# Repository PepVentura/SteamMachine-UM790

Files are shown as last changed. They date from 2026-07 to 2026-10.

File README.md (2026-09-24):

# SteamMachine-UM790
Proyecto de Steam Machine casera funcional
Diseño de carcasa 3D personalizada para convertir un mini PC **Minisforum UM790** en una Steam Machine compacta orientada a gaming, emulación y uso multimedia.

Proyecto desarrollado en **OpenSCAD**, con piezas preparadas para impresión 3D. Incluye también el firmware del ESP32 y el software que corre en el mini PC.

> 👉 **¿Quieres montarlo tú mismo?** Empieza por [`GUIA_INICIO.md`](GUIA_INICIO.md) — guía completa paso a paso, sin conocimientos previos necesarios.

---

## 📷 Galería

Renders reales generados directamente desde el diseño paramétrico
actual del proyecto (OpenSCAD), no maquetas ni imágenes genéricas —
se regeneran cada vez que cambia el CAD, así que siempre reflejan el
estado real de las piezas.

### Carcasa montada, con distintos anagramas de panel NFC

| Steam | RetroBat | En blanco |
|---|---|---|
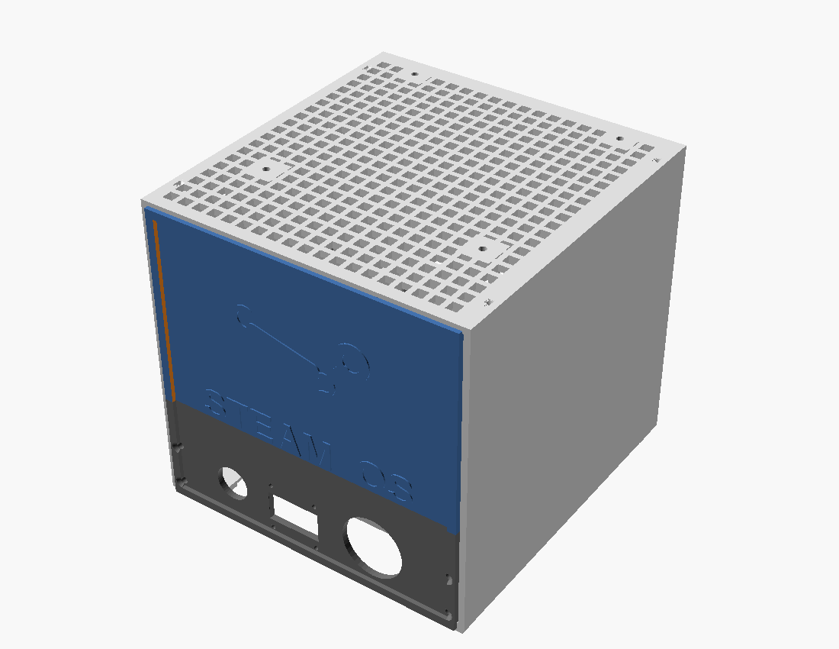
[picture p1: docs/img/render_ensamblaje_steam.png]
Ensamblaje con panel Steam
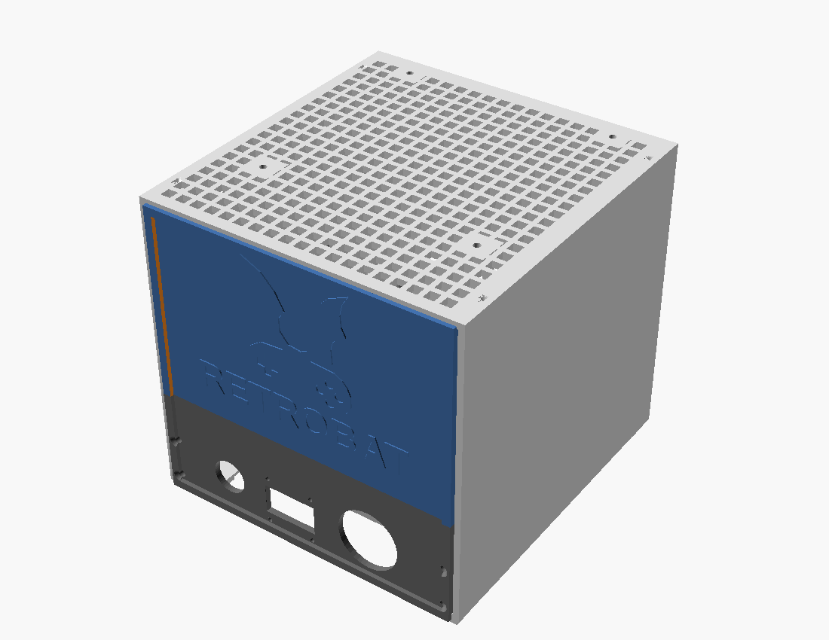
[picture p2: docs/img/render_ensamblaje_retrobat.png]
Ensamblaje con panel RetroBat
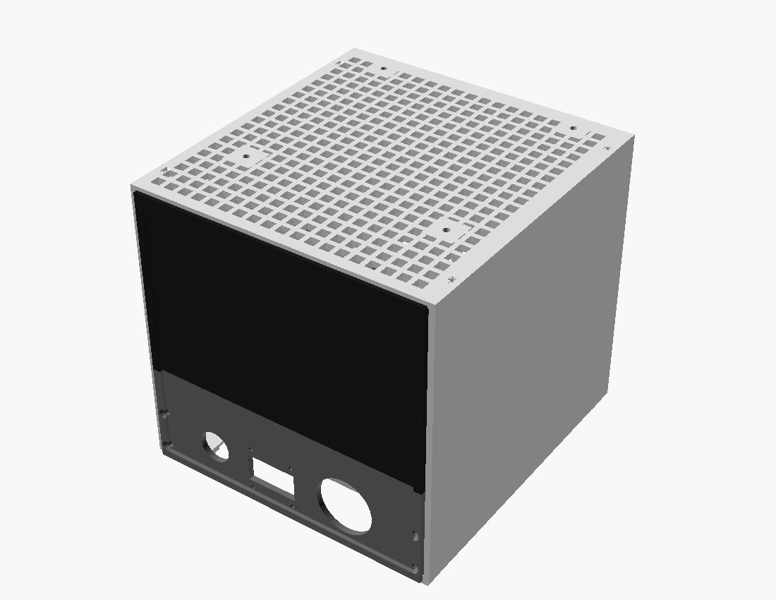
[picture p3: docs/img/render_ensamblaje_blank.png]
Ensamblaje con panel en blanco
|  |  |  |

El panel NFC frontal es intercambiable — el ensamblaje es siempre el
mismo, solo cambia la pieza pequeña con el anagrama (ver `openscad/parts/03_panels/nfc_panel_*.scad`
y el sistema de impresión en dos piezas de `STL/Anagramas/`). El
anagrama del panel Zombies (`STL/Anagramas/Gung.stl`) todavía no tiene
un `.scad` paramétrico propio como los de arriba —está modelado
directamente como STL suelto—, así que de momento no aparece en este
render conjunto.

### Piezas por separado

| Chasis | Panel superior (rejilla) |
|---|---|
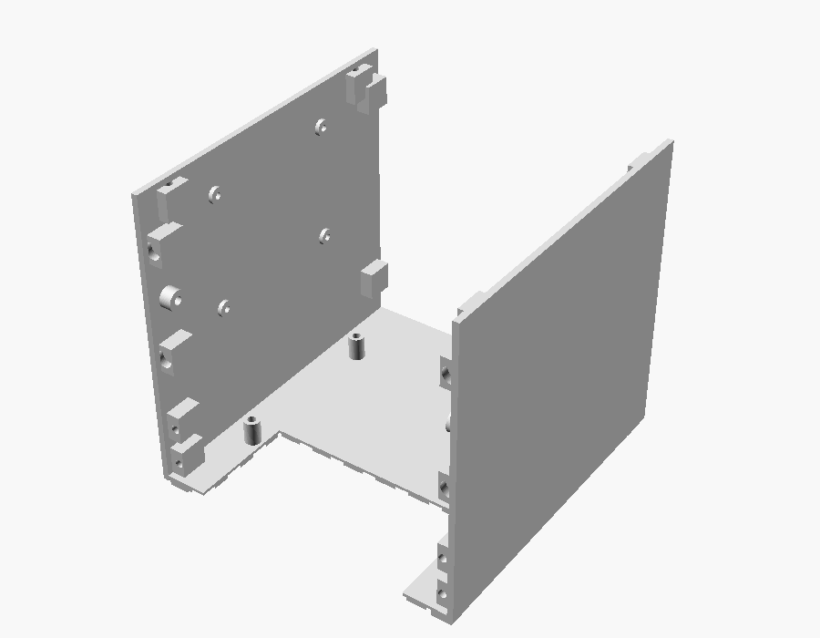
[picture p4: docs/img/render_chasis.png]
Chasis
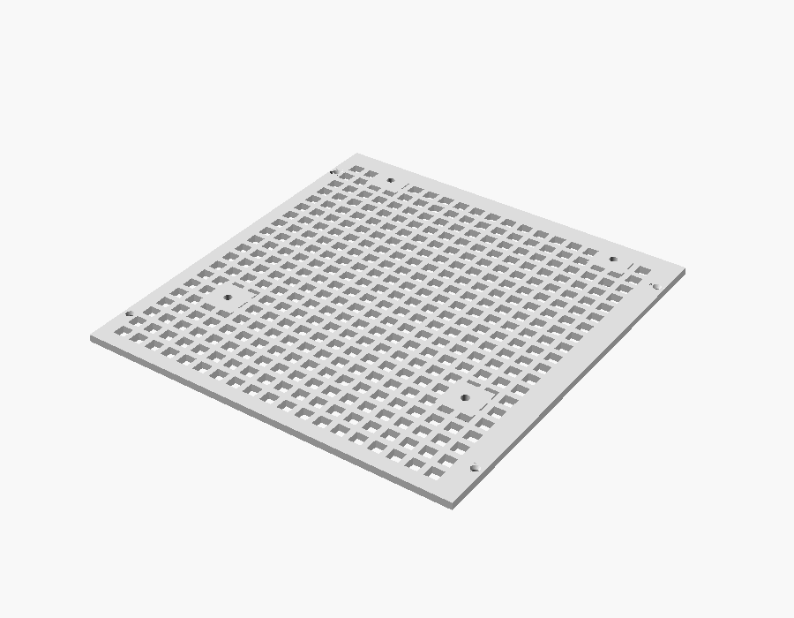
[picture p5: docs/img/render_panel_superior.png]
Panel superior
|  |  |

| Panel inferior (frontal, con OLED/botón/USB) | Panel trasero |
|---|---|
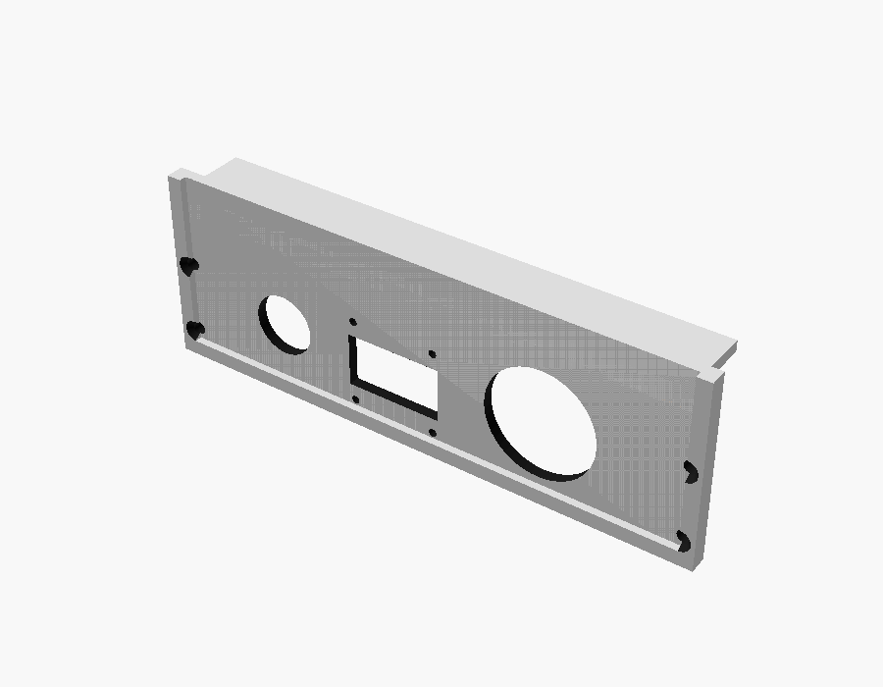
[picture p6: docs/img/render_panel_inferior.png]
Panel inferior
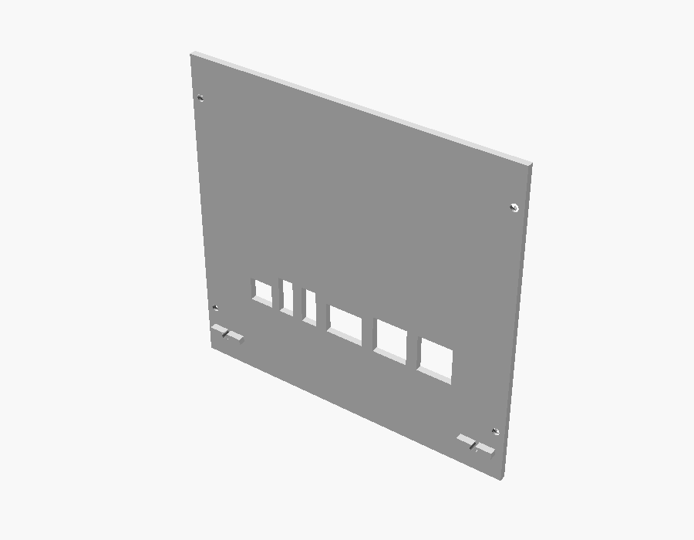
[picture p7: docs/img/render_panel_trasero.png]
Panel trasero
|  |  |

| Bandeja interior |
|---|
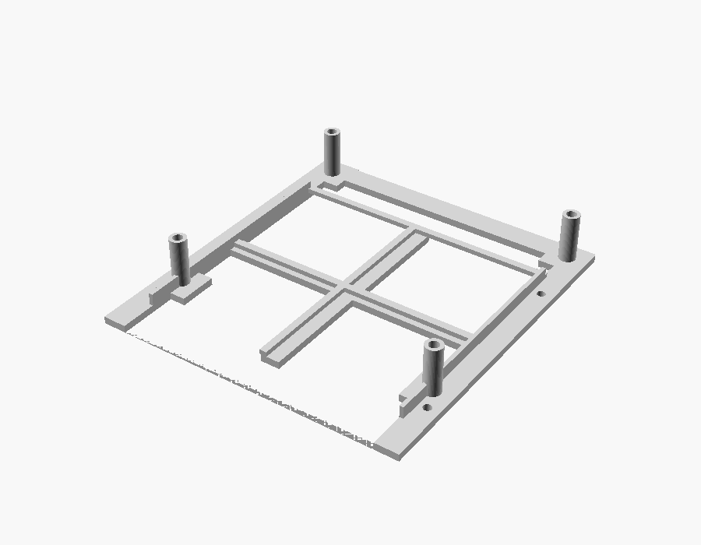
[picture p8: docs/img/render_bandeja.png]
Bandeja
|  |

---

## 📌 Características

- Carcasa modular diseñada específicamente para UM790.
- Diseño paramétrico en OpenSCAD.
- Piezas separadas para facilitar la impresión.
- Optimizada para impresoras FDM.
- Preparada para montaje con tornillería estándar.
- Ventilación integrada para mantener temperaturas adecuadas.
- Diseño orientado a estética tipo consola Steam Machine.
- Sistema de paneles frontales intercambiables.
- Identificación NFC para cambio de modo.
- Panel NFC **Apagar**: apagado ordenado del equipo (evita cortar la corriente de golpe).
- Caja con tapa para guardar los paneles NFC cuando no están puestos.
- Diseño preparado para expansión con nuevos paneles.

## 🎮 Sistema de paneles frontales NFC

Uno de los elementos principales del diseño es el sistema de paneles frontales intercambiables mediante identificación NFC.

La carcasa permite utilizar diferentes paneles frontales personalizados, cada uno asociado a una función, sistema o configuración concreta mediante etiquetas NFC integradas.

### Funcionamiento

Cada panel frontal incorpora:

- Un diseño físico específico según la temática.
- Una etiqueta NFC integrada en el propio panel.
- Identificación automática al acercar el dispositivo lector NFC.
- Posibilidad de lanzar diferentes configuraciones o aplicaciones según el panel utilizado.

Ejemplos de uso:

- 🎮 Panel Steam Machine → inicia Steam Big Picture.
- 🕹️ Panel Arcade → inicia RetroDECK / RetroArch.
- 🧟 Panel Zombies → THE HOUSE OF THE DEAD: Remake / THE HOUSE OF THE
  DEAD 2: Remake (nativos de Steam vía Proton — pensado para jugarse
  con Wiimote como pistola, integración pendiente).
- ⚙️ Panel Configuración → acceso a herramientas del sistema.
- 🎵 Panel Multimedia → reproducción multimedia.
- ⏻ Panel Apagar → apaga el equipo de forma ordenada (ver más abajo).

---

## 🔌 Integración NFC

El sistema está pensado para trabajar con un lector NFC conectado al equipo.

Flujo de funcionamiento:

Las etiquetas NFC pueden programarse para ejecutar diferentes acciones:

- Abrir aplicaciones.
- Ejecutar scripts.
- Cambiar perfiles.
- Lanzar emuladores.
- Seleccionar diferentes modos de uso.

---

## ⏻ Apagado ordenado con el panel Apagar

Cortar la corriente de golpe puede dejar Bazzite sin arrancar (por
ejemplo, en el prompt `grub>`; ver [`GUIA_INICIO.md`](GUIA_INICIO.md),
solución de problemas). Para evitarlo hay un panel **Apagar**: se coloca como
cualquier otro y, al pulsar el botón, el equipo se apaga con
`systemctl poweroff` (systemd cierra servicios y desmonta discos antes
de cortar).

1. Coloca el panel Apagar → la OLED muestra `APAGAR EQUIPO` y los LEDs
   se ponen rojos. **Todavía no se ha apagado nada.**
2. Pulsa el botón → la OLED pasa a `Apagando...`, los LEDs se
   funden a negro y el equipo se apaga en unos segundos.

Son dos gestos a propósito: un roce del tag no apaga la máquina. Si el
sistema rechaza el apagado (p. ej. una actualización en curso), la OLED
muestra `Error al apagar` y el equipo sigue encendido. Detalles en
[`docs/12_Profile_System.md`](docs/12_Profile_System.md).

---

## 🧩 Diseño modular

Los paneles frontales están diseñados para poder sustituirse fácilmente:

- Sistema de fijación común.
- Compatibilidad con futuros diseños.
- Personalización mediante impresión 3D.
- Posibilidad de crear paneles temáticos.

El objetivo es que la SteamMachine pueda cambiar de función simplemente sustituyendo el panel frontal.

---

## 🖨️ Impresión 3D

### Impresora recomendada

Compatible con:

- Anycubic Kobra X
- Impresoras FDM con volumen similar

### Material: PETG

**Todas las piezas se imprimen en PETG.** El PLA (incluido el PLA+) se
deforma con la temperatura: la carcasa envuelve un mini PC que expulsa
aire caliente y el PLA se ablanda alrededor de los 55-60 °C, mientras
que el PETG aguanta hasta unos 70-80 °C (valores orientativos; varían
según la marca de filamento). Con PLA se ha comprobado que las piezas
se deforman en uso real.

- **PETG**: todas las piezas de la carcasa, los paneles frontales y los
  soportes. La caja de paneles NFC (`docs/14_Caja_Paneles_NFC.md`) no
  recibe calor de la máquina, así que PLA sería válido para ella, pero
  se recomienda PETG por coherencia.
- **PLA / PLA+**: solo para pruebas rápidas de encaje. No dejes una
  pieza de PLA montada dentro del equipo.
- **ABS/ASA**: opcional, si quieres más margen térmico todavía (más
  difícil de imprimir: cerramiento y ventilación).
- **Piezas a dos filamentos** (panel inferior, difusor LED translúcido):
  los dos filamentos deben ser PETG. Mezclar PLA y PETG en la misma
  pieza da una unión mala entre capas.
- **Anagramas pegados con Loctite**: el cianoacrilato agarra algo peor
  sobre PETG que sobre PLA. Lija ligeramente las dos caras, desengrasa
  con alcohol isopropílico y pega; si aun así se despega, usa epoxi
  de 5 minutos.
- Las holguras y encajes del diseño se ajustaron con PLA+. Con PETG
  revisa los encajes antes de montar (ver `docs/14_Caja_Paneles_NFC.md`
  para la caja y la tapa).

### Parámetros orientativos

- Altura de capa: 0,20 mm
- Paredes: 3-4 perímetros
- Relleno: 15-30 %
- Soportes: según pieza
- Temperaturas típicas de PETG: boquilla 230-250 °C, cama 70-85 °C,
  ventilador de capa bajo (30-50 %). Parte del perfil PETG de tu
  marca de filamento y ajusta; los puentes salen algo peor que en PLA.

---

## 📂 Estructura del proyecto

```
SteamMachine-UM790/
│
├── GUIA_INICIO.md          Guía paso a paso para montarlo todo, de cero
├── CHANGELOG.md            Historial completo de decisiones de diseño
│
├── openscad/               Diseño 3D paramétrico
│   ├── parts/               Piezas por imprimir (chasis, paneles...)
│   └── reference/            Componentes y posiciones del ensamblaje
├── STL/                    STL listos para imprimir
│   ├── caja_nfc_panel_*.stl  Caja + tapa para guardar los paneles NFC
│   └── Anagramas/            Panel NFC en blanco + anagramas sueltos,
│                              para imprimir por separado y pegar con
│                              Loctite (reduce el tiempo de impresión
│                              de ~6h a ~1h frente a la pieza única)
│
├── firmware/                Firmware del ESP32 (C++, PlatformIO)
├── software/                 Core en Python — corre en el mini PC
│
├── Hardware/                 Conexiones eléctricas y cableado
└── docs/                     Documentación técnica detallada (01 a 14)
```

---

## 🛠️ Software utilizado

- OpenSCAD  
  https://openscad.org/

- Cura / OrcaSlicer / PrusaSlicer para laminado.
- PlatformIO (VS Code) para el firmware del ESP32.
- Python 3 para el Core que corre en el mini PC.

---

## ⚙️ Personalización

El diseño utiliza parámetros editables para modificar:

- Dimensiones generales.
- Posición del equipo.
- Grosor de paredes.
- Ventilación.
- Anclajes.
- Compatibilidad con diferentes accesorios.

Archivo principal: `openscad/00_parametros.scad`

---

## 🚀 Estado del proyecto

🟢 Hardware montado y en pruebas

### Completado

- [x] Diseño mecánico completo (carcasa, paneles, canal LED, fijación OLED).
- [x] Hardware montado (ESP32, RC522, OLED, barra LED, HUB USB).
- [x] Firmware del ESP32 escrito, compilado y flasheado en hardware real.
- [x] Software Core (Python) escrito, con tests unitarios.
- [x] Probado en hardware real: lectura NFC, barra LED, pulsador frontal, pantalla OLED, recuperación tras reinicio del ESP32.
- [x] Core (Python) probado de extremo a extremo contra el ESP32 real: detecta panel, reacciona OLED/LEDs y responde al botón lanzando la plataforma correspondiente.
- [x] Guía de inicio completa para montarlo desde cero (`GUIA_INICIO.md`).
- [x] Panel NFC **Apagar** (apagado ordenado, `docs/12_Profile_System.md`): implementado en el Core con tests; anagrama `STL/Anagramas/Apagar.stl`.
- [x] Caja con tapa para guardar hasta 6 paneles NFC (`docs/14_Caja_Paneles_NFC.md`).
- [x] Publicación de STL definitivos actualizados (incluye `STL/Anagramas/` — panel en blanco + anagramas sueltos para pegar con Loctite).

### Pendiente

- [ ] Panel Apagar: escribir el tag NFC, poner su UID real en `software/config/panel_database.json` (ahora `UID_APAGAR_PENDIENTE`) y probar el apagado en el hardware real (`docs/10_Test_Plan.md`, T065).
- [ ] Reimprimir en PETG las piezas que estén en PLA y validar la temperatura tras 24 h (`docs/10_Test_Plan.md`, T022).
- [ ] Wiimote como pistola para el panel Zombies (Bluetooth + barra de sensor IR).
- [ ] UID de tag NFC real para el panel Zombies - HOTD 2 Remake.

Ver `docs/10_Test_Plan.md` para el detalle de cada prueba realizada, y
`docs/06_Development_Roadmap.md` para el estado por fases.

---

## 🤝 Contribuciones

Las mejoras, modificaciones y sugerencias son bienvenidas.

Si realizas una modificación o adaptación, puedes abrir un Pull Request.

---

## Autor

Pep Ventura

Proyecto creado para uso personal y compartido con la comunidad maker.

## Licencia

Este proyecto está bajo la **Licencia MIT**. Esto significa que puedes usar, modificar y distribuir el código libremente, incluso para fines comerciales. 

Para más detalles, consulta el archivo [LICENSE](LICENSE) incluido en este repositorio.

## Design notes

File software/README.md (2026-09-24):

# SteamMachine Software Core v0.2

Aplicacion Python que corre en el mini PC (Bazzite) y coordina el ESP32
(paneles NFC + boton + OLED + LEDs) con el lanzador de plataformas
(Steam, RetroDECK, RetroArch, y el panel de zombies/disparos con THE
HOUSE OF THE DEAD: Remake y THE HOUSE OF THE DEAD 2: Remake, ambos
nativos de Steam via Proton) y, con el panel Apagar, apaga el equipo de
forma ordenada. Arquitectura y protocolo: ver `docs/03`,
`docs/04`, `docs/05`, `docs/08` en la raiz del repo.

## Instalar

```bash
cd software
python3 -m venv .venv
source .venv/bin/activate
pip install -r requirements.txt
```

## Ejecutar con el ESP32 real (hardware ya montado)

`config/config.json` tiene `"serial.simulate": false` por defecto: al
arrancar busca el ESP32 automaticamente por VID:PID (`"port": "auto"`).

```bash
python main.py
```

Si no lo encuentra, localiza el puerto a mano en Bazzite:

```bash
ls /dev/serial/by-id/     # busca algo como usb-1a86_USB_Serial-if00-port0
```

y ponlo explicitamente en `config/config.json`:

```json
"serial": { "port": "/dev/ttyUSB0", "simulate": false }
```

Antes de dar por buena una sesion con hardware real, sigue el checklist
de `firmware/README.md` ("Prueba de integracion") para confirmar que el
propio firmware responde bien por su cuenta.

Con `"simulate": false` el Core espera al ESP32 real: si no esta
conectado o no responde con `boot`, veras avisos de reconexion en el
log (`logs/steammachine.log`) cada `serial.reconnect_interval_seconds`.

## Ejecutar en modo simulado (sin ESP32, para desarrollo)

Util para tocar la logica del Core sin depender del hardware. Pon
`"serial.simulate": true` en `config/config.json` y ejecuta `python
main.py`: se abre una consola interactiva.

```
sim> 04A1C8B2      # simula "colocar panel Steam"
sim> b             # simula pulsar el boton -> lanza Steam
sim> r             # simula "retirar panel"
sim> q             # salir
```

Los UID de ejemplo (Steam / RetroDECK / Zombies-HOTD Remake /
Zombies-HOTD 2 Remake) estan en `config/panel_database.json` — si tus
tags reales tienen otros UID, actualiza ese fichero con los que
reporte el firmware al leerlos (ver el checklist de
`firmware/README.md`). El UID del panel de HOTD 2 Remake
(`0AAABBCC`) es un placeholder: sustituyelo por el UID real en cuanto
tengas un segundo tag/panel fisico asignado a ese juego; hasta
entonces, el panel de zombies (`04C3EAD4`) lanza HOTD Remake.

## Panel Apagar (apagado ordenado)

El perfil `APAGAR` (`config/profiles/apagar.json`, `"action": "poweroff"`)
apaga el mini PC con `systemctl poweroff` al pulsar el boton con el panel
puesto (`core/power_manager.py`). El comando se puede cambiar en
`config/config.json`:

```json
"power": { "poweroff_command": ["systemctl", "poweroff"] }
```

- **Sin sudo**: en la sesion grafica local activa (la del servicio de
  usuario `steammachine.service`) polkit permite apagar sin contrasena.
  Compruebalo una vez a mano con `systemctl poweroff`.
- Si el sistema rechaza el apagado (p. ej. bloqueo por una actualizacion
  de Bazzite; `systemd-inhibit --list` muestra quien bloquea), la OLED
  muestra `Error al apagar` y el motivo queda en el log.
- **Modo simulado (`serial.simulate: true`)**: el apagado NUNCA se
  ejecuta, solo se registra (`SIMULACION: apagado solicitado pero NO
  ejecutado`). Asi teclear el UID del panel Apagar en la consola de
  simulacion no apaga tu maquina de desarrollo.
- La entrada del panel en `panel_database.json` se llama
  `UID_APAGAR_PENDIENTE`: sustituyela por el UID real del tag. Debe
  conservar `"profile": "APAGAR"`; sin el perfil el boton no hace nada.
- Mientras dura el apagado el Core ignora paneles, boton y AUTO, para que
  retirar el panel no deshaga el aviso `Apagando...`.

## Arranque automático (systemd)

Para que el Core arranque solo con la sesión gráfica de Bazzite, sin
tener que abrir una terminal cada vez (pensado para el uso "aparato",
incluida la segunda residencia):

```bash
mkdir -p ~/.config/systemd/user
cp steammachine.service ~/.config/systemd/user/
systemctl --user daemon-reload
systemctl --user enable --now steammachine.service
```

Comprobar estado y logs:

```bash
systemctl --user status steammachine.service
journalctl --user -u steammachine.service -f
```

`steammachine.service` reinicia el Core solo si se cae (`Restart=on-failure`)
y espera a que el escritorio gráfico esté listo antes de arrancar. Editar
`ExecStart`/`WorkingDirectory` si tu ruta de instalación no es `~/SteamMachine-UM790/software`.

## Tests

```bash
pip install -r requirements-dev.txt
pytest
```

Cubren `LEDManager` y `OLEDManager` (comandos directos, `flash`/`fade` y su
cancelacion mutua, y la aproximacion de `sleep`/`wake`), `Application`
(logica de los eventos del protocolo — tag, tag_removed, button — con
`OLEDManager`/`LEDManager`/`Launcher`/`PanelDatabase` sustituidos por
dobles), `PanelDatabase` (carga/guardado, JSON malformado, mayus/minus
en el UID) `PowerManager` (apagado ordenado: exito, rechazo del sistema, comando
inexistente, timeout, `dry_run` — con procesos `python -c` en vez de
`systemctl poweroff`, que apagaria la maquina de los tests), el flujo
APAGAR de `Application` y `Launcher`/`BasePlugin` (lanzar, parar y consultar estado
de procesos reales de corta duracion — se usa `python -c "..."` en vez
de steam/flatpak/lutris, que no estan instalados en este entorno).

Todo con dobles (`tests/fakes.py`) o ficheros temporales — no hace falta
hardware, ESP32 ni las plataformas reales para correrlos.

## Estructura

```
core/        Application, ConfigurationManager, EventManager, logger,
             ProfileManager (config/profiles/*.json), ProcessWatcher
             (detección de perfil AUTO por proceso en ejecución),
             PowerManager (apagado ordenado, panel APAGAR)
devices/     SerialManager (real) / SimulatedSerialManager, ESP32Controller
database/    PanelDatabase (config/panel_database.json)
launcher/    BasePlugin + SteamPlugin, RetroDeckPlugin, RetroArchPlugin,
             HotdRemakePlugin, Hotd2RemakePlugin
status/      StatusManager (registro), BaseStatusProvider, SystemStatsProvider
             (CPU/RAM vía psutil — usado por el perfil MAINTENANCE)
config/      config.json, panel_database.json, profiles/*.json
```

## Pendiente

- Validar con hardware real (ver checklist en `firmware/README.md`,
  "Prueba de integración") — todo lo de arriba está probado con el
  ESP32 simulado, no con el físico.
- Panel Apagar: poner el UID real de su tag (ahora `UID_APAGAR_PENDIENTE`)
  y probar el apagado en el hardware real — solo esta probado con el
  ESP32 simulado y con tests, no con `systemctl poweroff` real.
- Actualizar `config/panel_database.json` con los UID reales de tus
  tags NFC en cuanto los leas del firmware (ahora mismo tiene UID de
  ejemplo).
- Persistir `_pending_panel` no es necesario (se resetea con cada tag),
  pero si se añade reconexion en caliente conviene revisar ese estado.
- Zumbador y actualizaciones OTA: sin implementar todavía (ver roadmap,
  Fase 10).
- Wiimote como lightgun (Bluetooth + barra de sensor IR) para el panel
  de zombies: pospuesto, sin implementar todavía. Los juegos (HOTD
  Remake / HOTD 2 Remake) ya funcionan con raton normal mientras tanto.

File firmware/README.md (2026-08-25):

# SteamMachine UM790 - Firmware ESP32

Firmware para el ESP32-WROOM-32D DevKit (HW-394) que controla el RC522,
la OLED, la barra LED y el pulsador, y habla el protocolo JSON de
`docs/04_Communication_Protocol.md` con el Core (`software/`).
Arquitectura: `docs/05_Firmware_Architecture.md`.

> **Validado en hardware real**: compila (con `fastled/FastLED` fijado
> a `3.7.8` en `platformio.ini` — versiones más recientes tienen un
> fallo de compilación conocido, ver "Solución de problemas" en
> `GUIA_INICIO.md`), flashea y arranca correctamente en un
> ESP32-WROOM-32D DevKit real; el evento `boot` se confirmó por
> monitor serie. Pendiente de validar el RC522, la OLED, la barra LED
> y el pulsador con el cableado completo (ver checklist más abajo).

## Compilar y flashear

Requiere [PlatformIO](https://platformio.org/) (extension de VSCode o CLI):

```bash
cd firmware
pio run                # compila
pio run --target upload -e esp32doit-devkit-v1   # flashea (con el ESP32 en modo bootloader si hace falta)
pio device monitor -b 115200                       # monitor Serial (protocolo JSON; ver nota abajo)
```

> Ojo: `pio device monitor` te va a mostrar el trafico JSON crudo del
> protocolo, no logs de depuracion (esos van por Serial2, ver mas abajo).

## Depuracion

`Serial` (USB) esta reservado en exclusiva para el protocolo con el PC.
Los logs de depuracion van por `Serial2` (pines 16/17 por defecto,
`config.h`), y solo se compilan si activas el flag:

```ini
build_flags = -DDEBUG_SERIAL2=1
```

en `platformio.ini`. Con un adaptador USB-serie en los pines 16/17
puedes ver los logs sin tocar el canal del protocolo.

## Pinout (fijado por el diseño electrónico)

`docs/07_Hardware_Specification.md` no fijaba GPIOs, así que la
asignación real vive en `src/config.h`. El resto de GPIO del
ESP32-WROOM-32D DevKit quedan reservados sin usar todavía.

| Función | Pin(es) |
|---|---|
| RC522 SDA/SS | GPIO5 |
| RC522 SCK | GPIO18 |
| RC522 MISO | GPIO19 |
| RC522 MOSI | GPIO23 |
| RC522 RST | GPIO27 |
| OLED SDA | GPIO21 |
| OLED SCL | GPIO22 |
| Barra LED (WS2812B, directa sin nivelador) | GPIO25 (`LED_COUNT` a ajustar) |
| Pulsador | GPIO13 (confirmado en hardware real, 2026-08-25) |
| Zumbador (futuro) | GPIO26 (provisional — no fijado en el diseño electrónico) |
| Debug Serial2 | RX 16, TX 17 (provisional) |

**Alimentación:**

| Riel | Alimenta |
|---|---|
| 3V3 | RC522 + OLED |
| VIN (~4.68V)  | WS2812B |
| GND | masa común |

El dato de la barra LED sale del ESP32 en 3.3V (GPIO25) y va **directo**
a la WS2812B, sin nivelador — el diseño original preveía un 74AHCT125
(3.3V→5V) de por medio, pero se retiró (2026-08-25) tras comprobar en
un tramo real de 8 LEDs que la tira funciona bien sin él: con el chip
en el circuito no encendía nada (causa más probable: el pin /1OE
flotante), y conectado directo sí. Ver
`Hardware/Hardware_Connections.md` para el historial completo de este
diagnóstico.

Los únicos pines que aún no vienen confirmados en hardware real son el
zumbador y el UART de depuración; están marcados como "provisional" en
`config.h` — confírmalos o cámbialos cuando lo tengas claro.

**Cable y código de colores** (ver `docs/07_Hardware_Specification.md`,
sección "Cableado"): 22 AWG / 0,32 mm², cobre estañado, aislamiento de
silicona. Rojo = +5V, Negro = GND, Amarillo = datos/señales, Azul =
SPI (RC522), Verde = I²C (OLED).

## Estructura

Sigue exactamente `docs/05_Firmware_Architecture.md`:

```
src/
  main.cpp
  config.h
  core/            Application (orquesta todo), EventQueue
  hardware/        rc522, oled, leds, button (un modulo = una responsabilidad)
  communication/    serial_protocol (transporte), json_parser (parseo de comandos)
  services/        animations (motor no bloqueante), diagnostics, watchdog
  utils/           logger (Serial2), timers (Every, basado en millis())
```

## Animaciones

`services/animations.h` implementa los 7 nombres de `docs/04`
(idle, loading, launch, rainbow, error, success, shutdown) como
funciones de un frame cada una, llamadas sin bloquear desde el loop
principal. Un comando `led` (color sólido) o `brightness` cancela
cualquier animación en curso, igual que en el Core (`LEDManager.set_color`
en `software/devices/led_manager.py`).

## Pendiente / no cubierto todavía

- Zumbador (`cmd: beep`): el comando se parsea y no da error, pero no
  hace nada hasta que exista el hardware.
- Sin tests automáticos (el firmware depende de librerías de hardware
  reales — RC522, OLED, FastLED — difíciles de mockear sin más
  infraestructura; se podría plantear un entorno `pio test` nativo con
  dobles de esas librerías si interesa más adelante).
- Compilación, flasheo y arranque ya validados en hardware real
  (ver aviso arriba); pendiente de validar RC522, OLED, LEDs y pulsador
  con el cableado completo.

## Prueba de integración (primera vez con hardware real)

Con el cableado ya montado, antes de dar por buena la Fase 9 del roadmap:

1. `pio run` — compila. ✔ Validado en un ESP32-WROOM-32D DevKit real.
2. `pio run --target upload -e esp32doit-devkit-v1` — flashea el ESP32. ✔ Validado.
3. `pio device monitor -b 115200` — tras el ruido propio del arranque
   del ESP32 (líneas tipo `ets Jul 29 2019...`), deberías ver
   `{"event":"boot","firmware":"1.0.0"}`. ✔ Validado. Si además ves
   `{"event":"error","code":1}`, el RC522 todavía no responde — normal
   si no está cableado aún, revisar pinout si ya lo está.
4. Acerca un tag NFC al RC522 → debería aparecer `{"event":"tag","uid":"..."}`
   con un UID de 8 caracteres hex. Retíralo → `{"event":"tag_removed"}`. ✔ Validado.
5. Pulsa el botón → `{"event":"button"}`. ✔ Validado (GPIO13).
6. Desde el mismo monitor, escribe a mano una línea y pulsa Enter para
   probar los comandos PC→ESP32, por ejemplo:
   `{"cmd":"oled","text":"Hola"}` (debe aparecer en la pantalla) ✔ Validado,
   `{"cmd":"led","color":"#00FF00"}` (la barra debe ponerse verde) ✔ Validado (8 LEDs, directo sin nivelador),
   `{"cmd":"animation","name":"rainbow"}`.
7. Solo cuando 3-6 funcionen, pasa a probar con el Core real: en
   `software/config/config.json` pon `"simulate": false` y sigue las
   instrucciones de `software/README.md` para localizar el puerto serie.

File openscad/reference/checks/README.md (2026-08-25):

# Verificación de colisiones — Ensamblaje virtual v1

Comprueba automáticamente, componente contra componente, si los
volúmenes mecánicos del ensamblaje virtual (`virtual_assembly_v1.scad`)
colisionan entre sí.

## Cómo funciona

Para cada par de componentes se calcula `intersection(A, B)` en
OpenSCAD y se exporta el resultado a STL:

- Si el STL resultante está **vacío** → los volúmenes no se tocan →
  **sin colisión**.
- Si el STL contiene triángulos → los volúmenes se solapan
  físicamente → **colisión real**.

Se comprueban dos niveles:

1. **Cuerpos mecánicos rígidos** (`*InstanceBody`): cualquier
   intersección aquí es un fallo bloqueante — dos piezas físicas no
   pueden ocupar el mismo espacio.
2. **Volúmenes de seguridad / cableado** (`*InstanceKeepout`) contra
   cuerpos de *otros* componentes: es un aviso informativo, no un
   fallo. Indica que conviene revisar cómo se enruta el cableado en
   ese punto, no que dos piezas sólidas choquen.

Ambas comprobaciones usan las mismas posiciones que el ensamblaje
visual (`openscad/reference/components/assembly_positions.scad` y
`assembly_instances.scad`), así que el resultado del render y el de
la comprobación son siempre coherentes entre sí.

## Uso

```bash
cd openscad/reference/checks
python3 run_collision_checks.py
```

Requiere el binario `openscad` en el `PATH`. Los archivos `.scad` y
`.stl` intermedios se generan en `_generated/` (no se versionan, ver
`.gitignore`).

## Último resultado conocido

Ver `docs/Virtual_Assembly_Report.md` para el resultado de la
última ejecución y su interpretación.

## Añadir un componente nuevo

1. Crear su módulo en `openscad/reference/components/`.
2. Añadir su posición a `assembly_positions.scad`.
3. Añadir su `*InstanceBody()` (y `*InstanceKeepout()` si aplica) a
   `assembly_instances.scad`.
4. Añadirlo a la lista `COMPONENTS` (y `KEEPOUTS` si aplica) en
   `run_collision_checks.py`.

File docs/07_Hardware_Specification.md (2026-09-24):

\# SteamMachine UM790

\# 07 - Hardware Specification

Version: 1.0

Status: Active

\---

\# Objetivo

Este documento recoge las especificaciones técnicas completas del hardware utilizado en el proyecto SteamMachine UM790.

Su finalidad es servir como referencia única durante el diseño mecánico, el desarrollo del firmware y el montaje final.

\---

\# 1. Equipo principal

\## Mini PC

Modelo

Minisforum UM790 Pro

Función

Equipo principal de ejecución.

\### Dimensiones mecánicas

PCB

122.0 × 119.5 mm

Altura aproximada

38 mm

Separación recomendada respecto a la base

12 mm

Sistema de fijación

4 soportes M3

\---

\# 2. Ventilación

\## Ventilador principal

Modelo

Noctua NF-A12x15 PWM chromax.black.swap

Características

120 × 120 × 15 mm

PWM 4 pines

Muy bajo nivel sonoro

Posición

Parte superior del equipo

Centrado respecto al disipador del UM790

Flujo

Entrada por la base

Salida por la tapa

\---

\# 3. Controlador

\## ESP32 Terminal Adapter

Dimensiones

78 × 63 mm

Taladros

73 × 58 mm

Tornillería

M3

Función

Control completo del frontal

\- RC522

\- OLED

\- LEDs

\- Pulsador

\- Comunicación USB Serie

\---

\# 4. Lector NFC

Modelo

MFRC522

Interfaz

SPI

Función

Lectura de paneles NFC intercambiables

Posición

Centrado horizontalmente

A media altura del panel frontal superior

El soporte pertenece al chasis, no al panel intercambiable.

\---

\# 5. Pantalla

Modelo

OLED I²C

Zona visible

27 × 27 mm

Función

Estado del sistema

Plataforma seleccionada

Mensajes

Animaciones

\---

\# 6. Pulsador

Tipo

Metálico antivandálico

Rosca

16 mm

Longitud roscada

55 mm

Montaje

Panel frontal

\---

\# 7. USB frontales

Tipo

Prolongadores USB empotrables

Diámetro del orificio

29 mm

Cantidad

2

Conexión

USB HUB interno

\---

\# 8. HUB USB

Modelo

USB 3.x de 4 puertos

Posición

Lateral interior

Conexión

UM790

↓

HUB

↓

USB frontales

\---

\# 9. Barra LED

Tipo

RGB direccionable

Control

ESP32

Funciones

Color por plataforma

Animaciones

Estado

Errores

\---

\# 10. Paneles intercambiables

Material

PETG (el PLA se deforma con la temperatura del equipo)

Sistema de fijación

Imanes de neodimio

Alojamiento NFC

Empotrado

Contenido

Logotipo en relieve

Tag NFC

\---

\# 11. Imanes

Disponibles

3 × 2 mm

6 × 2 mm

Aplicación

Panel frontal

Paneles intercambiables

\---

\# 12. Insertos roscados

Disponibles

M2

M2.5

M3

M4

M5

M6

M8

Aplicaciones

Panel trasero

Bastidor

Soportes

\---

\# 13. Tornillería prevista

M2

Electrónica

M3

ESP32

UM790

Ventilador

Bastidor

M4

Panel trasero (si fuese necesario)

\---

\# 14. Fuente de alimentación

Tipo

Externa

Ventajas

Menor temperatura interior

Más espacio disponible

Mayor facilidad de mantenimiento

\---

\# 15. Carcasa

Dimensiones exteriores

Anchura

156 mm

Profundidad

162.4 mm

Altura

148 mm

Altura total con patas

152 mm

\---

\# 16. Refrigeración

Entrada

Base

Salida

Parte superior

Ventilador

Noctua NF-A12x15

Objetivo

Mantener una circulación vertical continua.

\---

\# 17. Materiales de impresión

Material obligatorio (todas las piezas)

PETG

PLA / PLA+

Solo pruebas de encaje. No montar dentro del equipo: se ablanda a ~55-60 °C y se deforma en uso real.

ABS / ASA (opcional)

Más margen térmico, más difícil de imprimir.

Piezas a dos filamentos

Ambos filamentos en PETG.

Pegado de anagramas

El cianoacrilato agarra peor en PETG: lijar, desengrasar; epoxi si se despega.

Altura de capa

0.20 mm

Boquilla

0.4 mm

\---

\# 18. Impresora

Modelo

Anycubic Kobra X

Área útil

Suficiente para imprimir todas las piezas sin dividirlas.

\---

\# 19. Objetivos mecánicos

\- Fácil mantenimiento.

\- Cableado ordenado.

\- Buena ventilación.

\- Acceso directo al panel trasero.

\- Paneles NFC intercambiables.

\- Bastidor rígido.

\- Sin interferencias entre componentes.

\---

\# 20. Cableado

Cable 22 AWG / 0,32 mm², cobre estañado, aislamiento de silicona.

Código de colores (5 colores, para mantener el cableado organizado en
todo el montaje — especialmente entre RC522, OLED, WS2812B y ESP32):

| Color | Se reserva para |
|---|---|
| Rojo | +5V |
| Negro | GND |
| Amarillo | Datos / señales |
| Azul | SPI |
| Verde | I²C |

\---

\# 21. Estado

Especificaciones mecánicas prácticamente completas.

Este documento deberá actualizarse únicamente cuando se incorporen nuevos componentes físicos.

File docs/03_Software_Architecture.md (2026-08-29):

\# SteamMachine UM790

\# 03 - Software Architecture

Version: 1.0

Status: Draft

\---

\# 1. Objetivo

El software de SteamMachine UM790 tiene como objetivo convertir un MiniPC convencional en un sistema modular de entretenimiento controlado mediante paneles NFC intercambiables.

El usuario únicamente debe:

\- colocar un panel frontal

\- pulsar el botón

Todo el resto será completamente automático.

\---

\# 2. Arquitectura General

```

&#x20;                   +-----------------------+

&#x20;                   |     NFC PANEL         |

&#x20;                   +-----------+-----------+

&#x20;                               |

&#x20;                               |

&#x20;                         RC522 Reader

&#x20;                               |

&#x20;                               |

&#x20;                       ESP32 Controller

&#x20;                               |

&#x20;                     USB Serial Communication

&#x20;                               |

&#x20;                               |

&#x20;                SteamMachine Core Application

&#x20;                               |

&#x20;        +----------+-----------+-----------+

&#x20;        |          |           |           |

&#x20;    OLED      LED Controller   Launcher   Logger

&#x20;                               |

&#x20;               +---------------+---------------+

&#x20;               |               |               |

&#x20;            Steam         RetroDECK       Zombies (HOTD)

```

\---

\# 3. Componentes

\## ESP32

Responsabilidades

\- Leer el RC522

\- Leer el pulsador

\- Controlar OLED

\- Controlar LEDs

\- Enviar eventos al PC

\- Recibir órdenes del PC

El ESP32 nunca decide qué aplicación ejecutar.

Toda la lógica reside en el PC.

\---

\## SteamMachine Core

Es el proceso principal.

Responsabilidades

\- Inicialización

\- Configuración

\- Gestión de eventos

\- Comunicación con ESP32

\- Carga de perfiles

\- Lanzamiento de aplicaciones

\---

\## Launcher

Responsable de iniciar programas.

Ejemplos

\- Steam

\- RetroDECK

\- Zombies (HOTD Remake, via Steam)

Cada plataforma tendrá su propio módulo.

\---

\## OLED Manager

Muestra

\- Plataforma seleccionada

\- Estado

\- Errores

\- Animaciones

\- Información de carga

\---

\## LED Manager

Controla

\- Color

\- Intensidad

\- Animaciones

\- Efectos

Ejemplos

Steam → Azul

RetroDECK → Morado

Zombies (HOTD Remake) → Rojo

Bazzite (reposo) → Azul

\---

\## NFC Database

Relaciona UID con plataforma.

Ejemplo

UID

↓

Steam

↓

Icono

↓

Color LED

↓

Aplicación

\---

\# 4. Flujo de funcionamiento

```

Insertar panel NFC

↓

RC522 detecta UID

↓

ESP32 envía UID

↓

Core recibe UID

↓

Busca perfil

↓

Actualiza OLED

↓

Actualiza LEDs

↓

Espera pulsador

↓

Lanza aplicación

```

\---

\# 5. Comunicación ESP32 ↔ PC

Comunicación

USB Serial

115200 bps

Formato

JSON

Ejemplos

ESP32 → PC

```json

{

&#x20;   "event":"tag",

&#x20;   "uid":"04A1C8B2"

}

```

```json

{

&#x20;   "event":"button"

}

```

PC → ESP32

```json

{

&#x20;   "oled":"Steam"

}

```

```json

{

&#x20;   "led":"#0055FF"

}

```

```json

{

&#x20;   "animation":"launch"

}

```

\---

\# 6. Base de datos de paneles

Formato

panel\_database.json

Ejemplo

```json

{

&#x20;   "04A1C8B2":

&#x20;   {

&#x20;       "name":"Steam",

&#x20;       "launcher":"steam.py",

&#x20;       "led":"#0055FF",

&#x20;       "icon":"steam.png"

&#x20;   }

}

```

\---

\# 7. Organización del software

```

software/

core/

&#x20;   app.py

&#x20;   config.py

&#x20;   events.py

&#x20;   logger.py

launcher/

&#x20;   launcher.py

&#x20;   steam.py

&#x20;   retrobat.py

&#x20;   teknoparrot.py

&#x20;   rpcs3.py

esp32/

&#x20;   serial\_manager.py

&#x20;   oled.py

&#x20;   leds.py

&#x20;   nfc.py

&#x20;   button.py

database/

&#x20;   panel\_database.json

resources/

&#x20;   icons/

&#x20;   fonts/

&#x20;   sounds/

```

\---

\# 8. Filosofía del proyecto

El ESP32 es únicamente un periférico inteligente.

Toda la lógica reside en el PC.

Esto permite:

\- actualizar el software sin modificar el firmware

\- añadir plataformas sin reprogramar el ESP32

\- mantener el firmware extremadamente simple

\---

\# 9. Objetivos futuros

\- Actualizaciones OTA del ESP32

\- Plugins para nuevos emuladores

\- Gestión automática de perfiles

\- Integración con Home Assistant

\- API REST

\- Aplicación móvil

\- Sincronización con GitHub

\---

\# Estado

Documento en desarrollo.

Será actualizado conforme avance el proyecto.

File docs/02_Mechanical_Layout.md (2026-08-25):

# SteamMachine UM790
## Mechanical Layout
Version: 1.0
Status: Approved
Date: 2026-08-02

> **Adenda (2026-08-03)**: la separación de separadores del UM790
> (sección 3, "UM790 Pro") se ha actualizado de 8 mm a 20 mm tras la
> verificación con el ensamblaje virtual v1, que encontró una
> colisión real entre el pulsador/USB frontal y la PCB con el valor
> original. Resto del documento sin cambios. Ver
> `docs/Virtual_Assembly_Report.md` para el detalle completo y el
> resultado de la checklist de la sección 8.

SteamMachine UM790 – Documento de Implantación Mecánica (DIM v1.0)
1. Objetivos

La implantación debe garantizar:

Cero interferencias entre componentes.
Flujo de aire vertical eficiente.
Acceso sencillo para mantenimiento.
Modularidad del frontal.
Respeto de las dimensiones originales de la Steam Machine.
2. Dimensiones exteriores (congeladas)
Parámetro	Valor
Anchura	156 mm
Profundidad	162,4 mm
Altura del cuerpo	148 mm
Altura total con patas	152 mm

Estas dimensiones no se modificarán.

3. Componentes principales
UM790 Pro

Elemento principal.

Se colocará centrado respecto al chasis.

Orientación:

Conectores originales hacia el panel trasero.

Separación respecto a la base:

20 mm mediante separadores (actualizado 2026-08-03 — ver
docs/Virtual_Assembly_Report.md; el valor original de 8 mm no
dejaba hueco suficiente detrás del panel frontal para el pulsador
(M16×55) ni el USB empotrable sin chocar con la PCB o sus postes de
anclaje).

Ventilador

Noctua NF-A12x15

120×120×15 mm

Se situará exactamente encima del UM790.

No desplazado.

La tapa superior tendrá una gran rejilla centrada.

RC522

Posición:

Detrás del panel NFC superior.

No irá fijado al panel.

Quedará suspendido mediante dos soportes laterales integrados en el bastidor.

Separación al panel:

3 mm.

Panel NFC

Ocupará prácticamente todo el ancho frontal.

Llevará:

logotipo en relieve.
alojamiento posterior para el tag NFC.

Será completamente intercambiable.

Panel inferior

Una sola pieza.

Contendrá:

pulsador.
OLED.
USB.
barra LED.

No soportará electrónica.

Toda la electrónica irá en el bastidor.

ESP32

Situado en el lateral izquierdo.

Motivos:

cerca del RC522.
cerca del OLED.
cerca del LED.

Montaje:

4 separadores M3.

Insertos térmicos.

HUB USB

Situado en el lateral derecho.

No alineado con el frontal.

Los USB frontales serán los empotrables de Ø29 mm.

USB empotrable

Montaje:

Frontal.

Taladro Ø29 mm.

Conectado mediante cables USB al HUB.

Pulsador

Situado a la izquierda.

Rosca:

M16.

Longitud:

55 mm.

Quedará totalmente libre por detrás.

OLED

Situado aproximadamente centrado.

Ventana:

27×27 mm.

Montaje sobre soporte independiente.

4. Cableado

Quedará dividido en dos zonas.

Lado izquierdo
ESP32
RC522
OLED
LED
Lado derecho
HUB
USB
alimentación interna

No habrá cruces sobre el UM790.

5. Flujo de aire

Entrada:

Base.

Paso:

UM790.

Salida:

Ventilador Noctua.

Tapa superior.

No habrá rejillas laterales.

6. Paneles
Superior

Atornillado.

Rejilla ventilación.

Trasero

Atornillado.

Insertos M3.

Panel NFC

Imanes.

Panel inferior

No imanes.

Se fijará mediante tornillos M2 sobre insertos térmicos.

7. Insertos térmicos

M2

panel inferior.

M3

panel trasero.
panel superior.
soportes electrónicos.
front frame.
8. Verificación de colisiones (lista de comprobación)

Antes de modelar el bastidor se verificará:

☐ Pulsador ↔ UM790.
☐ OLED ↔ UM790.
☐ USB frontal ↔ HUB.
☐ RC522 ↔ Ventilador.
☐ RC522 ↔ Panel NFC.
☐ ESP32 ↔ HUB.
☐ Cables USB ↔ Ventilador.
☐ Cables OLED ↔ Ventilador.
☐ Cables RC522 ↔ UM790.
☐ Conector de alimentación UM790 ↔ Panel trasero.
☐ Tornillos ↔ componentes.
☐ Insertos ↔ nervios del bastidor.

> **Adenda (2026-08-03)**: los 10 primeros puntos de esta checklist
> están verificados — sin colisión, incluyendo "RC522 ↔ Panel NFC"
> (con los 3 mm de separación especificados en la sección 3) y
> "Cables USB ↔ Ventilador". Detalle completo, con las cifras exactas
> de cada comprobación, en `docs/Virtual_Assembly_Report.md`. Los
> dos últimos puntos ("Tornillos ↔ componentes", "Insertos ↔ nervios
> del bastidor") siguen pendientes: no hay tornillos ni nervios
> modelados todavía en el bastidor.

9. Orden de desarrollo

Una vez aprobado este documento:

Modelo de implantación 3D (componentes simplificados a escala, sin detalles estéticos).
Verificación de colisiones.
Diseño del bastidor (chassis.scad).
front_frame.scad.
Panel inferior.
Panel NFC.
Panel trasero.
Panel superior.

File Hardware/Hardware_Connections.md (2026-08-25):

# SteamMachine UM790 — Conexiones de hardware

> **Estado:** Referencia definitiva de conexiones de hardware  
> **Proyecto:** SteamMachine-UM790  
> **Controlador:** ESP32

Este documento es la referencia actual para el cableado de los componentes ESP32, RC522, OLED y WS2812B.

> **2026-08-25**: eliminado el 74AHCT125 del diseño. Se probó con 8
> LEDs conectados directamente al GPIO25 (sin nivelador) y funcionó
> correctamente — la propia tira WS2812B admite el nivel lógico de
> 3.3V del ESP32 sin problema en un tramo corto. El nivelador se
> añadió originalmente por precaución, pero resultó ser el origen de
> un fallo real (con toda probabilidad, el pin /1OE del chip quedó
> flotante — ver el punto correspondiente que ya estaba en la lista de
> verificación de este mismo documento antes de este cambio).

## 1. Asignación de pines del ESP32

| ESP32 | Función |
|---:|---|
| GPIO5 | RC522 SDA/SS |
| GPIO18 | RC522 SCK |
| GPIO19 | RC522 MISO |
| GPIO23 | RC522 MOSI |
| GPIO27 | RC522 RST |
| GPIO21 | OLED SDA |
| GPIO22 | OLED SCL |
| GPIO25 | Fuente de datos WS2812B (directo, sin nivelador) |
| 3V3 | Alimentación RC522 + OLED |
| VIN (~4.68 V medidos) | Alimentación WS2812B |
| GND | Tierra común |

## 2. Cable y código de colores

Cable 22 AWG / 0,32 mm², cobre estañado, aislamiento de silicona.

Código de colores (5 colores, para mantener el cableado organizado en todo el montaje — especialmente entre RC522, OLED, WS2812B y ESP32):

| Color | Se reserva para |
|---|---|
| 🔴 Rojo | +5V |
| ⚫ Negro | GND |
| 🟡 Amarillo | Datos / señales |
| 🔵 Azul | SPI |
| 🟢 Verde | I²C |

Misma especificación que `docs/07_Hardware_Specification.md`, sección
"Cableado" — si se cambia el esquema de colores, actualizar ambos
documentos.

## 3. ESP32 → RC522

| RC522 | ESP32 |
|---|---|
| 3.3V | 3V3 |
| GND | GND |
| SDA / SS | GPIO5 |
| SCK | GPIO18 |
| MOSI | GPIO23 |
| MISO | GPIO19 |
| RST | GPIO27 |

**No conectes el RC522 a 5 V.**

RC522

## 4. ESP32 → OLED

| OLED | ESP32 |
|---|---|
| VCC | 3V3 |
| GND | GND |
| SDA | GPIO21 |
| SCL | GPIO22 |

OLED

## 5. ESP32 → WS2812B (directo, sin nivelador)

Ruta de datos:

`GPIO25 → 330 Ω → WS2812B DIN`

El resistor en serie sigue recomendándose como buena práctica general
(protege el primer LED de picos y mejora la integridad de la señal),
aunque ya no hay nivelador de por medio.

## 6. WS2812B

El proyecto utiliza **8 LEDs** (dato real confirmado, 2026-08-25 — antes se estimaba ~15cm/~9 LEDs).

Se ha verificado el cableado actual de la tira y **el cable verde es DIN/datos**.

| WS2812B | Conexión |
|---|---|
| +5V | ESP32 VIN (~4.68 V medidos) |
| DIN | 330 Ω desde GPIO25 |
| GND | GND común |

Sigue la flecha impresa en la tira y conéctalo en su **lado de entrada/DIN**.

WS2812B

## 7. Condensador de desacoplamiento para WS2812B

Colocar un **condensador electrolítico de 470–1000 µF, de ≥10 V**, cerca del inicio de la tira sigue siendo recomendable — es independiente del nivelador que se ha retirado.

- Condensador `+` → WS2812B +5V
- Condensador `−` → WS2812B GND

Condensador de desacoplamiento

## 8. Cableado completo

> ⚠️ El diagrama de abajo (`complete_hardware_wiring.svg`) todavía
> muestra el 74AHCT125 — quedó desactualizado con este cambio y no se
> ha podido regenerar aquí. Usa la ruta de datos de la sección 5 como
> referencia real hasta que se actualice la imagen.

Cableado completo

### Tierra común

Toda la electrónica controlada por el ESP32 comparte la misma línea GND:

- RC522 GND
- OLED GND
- WS2812B GND

## 9. Interfaz del botón de encendido del UM790

El ESP32 **no alimenta al UM790**.

El botón del proyecto se conecta directamente con los **contactos del botón de encendido original del UM790**. No conectes las líneas VIN o 3V3 del ESP32 a la circuitería de alimentación del botón del UM790.

## 10. Componentes

| Cant. | Componente | Propósito |
|---:|---|---|
| 1 | Resistencia de 330 Ω | Resistencia en serie para WS2812B DIN |
| 1 | Condensador electrolítico de 470–1000 µF ≥10 V | Estabilización de alimentación para WS2812B |
| 8 LEDs | Tira WS2812B | Iluminación frontal |

## 11. Lista de verificación

- [ ] RC522 a 3.3 V.
- [ ] OLED a 3.3 V.
- [ ] VIN medido en aproximadamente 4.68 V.
- [ ] GPIO25 → 330 Ω → WS2812B DIN.
- [ ] Cable verde del WS2812B confirmado como DIN.
- [ ] Polaridad del WS2812B verificada.
- [ ] Polaridad del condensador de 470–1000 µF verificada.
- [ ] GND común verificado.

## 12. Referencia de pines en el firmware

```python
RC522_SS   = 5
RC522_SCK  = 18
RC522_MOSI = 23
RC522_MISO = 19
RC522_RST  = 27

OLED_SDA = 21
OLED_SCL = 22

WS2812B_DATA = 25
```

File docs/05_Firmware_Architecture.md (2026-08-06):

\# SteamMachine UM790

\# 05 - Firmware Architecture

Version: 1.0

Status: Draft

\---

\# Objetivo

Este documento define la arquitectura del firmware del controlador ESP32 utilizado en SteamMachine UM790.

El firmware debe ser:

\- modular

\- estable

\- fácilmente ampliable

\- independiente del software del PC

El ESP32 actúa únicamente como controlador hardware.

Toda la lógica del sistema reside en el PC.

\---

\# Responsabilidades del ESP32

El firmware será responsable únicamente de:

\- Inicializar el hardware

\- Leer el RC522

\- Leer el pulsador

\- Controlar la pantalla OLED

\- Controlar la barra LED

\- Comunicarse con el PC

\- Informar del estado del hardware

No ejecutará ninguna lógica relacionada con plataformas o emuladores.

\---

\# Arquitectura

```

&#x20;                MAIN LOOP

&#x20;                     │

&#x20;    ┌────────────────┼────────────────┐

&#x20;    │                │                │

&#x20;Hardware        Communication      Services

```

\---

\# Organización del código

```

firmware/

src/

&#x20;   main.cpp

&#x20;   config.h

&#x20;   core/

&#x20;       application.cpp

&#x20;       application.h

&#x20;       event\_queue.cpp

&#x20;       event\_queue.h

&#x20;       scheduler.cpp

&#x20;       scheduler.h

&#x20;   hardware/

&#x20;       rc522.cpp

&#x20;       rc522.h

&#x20;       oled.cpp

&#x20;       oled.h

&#x20;       leds.cpp

&#x20;       leds.h

&#x20;       button.cpp

&#x20;       button.h

&#x20;   communication/

&#x20;       serial\_protocol.cpp

&#x20;       serial\_protocol.h

&#x20;       json\_parser.cpp

&#x20;       json\_parser.h

&#x20;   services/

&#x20;       animations.cpp

&#x20;       animations.h

&#x20;       diagnostics.cpp

&#x20;       diagnostics.h

&#x20;       watchdog.cpp

&#x20;       watchdog.h

&#x20;   utils/

&#x20;       logger.cpp

&#x20;       logger.h

&#x20;       timers.cpp

&#x20;       timers.h

```

\---

\# Flujo de arranque

```

Power On

↓

Inicializar GPIO

↓

Inicializar OLED

↓

Inicializar LEDs

↓

Inicializar RC522

↓

Inicializar Puerto Serie

↓

Enviar evento BOOT

↓

Esperar comandos del PC

```

\---

\# Estados del firmware

```

BOOT

↓

IDLE

↓

TAG DETECTED

↓

WAIT BUTTON

↓

RUNNING

↓

IDLE

```

\---

\# Módulos Hardware

\## RC522

Responsabilidades

\- Inicializar SPI

\- Detectar tarjeta

\- Leer UID

\- Detectar retirada

Eventos generados

tag

tag\_removed

\---

\## OLED

Responsabilidades

\- Inicialización

\- Mostrar texto

\- Mostrar iconos

\- Mostrar estado

No almacena información.

Siempre representa el estado enviado por el PC.

\---

\## LED Manager

Responsabilidades

\- Color fijo

\- Intensidad

\- Animaciones

\- Efectos

Animaciones disponibles

\- idle

\- loading

\- launch

\- success

\- error

\- shutdown

\---

\## Button

Responsabilidades

\- Detectar pulsación

\- Antirrebote

Eventos

button

\---

\# Comunicación Serie

Todos los mensajes utilizan JSON.

El firmware nunca interpreta el contenido funcional.

Simplemente recibe comandos y responde.

\---

\# Event Queue

Toda la comunicación entre módulos se realiza mediante una cola de eventos.

Ejemplo

```

RC522

↓

Event Queue

↓

Serial Manager

```

Esto evita dependencias entre módulos.

\---

\# Watchdog

El firmware incorporará un Watchdog.

Si alguna tarea deja de responder:

\- registrar error

\- reiniciar controlador

\---

\# Diagnóstico

El firmware podrá responder:

Versión

Estado

Temperatura

Memoria libre

Tiempo desde arranque

Ejemplo

```json

{

&#x20;   "event":"status",

&#x20;   "uptime":1254,

&#x20;   "heap":201344

}

```

\---

\# Configuración

Toda la configuración estará centralizada en

config.h

Ejemplos

Velocidad Serie

Brillo LED

Tiempo antirrebote

Timeout RC522

Pin OLED

Pin LEDs

Pin Pulsador

\---

\# Librerías previstas

Arduino Framework

ESP32 Arduino Core

ArduinoJson

MFRC522

Adafruit SSD1306

Adafruit GFX

FastLED

SPI

Wire

\---

\# Principios de diseño

Cada módulo tendrá una única responsabilidad.

No existirán variables globales innecesarias.

Toda la comunicación utilizará eventos.

No se utilizarán retardos bloqueantes (`delay()`).

Se priorizará el uso de temporizadores basados en `millis()`.

\---

\# Futuras ampliaciones

El diseño permite añadir sin modificar la arquitectura:

\- Control PWM del ventilador

\- Sensor de temperatura

\- Sensor de humedad

\- Wi-Fi

\- OTA

\- MQTT

\- Bluetooth

\- Home Assistant

\- Pantalla a color

\- Segundo lector NFC

\---

\# Estado

Versión 1.0

Documento preparado para comenzar el desarrollo del firmware ESP32.

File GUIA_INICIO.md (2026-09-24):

# Guía completa: monta y pon en marcha tu SteamMachine UM790

Esta guía te lleva de cero a tener el proyecto funcionando, aunque no
hayas tocado nunca una impresora 3D, un ESP32 o una terminal. No hace
falta ningún conocimiento previo — cada paso explica qué estás haciendo
y por qué. Si en algún momento algo no funciona, ve directo a la
sección [10. Solución de problemas](#10-solución-de-problemas).

Los documentos técnicos detallados (`docs/01` a `docs/14`) siguen ahí
para quien quiera profundizar; esta guía es el camino corto para llegar
a tenerlo funcionando.

## Índice

1. [Qué vas a construir](#1-qué-vas-a-construir)
2. [Antes de empezar: lista de materiales](#2-antes-de-empezar-lista-de-materiales)
3. [Paso 1 — Imprimir y montar la carcasa](#3-paso-1--imprimir-y-montar-la-carcasa)
4. [Paso 2 — Cablear la electrónica](#4-paso-2--cablear-la-electrónica)
5. [Paso 3 — Preparar el mini PC (Bazzite)](#5-paso-3--preparar-el-mini-pc-bazzite)
6. [Paso 4 — Programar el ESP32 (firmware)](#6-paso-4--programar-el-esp32-firmware)
7. [Paso 5 — Instalar el software del PC (el "Core")](#7-paso-5--instalar-el-software-del-pc-el-core)
8. [Paso 6 — Primera prueba completa](#8-paso-6--primera-prueba-completa)
9. [Paso 7 — Que arranque solo](#9-paso-7--que-arranque-solo)
10. [Solución de problemas](#10-solución-de-problemas)
11. [Mapa del repositorio](#11-mapa-del-repositorio)

---

## 1. Qué vas a construir

Un mini PC (Minisforum UM790 Pro) metido dentro de una carcasa impresa
en 3D con forma de consola. Tiene paneles frontales intercambiables:
cada panel lleva una etiqueta NFC escondida, y al acercarlo a un lector
y pulsar un botón, el PC lanza automáticamente Steam, tu colección
retro (RetroDECK / RetroArch) o el panel de disparos/zombies (THE
HOUSE OF THE DEAD: Remake y THE HOUSE OF THE DEAD 2: Remake, ambos
nativos de Steam vía Proton). Hay también un panel **Apagar** que
apaga el equipo de forma ordenada. Una pantalla OLED y una barra de
LEDs te muestran qué panel has puesto.

Tres piezas hacen que esto funcione:

- **La carcasa** (impresión 3D, diseño en OpenSCAD).
- **El firmware** (`firmware/`): un programa en C++ que vive dentro de
  un ESP32 — una placa pequeña y barata que lee el NFC, controla la
  pantalla y los LEDs, y detecta el botón.
- **El Core** (`software/`): un programa en Python que corre en el
  propio mini PC, habla con el ESP32 por USB, y decide qué aplicación
  lanzar según el panel que hayas puesto.

No hace falta que hagas los tres pasos en orden estricto, pero esta
guía sí lo hace, porque cada uno se apoya en el anterior para poder
probarse.

---

## 2. Antes de empezar: lista de materiales

### Hardware

| Componente | Notas |
|---|---|
| Mini PC Minisforum UM790 Pro | El "cerebro" del sistema |
| Ventilador Noctua NF-A12x15 PWM (120×120×15mm) | Refrigeración |
| Placa ESP32-WROOM-32D DevKit (modelo HW-394) | El "controlador" del frontal |
| Lector NFC MFRC522 | Lee los paneles |
| Pantalla OLED I²C 0.96" (128×64) | Muestra el estado |
| Barra LED WS2812B (RGB direccionable) | Feedback visual — se conecta directa al ESP32, sin nivelador |
| Pulsador metálico antivandálico Ø16mm, iluminado | Confirma el lanzamiento |
| HUB USB CJMCU-204 (4 puertos) | Reparte el USB del mini PC entre frontal y ESP32 |
| Fuente de alimentación externa | Menos calor y más espacio dentro de la carcasa |
| Tags NFC (uno por panel) | Los que vayas a esconder en cada panel intercambiable |
| Tornillería M2, M2.5, M3, M4, M5, M6, M8 e insertos roscados | Según pieza — ver `docs/07_Hardware_Specification.md` |
| Imanes de neodimio 3×2mm y 6×2mm | Fijan los paneles intercambiables |
| Filamento **PETG** (todas las piezas; el PLA se deforma con el calor del equipo) | Impresión 3D. PLA solo para pruebas de encaje, nunca montado |
| Loctite (cianoacrilato tipo 401/454) | Pegar los anagramas sueltos de `STL/Anagramas/` sobre el panel NFC en blanco |

### Herramientas

- Impresora 3D FDM (el proyecto se ha probado con una Anycubic Kobra X).
- Destornilladores pequeños (Phillips/Allen, tornillería M2-M4).
- Un cable USB para flashear el ESP32.
- Un ordenador (puede ser el mismo mini PC, o cualquier otro) para
  compilar el firmware y descargar el proyecto.
- Un pendrive (para instalar el sistema operativo del mini PC).

### Conocimientos previos

Ninguno es obligatorio. Si nunca has abierto una terminal, cada comando
de esta guía está pensado para copiar y pegar tal cual. Lo único que
ayuda (pero no es necesario) es haber usado antes un ordenador con
Linux.

---

## 3. Paso 1 — Imprimir y montar la carcasa

1. Descarga el repositorio completo (botón **Code → Download ZIP** en
   GitHub, o `git clone` si ya sabes usarlo).
2. Los ficheros listos para imprimir están en `STL/`. Si tu impresora
   los admite directamente, no necesitas tocar nada más.

   Para los **paneles NFC con anagrama** (Steam, RetroBat, etc.),
   `STL/Anagramas/` trae el panel en blanco (`nfc_panel_blank.stl`) y
   cada anagrama por separado (`Steam.stl`, `Retrobat.stl`,
   `Parrot.stl`, `engranaje.stl`, `Gung.stl` — este último es el
   anagrama del panel Zombies —, y `Apagar.stl`, el del panel Apagar)
   para imprimirlos como piezas independientes en vez de la pieza única con el emblema
   integrado. Imprime el panel en blanco y el anagrama que quieras por
   separado, y pégalos con **Loctite** (un cianoacrilato tipo Loctite
   401/454). Sobre PETG el cianoacrilato agarra algo peor que sobre PLA:
   lija ligeramente las dos caras y desengrasa con alcohol isopropílico
   antes de pegar; si se despega, usa epoxi de 5 minutos. Este método baja el tiempo de
   impresión de ~6 horas (pieza única con el emblema en relieve) a
   ~1 hora, porque el anagrama es una pieza pequeña y plana que no
   necesita soportes ni tantas capas del panel completo debajo.
   Los STL de un único bloque (con el emblema ya integrado, sin pegar)
   siguen disponibles directamente en `STL/` y en
   `openscad/parts/03_panels/` si prefieres esa vía.
   **Caja para guardar los paneles**: `STL/caja_nfc_panel_caja.stl` y
   `STL/caja_nfc_panel_tapa.stl` (o `caja_nfc_panel_caja_y_tapa.stl`,
   las dos piezas en una sola placa). Guarda hasta 6 paneles de canto;
   ver `docs/14_Caja_Paneles_NFC.md`.
3. Si quieres ajustar medidas (por ejemplo, si tu mini PC no es
   exactamente un UM790 Pro), el diseño paramétrico está en
   `openscad/` y `00_parametros.scad`, hecho con
   [OpenSCAD](https://openscad.org/) (gratuito).
4. **Material: PETG para todas las piezas.** El PLA (y el PLA+) se
   deforma con la temperatura del mini PC, así que no lo dejes montado
   dentro del equipo; úsalo solo para probar encajes. Si una pieza lleva
   dos filamentos (el panel inferior, con el difusor LED translúcido),
   los dos deben ser PETG. Parámetros orientativos: altura de capa
   0.20mm, 3-4 perímetros, relleno 15-30%; PETG con boquilla a
   230-250 °C, cama a 70-85 °C y ventilador de capa bajo (30-50%) —
   parte del perfil PETG de tu marca de filamento. Más detalle en el
   [README](README.md#material-petg).
   Las holguras del diseño se ajustaron con PLA+: con PETG revisa los
   encajes antes de montar.
5. El montaje mecánico paso a paso (con checklist) está en
   `docs/11_Assembly_Manual.md`. Termina el montaje físico completo
   (carcasa, mini PC, ventilador, soportes) antes de pasar al cableado.

---

## 4. Paso 2 — Cablear la electrónica

Con la carcasa montada, toca conectar el ESP32 a sus periféricos.
**Antes de dar corriente a nada, revisa dos veces que cada cable va al
pin correcto** — un fallo aquí es la causa más común de que algo "no
funcione" más adelante.

### Pinout

| Función | Pin del ESP32 |
|---|---|
| RC522 SDA/SS | GPIO5 |
| RC522 SCK | GPIO18 |
| RC522 MISO | GPIO19 |
| RC522 MOSI | GPIO23 |
| RC522 RST | GPIO27 |
| OLED SDA | GPIO21 |
| OLED SCL | GPIO22 |
| Barra LED WS2812B (directa, sin nivelador) | GPIO25 |
| Pulsador | GPIO13 |

### Alimentación

| Riel | Alimenta |
|---|---|
| 3V3 (del ESP32) | RC522 + OLED |
| VIN, ~4.68V | WS2812B |
| GND | Masa común a todo |

El dato de la barra LED sale del ESP32 a 3.3V por el GPIO25 y va
**directo** a la tira, sin ningún chip intermedio. El diseño original
llevaba un nivelador lógico (74AHCT125) para elevar la señal a los
~5V que en teoría espera la WS2812B, pero se retiró: probado con 8
LEDs, funciona bien recibiendo la señal directamente a 3.3V, y con el
nivelador en el circuito no encendía nada — lo más probable es que
tuviera un pin de habilitación (/OE) sin conectar a GND, un fallo muy
típico con ese chip. Si en el futuro con la tira completa (más larga)
notas parpadeos o colores erráticos, puede ser señal de que sí hace
falta un nivelador bien cableado — pero de entrada, directo funciona.

### Cable y colores

Cable 22 AWG / 0,32 mm², cobre estañado, aislamiento de silicona. Usa
siempre el mismo color para lo mismo en todo el montaje — te ahorra
sustos al revisar el cableado más adelante:

| Color | Para |
|---|---|
| 🔴 Rojo | +5V |
| ⚫ Negro | GND |
| 🟡 Amarillo | Datos / señales |
| 🔵 Azul | SPI (RC522) |
| 🟢 Verde | I²C (OLED) |

No conectes todavía el ESP32 al mini PC por USB — eso lo harás en el
[Paso 4](#6-paso-4--programar-el-esp32-firmware), después de
flashearlo.

---

## 5. Paso 3 — Preparar el mini PC (Bazzite)

1. Descarga [Bazzite](https://bazzite.gg/) (el sistema operativo, un
   Linux orientado a gaming) y grábalo en un pendrive con una
   herramienta como [Balena Etcher](https://etcher.balena.io/) o
   [Rufus](https://rufus.ie/).
2. Arranca el mini PC desde el pendrive e instala Bazzite siguiendo el
   asistente (formatea el disco del UM790, así que asegúrate de que no
   tiene nada que quieras conservar).
3. Una vez dentro del escritorio, instala RetroDECK (pack todo-en-uno
   de emulación retro) desde la Discover Store o con:
   ```bash
   flatpak install flathub net.retrodeck.retrodeck
   ```
4. Instala también **RetroArch** (Flatpak, directo, sin pasar por
   RetroDECK — útil para paneles dedicados a un sistema/core concreto):
   ```bash
   flatpak install flathub org.libretro.RetroArch
   ```
   Ábrelo una vez para que genere su configuración en
   `~/.var/app/org.libretro.RetroArch/config/retroarch/`. Luego, desde
   dentro de RetroArch: **Menú principal → Actualizador en línea →
   Actualizar información de núcleos** (imprescindible, o el
   Descargador de núcleos mostrará "No hay elementos disponibles") y a
   continuación **Descargador de núcleos**, donde instalas los que
   necesites — por ejemplo:
   - **Flycast** (Dreamcast/Naomi)
   - **Beetle Saturn** / Mednafen Saturn
   - **PCSX-ReARMed** (PS1)
   - **MAME2003-Plus** (arcade)

   Los BIOS (obligatorios para PS1 y Saturn; recomendables para
   Dreamcast) van en
   `~/.var/app/org.libretro.RetroArch/config/retroarch/system/` —
   tienes que dumpearlos tú mismo de hardware que poseas, RetroArch no
   los distribuye. Las ROMs las importas luego desde **Importar
   contenido → Escanear directorio**.
5. Comprueba que Steam ya está instalado (Bazzite lo trae de fábrica).
   Para el panel de zombies, instala desde Steam **THE HOUSE OF THE
   DEAD: Remake** (AppID `1694600`) y **THE HOUSE OF THE DEAD 2:
   Remake** (AppID `3376690`) — son juegos nativos de Steam vía
   Proton, no necesitan emulador. Si al primero le fallan los vídeos
   de introducción, fuerza **Proton GE** en vez del Proton estándar
   (Propiedades del juego → Compatibilidad).

---

## 6. Paso 4 — Programar el ESP32 (firmware)

Esto se puede hacer desde el propio mini PC o desde otro ordenador —
lo único que necesitas es el ESP32 conectado por USB a la máquina desde
la que flasheas.

1. Instala [Visual Studio Code](https://code.visualstudio.com/) y,
   dentro, la extensión **PlatformIO IDE** (búscala en el panel de
   extensiones). PlatformIO es la herramienta que compila el código C++
   y lo sube al ESP32.
2. Abre la carpeta `firmware/` del proyecto en VS Code (**Archivo →
   Abrir carpeta**).
3. Conecta el ESP32 al ordenador por USB.
4. En VS Code, con `firmware/` abierta y el ESP32 conectado por USB,
   usa los **botones de PlatformIO** en vez de escribir comandos —
   son más fiables porque no dependen de que tu terminal tenga nada
   configurado. Al instalar la extensión aparece una franja azul en la
   parte inferior de VS Code con varios iconos; los que necesitas son:
   - ✔️ (**Build**) — compila.
   - ➡️ (**Upload**) — flashea el ESP32.
   - 🔌 (**Serial Monitor**) — abre el monitor serie.

   Pulsa los tres en ese orden. Si no ves esa franja azul, abre el
   icono de PlatformIO (una cabeza de hormiga) en la barra lateral
   izquierda → **PROJECT TASKS → esp32doit-devkit-v1 → General**, y
   ahí tienes Build/Upload/Monitor como una lista.

   > **¿Por qué no usar una terminal normal?** En Windows es habitual
   > que el comando `pio` dé el error *"no se reconoce como nombre de
   > un cmdlet..."* aunque la extensión funcione perfectamente — el
   > `pio` de PlatformIO no se añade solo al PATH de PowerShell. Si
   > prefieres la terminal de todos modos, abre **PlatformIO Core
   > CLI** desde el icono de PlatformIO (no "Terminal → Nueva
   > terminal" de VS Code): esa sí tiene `pio` disponible, con los
   > mismos comandos que abajo.
   ```bash
   cd firmware
   pio run                                            # compila
   pio run --target upload -e esp32doit-devkit-v1     # flashea el ESP32
   pio device monitor -b 115200                        # abre el monitor serie
   ```
   El monitor serie (por botón o por `pio device monitor`) es clave:
   abre una ventana de texto en directo con todo lo que el ESP32 envía
   por el cable USB — es la única forma de "ver" lo que está haciendo,
   ya que no tiene pantalla propia. Todo lo que describen los pasos 5
   y 6 aparece ahí.
5. Al arrancar verás primero unas líneas de texto sueltas del propio
   arranque del ESP32 (algo como `ets Jul 29 2019...`, `rst:0x1...`,
   `load:0x3fff0030...`) — son normales, ignóralas. Justo después debe
   aparecer la línea que de verdad importa:
   ```
   {"event":"boot","firmware":"1.0.0"}
   ```
   Si el ESP32 llevaba un rato encendido antes de abrir el monitor, te
   la habrás perdido — pulsa el botón RESET/EN de la placa, o
   desconecta y vuelve a conectar el USB, para que arranque de nuevo
   con el monitor ya abierto.

   Si justo después ves también `{"event":"error","code":1}`, es que
   el RC522 (lector NFC) no responde — normal si todavía no lo has
   cableado. Ver [Solución de problemas](#10-solución-de-problemas).

   Si no aparece ninguna línea en absoluto, ve a
   [Solución de problemas](#10-solución-de-problemas).
6. Con el monitor todavía abierto, haz estas comprobaciones antes de
   seguir:
   - Acerca un tag NFC al lector → debe aparecer
     `{"event":"tag","uid":"..."}` con un código de 8 caracteres.
     **Apunta ese UID**, lo necesitarás en el paso siguiente.
   - Retíralo → `{"event":"tag_removed"}`.
   - Pulsa el botón → `{"event":"button"}`.
   - Escribe a mano en el monitor y pulsa Enter para probar la
     pantalla y los LEDs:
     `{"cmd":"oled","text":"Hola"}` (debe aparecer en pantalla) y
     `{"cmd":"led","color":"#00FF00"}` (la barra debe ponerse verde).

Solo sigas al siguiente paso cuando estas seis comprobaciones
funcionen. Es la única forma de saber si un problema viene del
cableado/firmware o del software del PC.

---

## 7. Paso 5 — Instalar el software del PC (el "Core")

Este paso sí es en el propio mini PC (necesita hablar con el ESP32 por
USB).

1. Descarga el proyecto en el mini PC (mismo repositorio del Paso 1).
2. Abre una terminal y ejecuta:
   ```bash
   cd software
   python3 -m venv .venv
   source .venv/bin/activate
   pip install -r requirements.txt
   ```
3. Conecta el ESP32 (ya flasheado) al mini PC por USB, a través del
   HUB del frontal.
4. Añade los UID reales de tus tags NFC (los que apuntaste en el paso
   anterior) en `config/panel_database.json`. Ya trae varios de ejemplo:
   ```json
   {
     "04A1C8B2": { "name": "Steam", "launcher": "steam", "led": "#0055FF", "icon": "steam.png" },
     "04B2D9C3": { "name": "RetroDECK", "launcher": "retrodeck", "led": "#8800FF", "icon": "retrodeck.png" },
     "04C3EAD4": { "name": "Zombies - HOTD Remake", "launcher": "hotd_remake", "led": "#FF3300", "icon": "hotd_remake.png" },
     "0AAABBCC": { "name": "Zombies - HOTD 2 Remake", "launcher": "hotd2_remake", "led": "#CC0000", "icon": "hotd2_remake.png" },
     "04E5A0F6": { "name": "Apagar", "profile": "APAGAR", "launcher": null, "led": "#FF0000", "icon": "apagar.png" }
   }
   ```
   Sustituye esas claves (`04A1C8B2`, etc.) por los UID de tus tags
   reales — la clave es el UID, el resto de campos puedes dejarlos o
   personalizarlos. El de HOTD 2 Remake (`0AAABBCC`) es un placeholder
   hasta que tengas un segundo tag/panel físico dedicado a ese juego;
   mientras tanto, un solo panel puede apuntar a `hotd_remake` y
   cambiar de juego se hace a mano desde Steam.

   **Panel Apagar**: el fichero real trae su entrada con la clave
   `UID_APAGAR_PENDIENTE`. Sustitúyela por el UID del tag que metas en
   ese panel (el mismo procedimiento que con los demás). Es importante
   que la entrada conserve `"profile": "APAGAR"`: es el perfil
   (`config/profiles/apagar.json`) el que le dice al Core que ese panel
   apaga el equipo; sin él, el botón no hace nada. En el modo simulado
   del Core el apagado nunca se ejecuta de verdad, solo se registra en
   el log.
5. Arranca el Core:
   ```bash
   python main.py
   ```
   Por defecto busca el ESP32 automáticamente. Si no lo encuentra:
   ```bash
   ls /dev/serial/by-id/     # busca algo como usb-1a86_USB_Serial-if00-port0
   ```
   y pon esa ruta a mano en `config/config.json`:
   ```json
   "serial": { "port": "/dev/ttyUSB0", "simulate": false }
   ```

---

## 8. Paso 6 — Primera prueba completa

Con el Core corriendo (`python main.py`), acerca un panel al lector:

1. La pantalla OLED debería mostrar el nombre del panel.
2. La barra LED debería cambiar suavemente al color de ese panel.
3. Pulsa el botón → la barra hace una animación de "lanzamiento" y, si
   todo va bien, se abre Steam/RetroDECK/RetroArch o el juego de
   zombies correspondiente según el panel.
4. Retira el panel → la pantalla se apaga y el LED vuelve al azul de
   reposo.

**Prueba del panel Apagar** (hazla con el equipo ya en su sitio y sin
nada importante abierto: apaga el mini PC de verdad). Antes, comprueba
en una terminal que tu usuario puede apagar sin contraseña — el panel
usa exactamente el mismo comando:

```bash
systemctl poweroff
```

Si eso apaga el equipo sin pedir nada, el panel también podrá.
Arranca de nuevo y prueba con el panel: al colocarlo, la OLED debe
mostrar `APAGAR EQUIPO` (todavía sin apagar); al pulsar el botón, pasa a
`Apagando...`, los LEDs se funden a negro y el equipo se apaga.

Si algo de esto no pasa, revisa primero que el [Paso 4](#6-paso-4--programar-el-esp32-firmware)
funcionó por sí solo (con el monitor serie) — si el firmware ya
funcionaba a solas y ahora falla con el Core, el problema suele estar
en `config/panel_database.json` (UID mal copiado) o en el puerto serie.

---

## 9. Paso 7 — Que arranque solo

Para no tener que abrir una terminal cada vez que enciendas el mini PC:

```bash
mkdir -p ~/.config/systemd/user
cp steammachine.service ~/.config/systemd/user/
systemctl --user daemon-reload
systemctl --user enable --now steammachine.service
```

Si instalaste el proyecto en una ruta distinta de
`~/SteamMachine-UM790/software`, edita `ExecStart` y `WorkingDirectory`
dentro de `steammachine.service` antes del `cp`.

Para comprobar que está corriendo, o ver qué está pasando si algo
falla:

```bash
systemctl --user status steammachine.service
journalctl --user -u steammachine.service -f
```

---

## 10. Solución de problemas

**`pio` no se reconoce como comando (Windows, PowerShell)**
La extensión de PlatformIO no añade `pio` al PATH de una terminal
normal. Usa los botones ✔️/➡️/🔌 de la franja azul inferior de VS
Code, o abre **PlatformIO Core CLI** desde el icono de PlatformIO en
la barra lateral (no "Terminal → Nueva terminal") — ver el
[Paso 4](#6-paso-4--programar-el-esp32-firmware).

**El ESP32 no aparece al conectarlo (ni en PlatformIO ni en `/dev/serial/by-id/`)**
Prueba otro cable USB (muchos cables baratos son solo de carga, sin
datos) y otro puerto USB. En Linux, puede que necesites permisos:
`sudo usermod -aG dialout $USER` y reiniciar sesión.

**`pio run` falla al compilar**
Revisa el mensaje de error concreto — suele ser una librería que no se
descargó bien. Prueba `pio pkg update` dentro de `firmware/` y vuelve a
intentarlo. Si el error es de red, comprueba tu conexión a internet
(PlatformIO descarga el compilador y las librerías la primera vez). Si
el error menciona `FastLED` y `rbtree.h` (`mTree`, `const_iterator`,
`RedBlackTree`...), es un fallo conocido de las versiones más recientes
de FastLED con este compilador — este proyecto ya fija la versión
`3.7.8` en `firmware/platformio.ini`, que lo evita. Si aun así te
aparece, borra la carpeta `.pio` dentro de `firmware/` por completo
(PlatformIO puede haber dejado en caché una versión rota descargada
antes de que se fijara) y vuelve a compilar.

**El monitor serie no muestra nada al arrancar**
Confirma que elegiste la velocidad correcta (115200) y que ningún otro
programa tiene el puerto abierto (cierra PlatformIO's monitor antes de
abrir el Core, y viceversa — solo uno puede usar el puerto a la vez).

**Aparece `{"event":"error","code":1}` justo después de arrancar**
El firmware no encuentra el lector RC522. Normal si todavía no lo has
cableado. Si ya lo tienes conectado, revisa los 5 cables (SDA/SS, SCK,
MISO, MOSI, RST) contra la tabla del
[Paso 2](#4-paso-2--cablear-la-electrónica), que esté alimentado a
3.3V (no 5V — puede dañarlo) y reinicia el ESP32 tras corregir algo.

**El panel NFC no se detecta**
Acércalo más (unos 2-3cm) y prueba distintas orientaciones — el
alcance del RC522 es corto. Si nunca detecta nada, revisa el cableado
SPI (SCK/MISO/MOSI/SS/RST) contra la tabla del [Paso 2](#4-paso-2--cablear-la-electrónica).

**El Core no encuentra el ESP32**
Comprueba con `ls /dev/serial/by-id/` que el sistema lo ve. Si no
aparece nada ahí, el problema es de cableado/USB, no del software —
vuelve al Paso 4. Si aparece pero el Core no conecta, ponlo a mano en
`config/config.json` como se explica en el Paso 5.

**Steam/RetroDECK/RetroArch/Zombies no arrancan al pulsar el botón**
Prueba a lanzarlos a mano desde el escritorio de Bazzite primero — si
tampoco arrancan así, el problema es de esa instalación, no del
proyecto. Si arrancan a mano pero no desde el botón, revisa que el
`launcher` de ese panel en `panel_database.json` coincide con las
claves `steam` / `retrodeck` / `retroarch` / `hotd_remake` /
`hotd2_remake` de `config/config.json`.

**El Descargador de núcleos de RetroArch muestra "No hay elementos disponibles"**
Falta actualizar el índice antes de poder listar núcleos: entra en
**Actualizador en línea → Actualizar información de núcleos**, espera
a que termine, y vuelve a **Descargador de núcleos** — ya debería
aparecer la lista completa.

**La pantalla OLED no enciende**
Revisa la dirección I2C — por defecto se asume `0x3C`. Si tu módulo usa
`0x3D`, cámbialo en `firmware/src/config.h` (`OLED_I2C_ADDRESS`) y
vuelve a flashear.

**Los LEDs no encienden, o encienden en colores raros**
La tira va directa al GPIO25 (sin nivelador, ver Paso 2) — comprueba
que está bien alimentada por VIN (no por 3V3) y que el GND de la tira
está unido al GND del ESP32. Si el color sale invertido, revisa que el
orden de color de tu tira coincide con `GRB` (el que usa el firmware
por defecto) — si tu tira es `RGB`, avisa para ajustar
`firmware/src/hardware/leds.cpp`.

Si nada de esto lo resuelve, el firmware tiene un canal de depuración
más detallado por Serial2 — ver "Depuración" en `firmware/README.md`.

**El mini PC se queda en un prompt `grub>` en vez de arrancar Bazzite**
*Prevención: apaga siempre con el panel Apagar (o desde el menú de
Bazzite) en vez de cortar la corriente de golpe.*

Es la consola de rescate de GRUB — aparece cuando el firmware UEFI
pierde la referencia al fichero de arranque, normalmente por un corte
de corriente justo durante un arranque anterior (no es un fallo del
proyecto, ni algo que se pueda producir cableando el pulsador de
encendido trasero — solo coincidencia si pasa justo después). El
sistema en sí no suele estar dañado, solo esa referencia. Para
recuperarlo sin perder nada:

1. En el prompt `grub>`, comprueba que el disco se ve bien:
   ```
   ls
   ```
   Deberías ver algo como `(hd0) (hd0,gpt1) (hd0,gpt2) (hd0,gpt3)`.
2. Localiza la partición EFI (comprueba una a una si hace falta):
   ```
   ls (hd0,gpt1)/
   ```
   Busca una carpeta `efi/` — si no está en `gpt1`, prueba con `gpt2`, etc.
3. Dentro debería haber `efi/fedora/grub.cfg`. Cárgalo directamente:
   ```
   configfile (hd0,gpt1)/efi/fedora/grub.cfg
   ```
   (ajusta el número de partición al que hayas encontrado en el paso 2).
4. Debería aparecer el menú normal de arranque de Bazzite — arranca
   con Enter.
5. Una vez dentro, **reinicia una vez de forma normal** (menú de
   Steam/Bazzite, no cortando corriente) para confirmar que el
   arranque automático ya funciona solo, sin repetir estos pasos. Si
   vuelve a fallar, hay un comando (`sudo bootupctl`) para reescribir
   la entrada de arranque de forma permanente.

**El panel Apagar muestra `Error al apagar` (o el botón no hace nada)**
- `Error al apagar`: el sistema ha rechazado la orden y el equipo sigue
  encendido. Mira el motivo en `journalctl --user -u steammachine.service -n 30`.
  Lo más habitual es un bloqueo de apagado (p. ej. una actualización de
  Bazzite en curso). Comprueba qué lo bloquea con
  `systemd-inhibit --list`, y prueba `systemctl poweroff` a mano para
  ver el mensaje completo.
- El botón no hace nada con el panel puesto: la entrada del panel en
  `panel_database.json` no lleva `"profile": "APAGAR"` (o falta
  `config/profiles/apagar.json`). Sin perfil, el Core lo trata como un
  panel informativo y no hace nada.
- La OLED dice `Panel no reconocido`: el UID del tag no está en
  `panel_database.json`; sustituye `UID_APAGAR_PENDIENTE` por el real.

**Las piezas impresas se han deformado con el calor**
Están en PLA. Reimprímelas en PETG (ver [Paso 1](#3-paso-1--imprimir-y-montar-la-carcasa)).

---

## 11. Mapa del repositorio

```
GUIA_INICIO.md        Esta guía
README.md              Presentación general del proyecto
docs/                  Documentación técnica detallada (01 a 14)
openscad/, STL/         Diseño e impresión 3D de la carcasa
firmware/               Código C++ del ESP32 (ver firmware/README.md)
software/               Código Python del Core, corre en el mini PC (ver software/README.md)
```

Para profundizar en cualquier pieza, los documentos técnicos son la
referencia completa: `docs/04_Communication_Protocol.md` (cómo hablan
el ESP32 y el PC entre sí), `docs/05_Firmware_Architecture.md` y
`docs/08_Software_API.md` (arquitectura interna de cada lado),
`docs/07_Hardware_Specification.md` (lista de materiales completa),
`docs/11_Assembly_Manual.md` (montaje mecánico paso a paso) y
`docs/14_Caja_Paneles_NFC.md` (caja para guardar los paneles).

---

## Licencia

Proyecto bajo licencia MIT — ver `LICENSE`. Puedes usarlo, modificarlo
y compartirlo libremente.

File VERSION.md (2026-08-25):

v1.1.3
========
✔ Parámetros
✔ Librerías
✔ Bandeja UM790
✔ Chasis
✔ Tapa
✔ Frontal
✔ Panel trasero (con pulsador de encendido del UM790, añadido 2026-08-22)
✔ Ensamblaje virtual v1 (openscad/reference/virtual_assembly_v1.scad) — 28/28 sin colisión
✔ Posiciones de electrónica (definitivas, confirmadas por el usuario;
  ver docs/Virtual_Assembly_Report.md)
✔ Hardware montado y probado en real: RC522, barra LED (8 LED, directa sin nivelador), pulsador frontal, OLED, recuperación tras reinicio del ESP32

Ver CHANGELOG.md para el historial completo de versiones y decisiones de diseño.

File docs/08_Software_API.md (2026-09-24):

\# SteamMachine UM790

\# 08 - Software API

Version: 1.0

Status: Draft

\---

\# Objetivo

Este documento define la API interna del software SteamMachine UM790.

No describe la implementación, sino la estructura lógica del sistema, las clases principales y las interfaces entre módulos.

Toda la aplicación estará desarrollada en \*\*Python 3.12 o superior\*\*.

\---

\# Arquitectura General

```

&#x20;                 SteamMachine Core

&#x20;                        │

&#x20;┌──────────────┬─────────┼───────────┬──────────────┐

&#x20;│              │         │           │              │

Config      Serial     Launcher    OLED        LED Manager

&#x20;│              │         │           │              │

&#x20;│              │         │           │              │

Database    ESP32 API   Plugins     UI         Animations

```

\---

\# Estructura del proyecto

```

software/

core/

config/

database/

devices/

launcher/

plugins/

resources/

ui/

utils/

```

\---

\# Core

\## class SteamMachine

Clase principal.

Responsabilidades

\- Inicialización

\- Gestión de eventos

\- Coordinación de módulos

\- Ciclo principal

\### Métodos

```python

initialize()

run()

shutdown()

restart()

load\_configuration()

save\_configuration()

```

\---

\# Config

\## class ConfigurationManager

Responsabilidades

\- Leer configuración

\- Guardar configuración

\- Validar configuración

Métodos

```python

load()

save()

reset()

get()

set()

```

\---

\# Database

\## class PanelDatabase

Responsabilidades

\- Gestionar paneles NFC

\- Buscar UID

\- Añadir paneles

\- Eliminar paneles

Métodos

```python

load()

save()

find(uid)

add()

remove()

update()

```

\---

\# Serial

\## class SerialManager

Responsabilidades

\- Abrir puerto serie

\- Leer mensajes

\- Enviar mensajes

\- Reconexión automática

Métodos

```python

connect()

disconnect()

send()

receive()

is\_connected()

```

\---

\# ESP32 API

\## class ESP32Controller

Responsabilidades

Ocultar completamente el protocolo serie.

El resto del software nunca accederá directamente al puerto serie.

Métodos

```python

oled(text)

oled\_lines(line1,line2)

clear\_oled()

set\_led(color)

set\_brightness(value)

animation(name)

restart()

request\_status()

```

\---

\# Launcher

\## class Launcher

Responsabilidades

Ejecutar plataformas.

Métodos

```python

launch(platform)

stop(platform)

running()

status()

```

\---

\# Power Manager

\## class PowerManager

Responsabilidades

Apagado ordenado del mini PC (panel APAGAR). Ejecuta `systemctl poweroff` (configurable en `power.poweroff_command`), nunca lanza excepciones y devuelve False si el sistema rechaza la orden. Con `dry_run` (ESP32 simulado) solo registra el apagado.

Métodos

```python

poweroff()

configuration()

```

\---

\# Plugin Interface

Todos los lanzadores heredarán de

```python

BasePlugin

```

Ejemplo

```python

class SteamPlugin(BasePlugin)

```

Métodos obligatorios

```python

launch()

stop()

status()

configuration()

```

\---

\# Plugins implementados

Steam

RetroDECK (pack todo-en-uno de emulacion: PS2, GameCube, Wii, PS3...)

RetroArch (Flatpak, directo, sin pasar por RetroDECK)

Zombies - HOTD Remake (THE HOUSE OF THE DEAD: Remake, nativo de Steam via Proton)

Zombies - HOTD 2 Remake (THE HOUSE OF THE DEAD 2: Remake, nativo de Steam via Proton)

Nuevas plataformas se añaden implementando BasePlugin (ver launcher/base\_plugin.py en software/), sin tocar el resto del Launcher.

\---

\# OLED Manager

\## class OLEDManager

Métodos

```python

show\_text()

show\_logo()

show\_status()

clear()

sleep()

wake()

```

\---

\# LED Manager

\## class LEDManager

Métodos

```python

set\_color()

set\_brightness()

animation()

off()

flash()

fade()

```

\---

\# Event Manager

\## class EventManager

Responsabilidades

Toda la comunicación interna utilizará eventos.

Eventos

```

BOOT

TAG\_DETECTED

TAG\_REMOVED

BUTTON

LAUNCH

STOP

ERROR

SHUTDOWN

```

Métodos

```python

subscribe()

publish()

unsubscribe()

```

\---

\# Logger

\## class Logger

Responsabilidades

Registro completo del sistema.

Métodos

```python

info()

warning()

error()

critical()

debug()

```

\---

\# Hardware Monitor

\## class HardwareMonitor

Responsabilidades

Monitorizar

\- Estado ESP32

\- Memoria

\- Temperatura

\- Tiempo de actividad

Métodos

```python

update()

status()

temperature()

memory()

```

\---

\# Theme Manager

\## class ThemeManager

Responsabilidades

Asociar cada plataforma con

\- Color LED

\- Icono

\- Nombre

Métodos

```python

load()

theme(platform)

icon(platform)

color(platform)

```

\---

\# Flujo principal

```

SteamMachine.start()

↓

Configuration.load()

↓

Database.load()

↓

Serial.connect()

↓

ESP32.boot()

↓

Esperar eventos

↓

TAG

↓

Buscar plataforma

↓

Actualizar OLED

↓

Actualizar LED

↓

Esperar botón

↓

Launcher.launch()

↓

Volver a esperar

```

\---

\# Recursos

```

resources/

icons/

fonts/

sounds/

animations/

```

\---

\# Configuración

```

config/

config.json

panel\_database.json

themes.json

launcher.json

```

\---

\# Principios de diseño

\- Cada clase tendrá una única responsabilidad.

\- Ningún módulo accederá directamente al puerto serie excepto SerialManager.

\- Toda la comunicación será mediante eventos.

\- Los plugins nunca accederán directamente al hardware.

\- Todo será fácilmente ampliable.

\---

\# Compatibilidad futura

La arquitectura permitirá añadir:

\- MQTT

\- Home Assistant

\- API REST

\- Aplicación móvil

\- Control por voz

\- Estadísticas

\- Actualizaciones automáticas

\- Diagnóstico remoto

sin modificar el núcleo de la aplicación.

\---

\# Estado

Documento preparado para comenzar el desarrollo del software del PC.

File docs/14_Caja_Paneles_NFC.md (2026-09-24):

# SteamMachine UM790

# 14 - Caja para guardar los paneles NFC

Version: 1.0
Status: Diseñada; dimensiones comprobadas contra los STL. Pendiente de validar la impresión en PETG.

Pieza: `openscad/parts/Caja paneles NFC/caja_nfc_panel.scad`
STL: `STL/caja_nfc_panel_caja.stl`, `STL/caja_nfc_panel_tapa.stl` y
`STL/caja_nfc_panel_caja_y_tapa.stl` (las dos piezas en una sola placa,
equivale a `part = "print"`).

---

## 1. Qué es

Una caja con guías interiores y una tapa tipo funda que se desliza por
fuera. Guarda **6 paneles NFC de canto**, uno detrás de otro, cada uno
en su ranura. Los paneles sobresalen 10 mm por arriba para poder
cogerlos sin tirar de la tapa.

Hoy hay 5 paneles definidos en `software/config/panel_database.json`
(Steam, RetroDECK, Maintenance, Zombies y Apagar), así que queda **1
ranura libre**.

## 2. Medidas

Calculadas a partir del `.scad` y comprobadas contra el cuadro
delimitador de los STL (coinciden):

| Pieza | Medidas (mm) |
|---|---|
| Caja (exterior) | 155 × 48,8 × 86,9 |
| Tapa (exterior) | 160,4 × 54,2 × 23,4 |
| Placa con caja y tapa | 160,4 × 115,7 × 86,9 |
| Panel a guardar | 149 × 94,5 × 5 |
| Ranura por panel | 6 (panel 5 + 1 de holgura) |

## 3. Qué paneles caben

El panel en blanco mide 5 mm de grosor: placa de 3 mm
(`front_panel_thickness`) más un marco de 2 mm (`front_bezel_depth`). Un
anagrama de 2 mm pegado sobre la placa queda a ras del marco, así que el
panel sigue midiendo 5 mm y cabe.

Los anagramas de **3 mm** (`Parrot.stl`, `Mando.stl`) sobresaldrían 1 mm
del marco y el panel pasaría a 6 mm: no cabría en una ranura de 6 mm.
Si quieres guardar alguno, sube `piece_t` a 6 en el `.scad` y regenera
los STL (la caja crece a 54,8 mm de fondo).

> Esto es un cálculo a partir de las medidas del diseño. Mide un panel
> real terminado con calibre antes de imprimir la caja.

## 4. Impresión

- **Material: PETG**, por coherencia con el resto del proyecto. La caja
  no recibe calor del equipo, así que PLA también valdría.
- Sin soportes.
- Caja: apoyada por su base. Tapa: boca abajo (ya viene girada en
  `part = "print"`).
- Parámetros orientativos: capa 0,20 mm, 3-4 perímetros, relleno 15-20 %.
- **Holguras**: `lid_clr` = 0,3 mm por lado entre tapa y caja, `clr_t` =
  1 mm de holgura por ranura. Se diseñaron con PLA+ y **no se han
  validado con PETG**. Si la tapa queda dura, sube `lid_clr` a 0,4; si
  un panel aprieta en su ranura, sube `clr_t`.

## 5. Regenerar los STL

```bash
cd "openscad/parts/Caja paneles NFC"
openscad -o ../../../STL/caja_nfc_panel_caja.stl -D 'part="box"' caja_nfc_panel.scad
openscad -o ../../../STL/caja_nfc_panel_tapa.stl -D 'part="lid"' caja_nfc_panel.scad
openscad -o ../../../STL/caja_nfc_panel_caja_y_tapa.stl -D 'part="print"' caja_nfc_panel.scad
```

Con `part = "assembly"` se ve la caja montada, con bloques de ejemplo
dentro (`show_pieces`).

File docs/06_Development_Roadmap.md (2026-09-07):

\# SteamMachine UM790

\# 06 - Development Roadmap

Version: 1.0

Status: Active

\---

\# Objetivo

Este documento define la planificación completa del proyecto SteamMachine UM790.

El objetivo es disponer de un sistema completamente funcional basado en un MiniPC UM790 Pro alojado en una carcasa con las dimensiones originales de Steam Machine, controlado mediante paneles NFC intercambiables.

Cada fase deberá quedar completamente terminada antes de comenzar la siguiente.

\---

\# Estado actual

\## Hardware

\- ✔ Medidas reales recopiladas

\- ✔ Componentes seleccionados

\- ✔ Arquitectura mecánica definida

\- ✔ Frontal definitivo aprobado

\- ✔ Montaje físico completado

\## Software

\- ✔ Arquitectura definida

\- ✔ Protocolo de comunicación definido

\- ✔ Arquitectura firmware definida

\- ✔ Firmware ESP32 implementado y validado en hardware real (compila, flashea y arranca; protocolo boot/error confirmado por monitor serie)

\- ✔ SteamMachine Core implementado, con tests unitarios

\- ✔ Arranque automático confirmado en hardware real (systemd)

\---

\# Fase 1

\## Ingeniería Mecánica

Objetivo

Completar el ensamblaje virtual.

Tareas

\- Implantación definitiva del UM790

\- Implantación del Noctua

\- Implantación del RC522

\- Implantación del ESP32

\- Implantación del HUB USB

\- Implantación del OLED

\- Implantación del pulsador

\- Implantación de los USB frontales

Resultado esperado

virtual\_assembly\_v1.scad completamente validado.

Estado

🟡 En desarrollo

\---

\# Fase 2

\## Bastidor inferior

Objetivo

Diseñar la estructura principal del equipo.

Incluye

\- Soportes UM790

\- Soporte HUB

\- Soporte ESP32

\- Soporte RC522

\- Insertos roscados

\- Conductos de cableado

\- Entradas de aire

Resultado

chassis\_lower.scad

Estado

Pendiente

\---

\# Fase 3

\## Bastidor superior

Objetivo

Diseñar la estructura superior.

Incluye

\- Soporte Noctua

\- Rejillas

\- Salida de aire

\- Rigidez estructural

Resultado

chassis\_upper.scad

Estado

Pendiente

\---

\# Fase 4

\## Panel trasero

Objetivo

Diseñar el panel posterior.

Incluye

\- HDMI

\- USB

\- RJ45

\- Audio

\- Alimentación

\- Tornillería

Resultado

rear\_panel.scad

Estado

Pendiente

\---

\# Fase 5

\## Frontal

Objetivo

Diseñar el frontal definitivo.

Incluye

\- OLED

\- Pulsador

\- USB

\- Barra LED

\- Panel inferior

Resultado

front\_panel.scad

Estado

Pendiente

\---

\# Fase 6

\## Paneles NFC

Objetivo

Diseñar los paneles intercambiables.

Características

\- Imán de fijación

\- Alojamiento del tag NFC

\- Logotipo en relieve

\- Sistema de extracción

Resultado

front\_panel\_steam.scad

front\_panel\_retrobat.scad

front\_panel\_rpcs3.scad

...

Estado

Pendiente

\---

\# Fase 7

\## Firmware ESP32

Objetivo

Programar el controlador.

Funciones

\- RC522

\- OLED

\- LEDs

\- Pulsador

\- Serie USB

Estado

Completado (ver firmware/, ESP32-WROOM-32D DevKit sobre PlatformIO/Arduino). Validado en hardware real: compila, flashea y arranca correctamente, y el RC522, la barra LED (8 LEDs, directo sin nivelador), el pulsador (GPIO13), la OLED y la recuperación tras reinicio ya funcionan probados en el hardware real. Todas las pruebas de firmware de docs/10_Test_Plan.md superadas.

\---

\# Fase 8

\## SteamMachine Core

Objetivo

Aplicación principal para Bazzite (Linux).

Funciones

\- Comunicación serie

\- Base de datos NFC

\- Lanzador

\- Gestión OLED

\- Gestión LEDs

\- Configuración

Estado

Completado (ver software/), con tests unitarios para todos los modulos (LEDManager, OLEDManager, Application, PanelDatabase, Launcher). Validado de extremo a extremo en hardware real (2026-08-25, PC Windows de pruebas, ESP32 real por USB): detecta panel NFC, actualiza OLED y LEDs, y responde al pulsador lanzando la plataforma correspondiente (el lanzamiento en sí falla en Windows por no tener steam/retrodeck/teknoparrot instalados, esperado — la lógica del Core es lo que se valida aquí, no las plataformas). Pendiente: ejecutarlo en el mini PC real con Bazzite.

\---

\# Fase 9

\## Integración

Objetivo

Montaje completo.

Incluye

\- Cableado

\- Firmware

\- Software

\- Pruebas

Estado

Cableado, firmware y software completados. Pendiente la primera prueba con hardware real (ver checklist en firmware/README.md, sección "Prueba de integracion").

\---

\# Fase 10

\## Optimización

Objetivo

Mejorar la experiencia de usuario.

Incluye

\- Animaciones

\- Arranque automático

\- Actualizaciones

\- Diagnóstico

\- Plugins

Estado

Animaciones y diagnóstico completados. Arranque automático (systemd) documentado en software/README.md y confirmado en hardware real (2026-09-06, mini PC con Bazzite: `systemctl --user status steammachine.service` → `active (running)`). Actualizaciones y plugins adicionales, pendientes.

\---

\# Criterios de aceptación

Cada fase deberá cumplir:

\- Sin errores de compilación.

\- Documentación actualizada.

\- Archivos STL generados cuando corresponda.

\- Validación funcional.

\- Commit en GitHub.

\---

\# Gestión de versiones

Major

Cambios estructurales.

Minor

Nuevas funciones.

Patch

Correcciones.

Ejemplo

1.0.0

1.1.0

1.1.3

2.0.0

\---

\# Riesgos

Hardware

\- Temperatura

\- Interferencias NFC

\- Longitud de cableado

\- Rigidez del chasis

Software

\- Comunicación serie

\- Gestión de errores

\- Compatibilidad Bazzite / actualizaciones de RetroDECK y RetroArch

\- Actualizaciones

\---

\# Próximo objetivo

Completar al 100 % el ensamblaje virtual antes de comenzar el diseño del bastidor.

Ninguna pieza imprimible deberá diseñarse hasta validar completamente la implantación de todos los componentes.

\---

\# Estado del proyecto

Arquitectura: ██████████ 100%

Documentación: █████████░ 90%

Ensamblaje virtual: ███████░░░ 70%

Diseño mecánico: ██░░░░░░░░ 20%

Firmware: ░░░░░░░░░░ 0%

Software PC: ░░░░░░░░░░ 0%

Integración: ░░░░░░░░░░ 0%

Proyecto global: ████░░░░░░ 40%

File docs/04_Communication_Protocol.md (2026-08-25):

\# SteamMachine UM790

\# 04 - Communication Protocol

Version: 1.0

Status: Draft

\---

\# Objetivo

Este documento define el protocolo de comunicación entre el PC (SteamMachine Core) y el controlador ESP32.

El protocolo pretende ser:

\- sencillo

\- legible

\- extensible

\- independiente del hardware

Toda la comunicación se realiza mediante USB Serie.

\---

\# Configuración del puerto serie

Puerto

Automático (detección por VID/PID)

Velocidad

115200 baudios

Bits

8

Paridad

None

Stop

1

Control de flujo

No

\---

\# Filosofía

El ESP32 únicamente actúa como un dispositivo inteligente de entrada/salida.

Nunca decide qué programa ejecutar.

Toda la lógica reside en el PC.

\---

\# Formato de mensajes

Todos los mensajes utilizan JSON.

Cada línea finaliza con:

LF

Ejemplo:

```text

{"event":"button"}

```

\---

\# ESP32 → PC

\## Tag detectado

```json

{

&#x20;   "event":"tag",

&#x20;   "uid":"04A1C8B2"

}

```

Descripción

Se envía inmediatamente al detectar un nuevo panel NFC.

\---

\## Tag retirado

```json

{

&#x20;   "event":"tag\_removed"

}

```

\---

\## Pulsador

```json

{

&#x20;   "event":"button"

}

```

\---

\## Inicio

```json

{

&#x20;   "event":"boot",

&#x20;   "firmware":"1.0.0"

}

```

\---

\## Error

```json

{

&#x20;   "event":"error",

&#x20;   "code":5

}

```

\---

\# PC → ESP32

\## Mostrar texto OLED

```json

{

&#x20;   "cmd":"oled",

&#x20;   "text":"Steam"

}

```

\---

\## Mostrar dos líneas

```json

{

&#x20;   "cmd":"oled2",

&#x20;   "line1":"Steam",

&#x20;   "line2":"Ready"

}

```

\---

\## Limpiar OLED

```json

{

&#x20;   "cmd":"oled\_clear"

}

```

\---

\## Color LED

```json

{

&#x20;   "cmd":"led",

&#x20;   "color":"#0055FF"

}

```

\---

\## Brillo LED

```json

{

&#x20;   "cmd":"brightness",

&#x20;   "value":128

}

```

Valor

0-255

\---

\## Animación

```json

{

&#x20;   "cmd":"animation",

&#x20;   "name":"launch"

}

```

Animaciones previstas

\- idle

\- loading

\- launch

\- rainbow

\- error

\- success

\- shutdown

\---

\## Zumbador (futuro)

```json

{

&#x20;   "cmd":"beep",

&#x20;   "duration":150

}

```

\---

\## Reinicio ESP32

```json

{

&#x20;   "cmd":"restart"

}

```

\---

\## Estado / diagnóstico

```json

{

&#x20;   "cmd":"status"

}

```

Descripción

Solicita al ESP32 que responda con el evento `status` descrito en la sección "Diagnóstico".

\---

\# Tabla de eventos

| Evento | Origen | Descripción |

|---------|---------|-------------|

| boot | ESP32 | Arranque |

| tag | ESP32 | Panel detectado |

| tag\_removed | ESP32 | Panel retirado |

| button | ESP32 | Pulsador |

| error | ESP32 | Error |

| oled | PC | Mostrar texto |

| oled2 | PC | Mostrar dos líneas |

| oled\_clear | PC | Limpiar pantalla |

| led | PC | Cambiar color |

| brightness | PC | Cambiar brillo |

| animation | PC | Ejecutar animación |

| restart | PC | Reiniciar ESP32 |

| status | PC | Solicitar diagnóstico (uptime, memoria libre) |

| status | ESP32 | Respuesta al diagnóstico solicitado |

\---

\# Códigos de error

| Código | Significado |

|----------|-------------|

| 1 | RC522 no encontrado |

| 2 | OLED no encontrada |

| 3 | Error LED |

| 4 | Error memoria |

| 5 | Error desconocido |

\---

\# Secuencia típica

```

ESP32 arranca

↓

boot

↓

PC responde

↓

oled "SteamMachine"

↓

led azul

↓

Usuario coloca panel

↓

tag

↓

PC busca perfil

↓

oled "Steam"

↓

led azul Steam

↓

Usuario pulsa botón

↓

button

↓

PC lanza Steam

↓

animation launch

↓

oled "Launching..."

```

\---

\# Compatibilidad

El firmware siempre enviará:

```

boot

```

incluyendo:

\- versión firmware

El PC podrá decidir si el firmware es compatible.

\---

\# Futuras ampliaciones

\- Control del ventilador

\- Lectura de temperatura

\- Medidor RPM

\- OTA

\- WiFi

\- Bluetooth

\- MQTT

\- Home Assistant

\- Diagnóstico remoto

\---

\# Estado

Versión 1.0

Se considera suficientemente estable para comenzar el desarrollo del firmware ESP32 y del SteamMachine Core.

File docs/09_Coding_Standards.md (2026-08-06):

\# SteamMachine UM790

\# 09 - Coding Standards

Version: 1.0

Status: Active

\---

\# Objetivo

Este documento define las normas de programación utilizadas en el proyecto SteamMachine UM790.

Su finalidad es garantizar:

\- Legibilidad.

\- Uniformidad.

\- Escalabilidad.

\- Facilidad de mantenimiento.

\- Facilidad de colaboración.

Todas las contribuciones deberán respetar estas normas.

\---

\# Lenguajes utilizados

\## OpenSCAD

Diseño mecánico.

\---

\## Python

Software principal.

Versión mínima

Python 3.12

\---

\## C++

Firmware ESP32

Framework

Arduino ESP32

\---

\# Organización del proyecto

```

SteamMachine-UM790/

docs/

openscad/

software/

firmware/

resources/

stl/

```

Nunca deberán mezclarse archivos de distintas disciplinas.

\---

\# Convenciones de nombres

\## Archivos

Siempre

snake\_case

Correcto

```

panel\_database.py

serial\_manager.py

front\_panel.scad

```

Incorrecto

```

PanelDatabase.py

FrontPanel.scad

serialManager.py

```

\---

\# Clases Python

Siempre

PascalCase

```

SteamMachine

SerialManager

PanelDatabase

Launcher

```

\---

\# Métodos

Siempre

snake\_case

```

load\_configuration()

launch\_platform()

read\_tag()

```

\---

\# Variables

Siempre

snake\_case

```

panel\_uid

serial\_port

current\_theme

```

\---

\# Constantes

Siempre

UPPER\_CASE

```

SERIAL\_SPEED

MAX\_RETRIES

DEFAULT\_THEME

```

\---

\# OpenSCAD

\## Archivos

Un módulo importante por archivo.

Ejemplo

```

um790.scad

rc522.scad

esp32.scad

noctua.scad

```

\---

\# Módulos

Siempre

snake\_case

```

module rc522()

module esp32()

module oled()

```

\---

\# Variables OpenSCAD

Siempre

snake\_case

```

wall\_thickness

panel\_height

fan\_offset

```

\---

\# Comentarios

Cada archivo comenzará con

```

//

// SteamMachine UM790

//

// Nombre del módulo

//

// Descripción

//

```

\---

\# Comentarios de sección

```

//////////////////////////////////////////////////////

// RC522 SUPPORT

//////////////////////////////////////////////////////

```

\---

\# Longitud de líneas

Python

Máximo

100 caracteres

OpenSCAD

Preferiblemente

100 caracteres

\---

\# Indentación

Python

4 espacios

Nunca TAB.

OpenSCAD

4 espacios.

\---

\# Documentación

Todas las clases públicas deberán incluir docstrings.

Ejemplo

```python

class SerialManager:

&#x20;   """

&#x20;   Gestiona la comunicación entre el PC y el ESP32.

&#x20;   """

```

\---

\# Manejo de errores

Nunca ignorar excepciones.

Incorrecto

```python

except:

&#x20;   pass

```

Correcto

```python

except Exception as e:

&#x20;   logger.error(e)

```

\---

\# Logging

No utilizar print() para depuración permanente.

Siempre

```

logger.debug()

logger.info()

logger.warning()

logger.error()

logger.critical()

```

\---

\# Configuración

Nunca escribir parámetros directamente en el código.

Siempre utilizar

```

config.json

themes.json

launcher.json

```

\---

\# Arquitectura

Cada clase tendrá una única responsabilidad.

Ejemplos

Correcto

```

SerialManager

OLEDManager

LEDManager

```

Incorrecto

```

ESP32EverythingManager

```

\---

\# Dependencias

Las dependencias deberán mantenerse al mínimo.

Solo se añadirán cuando exista una ventaja clara.

\---

\# Commits Git

Formato

```

tipo: descripción

```

Ejemplos

```

feat: add RC522 support

fix: correct OLED alignment

docs: update firmware architecture

refactor: simplify launcher

test: add collision validation

```

\---

\# Tipos permitidos

```

feat

fix

docs

refactor

style

test

build

chore

```

\---

\# Ramas

Principal

```

main

```

Desarrollo

```

develop

```

Características

```

feature/chassis

feature/firmware

feature/launcher

```

Correcciones

```

hotfix/serial

hotfix/oled

```

\---

\# Versionado

Semantic Versioning

```

Major.Minor.Patch

```

Ejemplo

```

1.0.0

1.1.0

1.1.2

2.0.0

```

\---

\# Recursos gráficos

Todos los iconos

PNG

Fondo transparente

Resolución recomendada

256×256

\---

\# STL

Nombre

```

front\_panel\_v1.stl

rear\_panel\_v2.stl

foot\_left\_v1.stl

```

Nunca

```

pieza\_final2\_ok.stl

```

\---

\# OpenSCAD

No utilizar números mágicos.

Incorrecto

```

translate(\[18,32,6])

```

Correcto

```

translate(\[

&#x20;   panel\_offset\_x,

&#x20;   panel\_offset\_y,

&#x20;   support\_height

])

```

\---

\# TODO

Las tareas pendientes utilizarán

```python

\# TODO:

```

Nunca

```

\# arreglar después

```

\---

\# Filosofía

Antes de escribir código:

\- Diseñar.

\- Documentar.

\- Revisar.

Después:

\- Programar.

\- Probar.

\- Integrar.

Nunca al revés.

\---

\# Regla de oro

No diseñar una pieza mecánica sin haber validado previamente el ensamblaje virtual.

No escribir firmware sin protocolo definido.

No escribir software sin API definida.

Toda decisión importante deberá quedar documentada.

\---

\# Estado

Documento activo.

Será actualizado conforme evolucione el proyecto.

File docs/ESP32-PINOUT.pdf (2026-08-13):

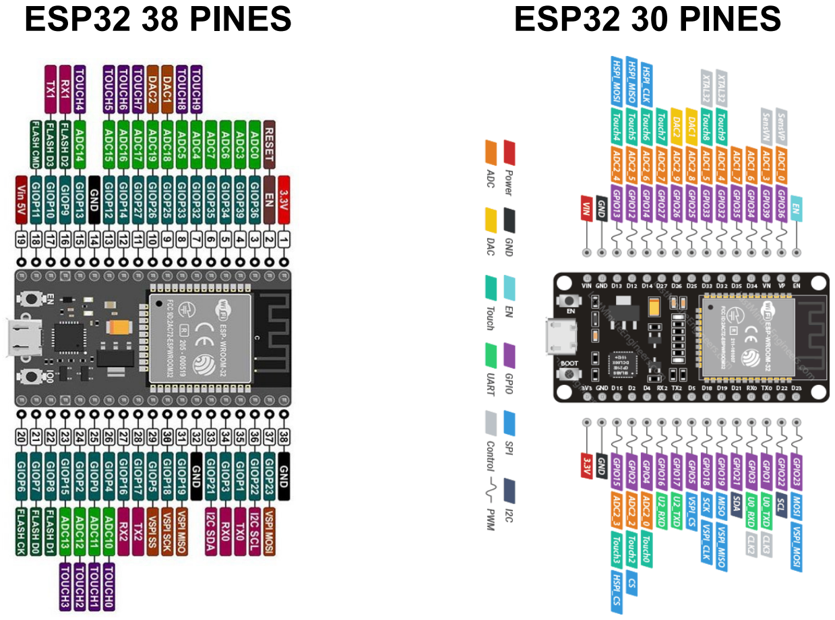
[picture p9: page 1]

ESP32 38 PINES | ESP32 30 PINES

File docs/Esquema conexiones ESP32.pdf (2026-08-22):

Hoja1

Página 1

| | RC522 | ESP32 | Tira WS2812B | Conexión
3V3 | GND | SDA | GPIO 5 | +5V | 5V/VIN
----- | EN | ------------ | EN

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
D23 | ------------ | P23 ----- | RC522-MOSI | SCK | GPIO 18 | GND | GND
----- SVP | ------------ | VP | D22 | ------------ | P22 ----- | OLED-SCL | MOSI | GPIO 23 | DIN | GPIO25
----- SVN | ------------ | VN | TX0 | ------------ | TX | ----- | MISO | GPIO 19 | DOUT | Sin conectar
----- P34 | ------------ | D34 | RX0 | ------------ | RX | ----- | RST | GPIO 27
----- P35 | ------------ | D35 | D21 | ------------ | P21 ----- | OLED-SDA | IRQ | NC
----- P32 | ------------ | D32 | D19 | ------------ | GND ----- | RC522-MISO | 3V2 | 3V3
----- P33 | ------------ | D33 | D18 | ------------ | P19 ----- | RC522-SCK | GND | GND
WS2812B-DIN | ----- P25 | ------------ | D25 | D5 | ------------ | P18 ----- | RC522-SDA
----- P26 | ------------ | D26 | D17 | ------------ | P5 | ----- | OLED | ESP32
RC522-RST | ----- P27 | ------------ | D27 | D16 | ------------ | P17 ----- | VCC | 3V3
----- P14 | ------------ | D14 | D4 | ------------ | P16 ----- | GND | GND
----- P12 | ------------ | D12 | D2 | ------------ | P4 | ----- | SDA | GPIO 21 / D21
----- GND | ------------ | D13 | D15 | ------------ | P0 | ----- | SCL | GPIO 22 / D22
WS2812B-GND | ----- P13 | ------------ | GND | GND | ------------ | P2 | ----- | RC522-GND | OLED-GND
WS2812B-+5V | ----- SD2 | ------------ | VIN | 3V3 | ------------ | P15 ----- | RC522- 3V2 | OLED-VCC
----- SD3 | SD1 -----
----- GND | SD0 -----
----- | 5V | CLK -----

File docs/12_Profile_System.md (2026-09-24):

# SteamMachine UM790

# 12 - Profile System (panel = perfil, no panel = programa)

Version: 0.4 (STEAM, RETRO, DISPAROS, MAINTENANCE, APAGAR y AUTO implementados;
KODI/MUSIC/DESKTOP/NIGHT/DEMO siguen siendo huecos reservados)
Status: Implementado — alcance completo de la v0.2 original en código
y con tests; ver "Pendiente" para los refinamientos que quedan

---

# Objetivo

Sustituir el modelo actual, en el que cada panel NFC apunta directamente
a un `launcher` (un programa: `steam`, `retrodeck`, `hotd_remake`...),
por un modelo de **perfiles**: cada panel apunta a un perfil, y un
perfil agrupa todo el comportamiento asociado — qué aplicación lanza,
qué se muestra en la OLED (en reposo y en ejecución), qué hacen los
LEDs, y en el futuro qué política de ventilación o de botones aplica.

Esto no es una reescritura: es una capa por encima del `Launcher` y los
`OLEDManager`/`LEDManager` actuales (`08_Software_API.md`), pensada para
no romper los paneles que ya funcionan.

---

# Por qué ahora

Con Steam, RetroDECK, RetroArch y los dos paneles de Zombies ya
conviviendo, `panel_database.json` empieza a mezclar dos cosas
distintas bajo el mismo campo `launcher`: "qué programa abrir" y, cada
vez más, "cómo se comporta la máquina mientras ese programa está
activo". El perfil `MAINTENANCE` (panel pensado para desarrollo, sin
lanzar ningún programa, solo mostrar telemetría) es el caso que deja
más claro que un panel NFC no siempre corresponde a "abrir X" — a
veces corresponde a "ponte en este modo".

---

# Modelo de datos

## Perfil (nuevo)

Cada perfil vive en su propio fichero JSON, en
`software/config/profiles/<id>.json`. Añadir un perfil nuevo = añadir
un fichero; no requiere tocar `launcher.py` **si** el perfil reutiliza
un `launcher` ya existente (Steam, RetroArch...). Si el perfil necesita
lanzar un programa nuevo, sigue haciendo falta un plugin nuevo de
`BasePlugin`, igual que hoy — el sistema de perfiles no elimina esa
capa, la organiza mejor.

```json
{
  "id": "RETRO",
  "name": "Retro (SNES / PS2)",
  "launcher": "retrodeck",
  "led": {
    "idle": "#8800FF",
    "running": "#8800FF"
  },
  "oled": {
    "idle": ["STEAM MACHINE", "RETRO · SNES/PS2"],
    "running_template": ["{game_name}", "{elapsed_time}"]
  },
  "status_provider": "retroarch_network_commands"
}
```

- `launcher`: igual que el campo actual de `panel_database.json` —
  la clave que ya usa `Launcher.launch()`.
- `led.idle` / `led.running`: color en reposo y color mientras el
  programa está activo (hoy solo existe un color por panel; separarlo
  permite, por ejemplo, que LEDs cambien de color al empezar a jugar).
  La animación de lanzamiento (`_on_button()`) se queda fija en
  `"launch"` para todos los perfiles — decidido explícitamente
  (2026-09-03) en vez de hacerla configurable por perfil, ver
  "Decisiones cerradas" al final.
- `oled.idle`: líneas a mostrar mientras el panel está puesto pero el
  programa no se ha lanzado (o no se está monitorizando).
- `oled.running_template`: líneas a mostrar mientras el programa está
  en marcha, con marcadores `{variable}` — ver "Motor de plantillas"
  más abajo.
- `status_provider`: opcional. Nombre de un componente que alimenta las
  variables de `running_template` en vivo (ver más abajo). Si se omite,
  `running_template` no se usa y la OLED se queda en `oled.idle` todo
  el rato.

## `panel_database.json` (cambio mínimo, retrocompatible)

```json
{
  "04B2D9C3": {
    "name": "RetroDECK",
    "profile": "RETRO",
    "led": "#8800FF",
    "icon": "retrodeck.png"
  }
}
```

Se añade el campo `profile` (opcional). Si un panel no lo tiene,
**sigue funcionando exactamente igual que hoy**, usando `launcher`
directamente como hasta ahora — no hace falta migrar todos los paneles
de golpe. `name`, `led` e `icon` se mantienen como override manual por
panel (por si dos paneles distintos comparten perfil pero quieres un
color de LED o un nombre distinto en cada uno — p. ej. dos paneles
`DISPAROS` para HOTD Remake y HOTD 2 Remake, ambos con `profile:
"DISPAROS"` pero `launcher` distinto).

---

# Motor de plantillas de OLED — limitación real a tener en cuenta

**El protocolo actual solo admite 2 líneas de texto** (`04_Communication_Protocol.md`,
comandos `oled` / `oled2`) — así lo implementa `OLEDManager.show_status(line1, line2)`
hoy mismo. Los mockups de 5 líneas de la propuesta original (título,
línea en blanco, subtítulo, línea en blanco, valor) no caben en el
firmware tal como está ahora mismo.

Para la v0.2, el motor de plantillas trabaja con **listas de como
mucho 2 elementos** (una por línea física), por ejemplo:

```
"idle":             ["STEAM MACHINE", "RETRO · SNES/PS2"]
"running_template": ["{game_name}", "{elapsed_time}"]
```

Ampliar el firmware/protocolo a más líneas (o a un modo de texto libre
con saltos de línea) es una tarea de firmware aparte, no de este
sistema de perfiles — lo dejo anotado en "Pendiente" al final, pero no
lo doy por hecho aquí.

---

# LEDs por perfil

No hace falta ampliar `LEDManager`: ya expone `set_color()` y
`animation(name)` con el conjunto fijo de animaciones del firmware. El
perfil simplemente **elige** entre lo que ya existe (`led.idle`,
`led.running`), igual que hoy panel_database.json ya elige un color
por panel — el único cambio es que ahora puede haber un color distinto
para "reposo" y para "en marcha". La animación de lanzamiento
(`_on_button()`) NO es configurable por perfil — ver "Decisiones
cerradas" al final.

---

# Precedencia NFC físico vs. perfil AUTO

**Decisión (2026-09-03, confirmada por el usuario): AUTO se activa
cuando no hay ningún panel físico puesto — no es un panel propio con
su propio tag NFC.**

Con AUTO, hay dos fuentes que pueden decidir el estado de la máquina:
el panel físico insertado y lo que Bazzite está ejecutando en cada
momento. Regla:

1. **Si hay un panel físico insertado, ese panel manda siempre.** AUTO
   no puede "override-ar" un panel físico puesto a mano — si tienes el
   panel RETRO puesto y abres Kodi desde el escritorio, la OLED/LEDs
   se quedan en modo RETRO. AUTO no vigila en ese caso.
2. **En cuanto se retira el panel (sin ninguno puesto), entra AUTO.**
   No hace falta un tag NFC ni una entrada en `panel_database.json`
   para AUTO — es el estado por defecto de "sin panel", no un perfil
   seleccionable por NFC.
3. Cuando AUTO está activo, un componente nuevo (`ProcessWatcher`,
   pendiente de diseñar) hace polling periódico de qué proceso relevante
   está corriendo en Bazzite (Steam, RetroArch, Kodi...) y dispara el
   perfil correspondiente — mismo mecanismo de "cargar perfil" que
   usa un panel físico, solo que el disparador es un proceso detectado
   en vez de un tag NFC.

## Implicación en `core/application.py`

Con esta decisión, el cambio de comportamiento cae directamente en
`_on_tag_removed()` (hoy: `oled.sleep()` + `leds.fade(IDLE_COLOR)`, sin
más) y en `_on_tag_detected()`:

- `_on_tag_removed()` deja de ser un simple "apagar y esperar" — pasa a
  **arrancar el `ProcessWatcher`** (entra en AUTO) en vez de solo poner
  la OLED en reposo.
- `_on_tag_detected()` sigue igual que ahora (carga el perfil del
  panel), pero además debe **detener el `ProcessWatcher`** si estaba
  corriendo, para que AUTO no siga compitiendo por la OLED/LEDs
  mientras hay un panel físico puesto.
- No se crea ninguna clave nueva en `panel_database.json` para AUTO —
  AUTO no tiene UID, es lo que pasa cuando `_pending_panel` está vacío.

---
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

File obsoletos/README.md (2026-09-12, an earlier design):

# Archivos obsoletos

Esta carpeta reúne archivos que ya no forman parte activa del
proyecto — no los usa ningún `use`/`include` real desde ningún
archivo activo (verificado antes de moverlos). Se conservan como
referencia histórica del proceso de diseño, no para imprimir ni
para usarse como base de nada nuevo.

Movidos aquí el 2026-08-14, a petición del usuario, tras una
revisión completa del repositorio. Estructura original preservada
en subcarpetas.

## parts_03_panels/

- **front_panel.scad** — ya marcado ⚠️ OBSOLETO en el propio
  archivo desde el 2026-08-03. Combinaba en una sola pieza lo que
  el ensamblaje virtual v1 determinó que debían ser dos piezas
  separadas. Sustituido por `openscad/parts/03_panels/lower_panel.scad`
  y `nfc_panel.scad`.
- **front_layout.scad** — ya marcado ⚠️ OBSOLETO. Plano de
  distribución del frontal con medidas desactualizadas (USB de
  boceto, panel NFC de 70mm). Sustituido por `lower_panel.scad` y
  `nfc_panel.scad` (piezas reales).
- **rc522_bracket_v1.scad** (renombrado desde `rc522_bracket.scad`
  para no chocar con el nombre actual) — versión 1.0 del soporte
  del lector RC522, con el taladro de tornillo mal orientado (no
  coincidía con el eje real del poste de anclaje). Sustituida por
  completo por la v2.0 en `openscad/parts/04_soportes/rc522_bracket.scad`,
  que es la que se usa realmente.
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

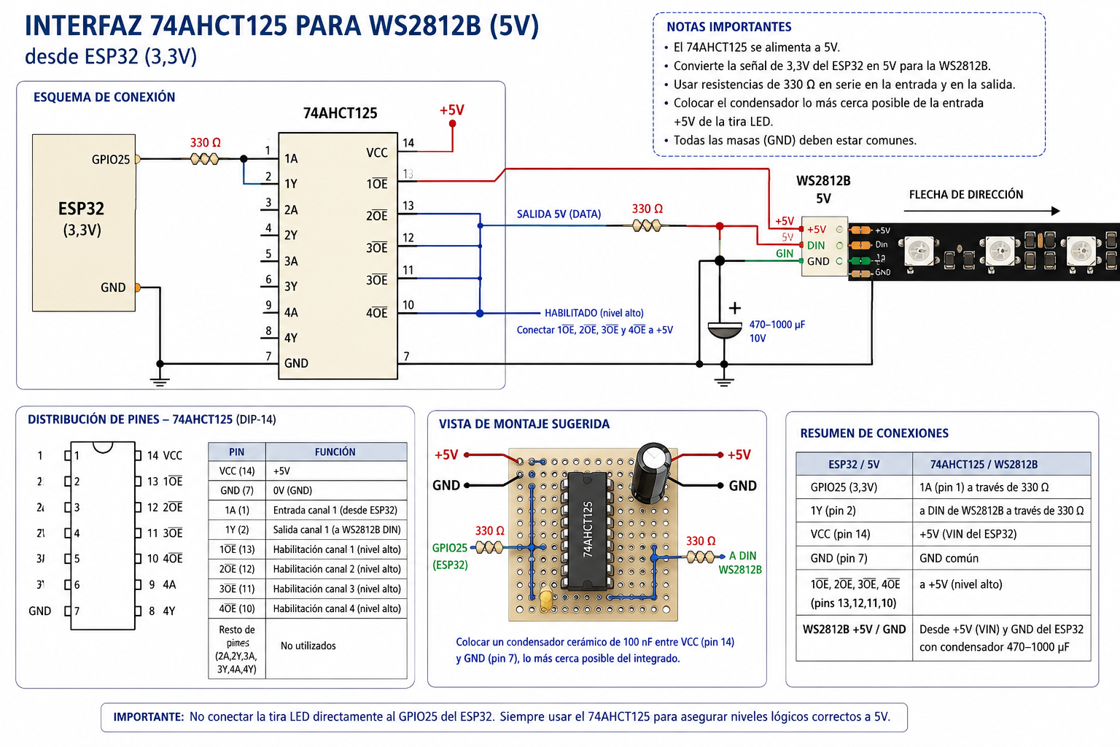
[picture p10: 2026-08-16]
docs/74AHCT125.png

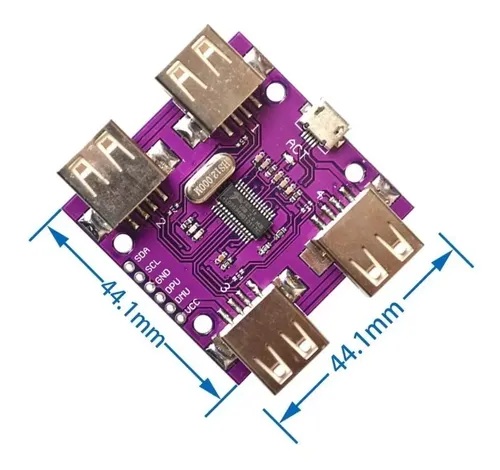
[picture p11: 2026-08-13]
docs/cjmcu-204.jpg

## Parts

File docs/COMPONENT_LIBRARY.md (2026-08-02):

| Componente  | Modelo | Estado |
| --- | --- | --- |
| UM790 Pro | Minisforum UM790 Pro | ✅ |
| Ventilador  | Noctua NF-A12x15 PWM | ✅ |
| ESP32 | ESP32 + adaptador bornes | ✅ |
| RC522 | MFRC522 | ✅ |
| Hub USB | USB Hub 4 puertos 44,1×44,1 | ✅ |
| USB frontal | USB doble Ø29 | ✅ |
| OLED | 27×27 mm | ✅ |
| Pulsador | M16 × 55 mm | ✅ |

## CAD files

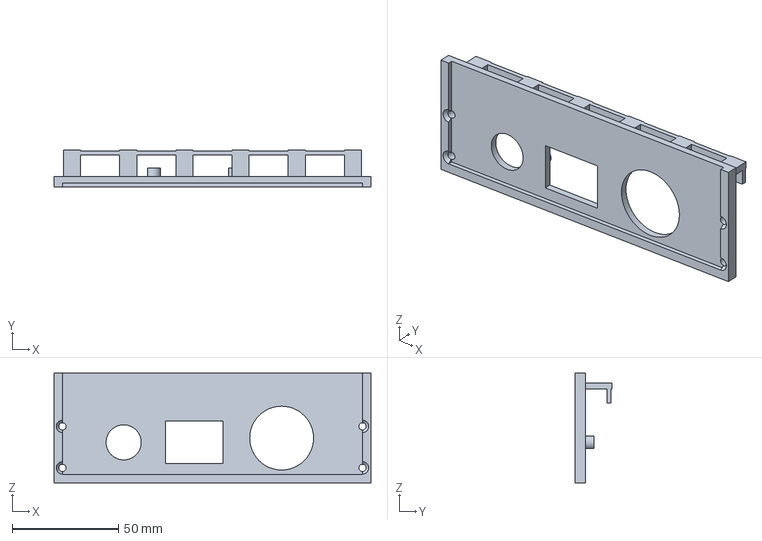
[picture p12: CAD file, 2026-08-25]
openscad/parts/03_panels/lower_panel.3mf
149.0 x 17.4 x 51.5 mm

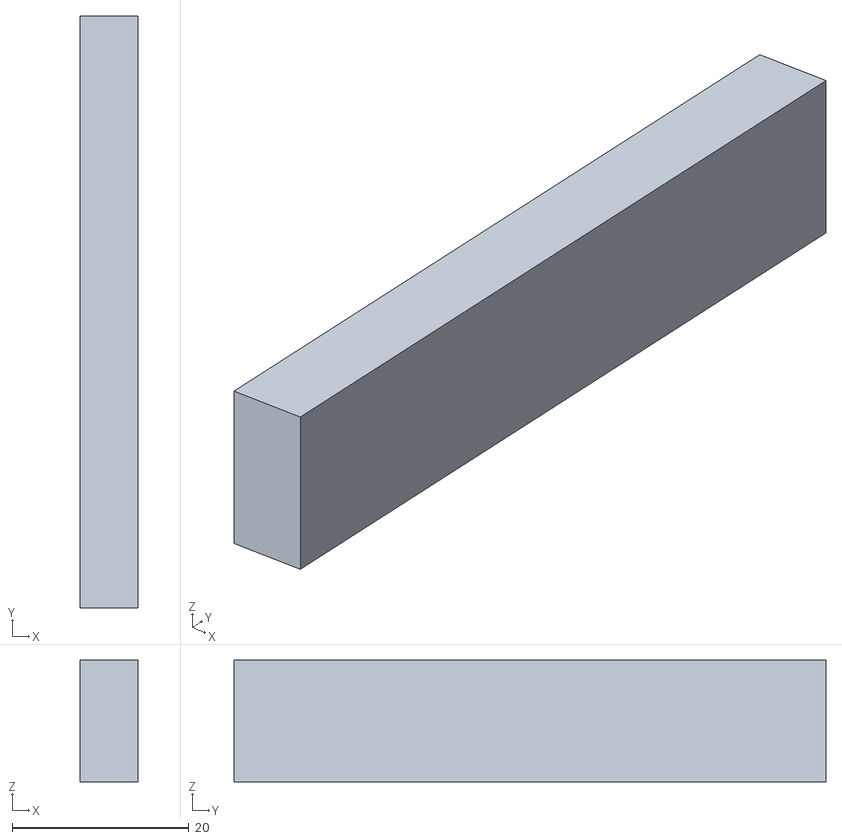
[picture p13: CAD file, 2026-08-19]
openscad/reference/checks/_generated/noctuaInstanceKeepout__vs__esp32InstanceBody.stl
6.60 x 67.0 x 13.8

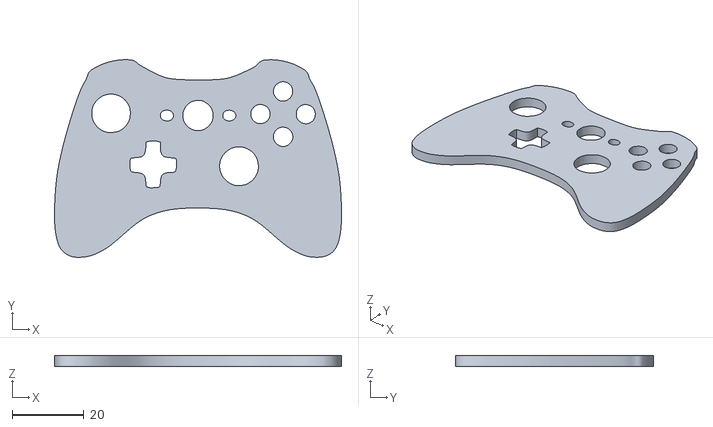
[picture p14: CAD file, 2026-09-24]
STL/Anagramas/Mando.stl
79.9 x 55.0 x 3.00

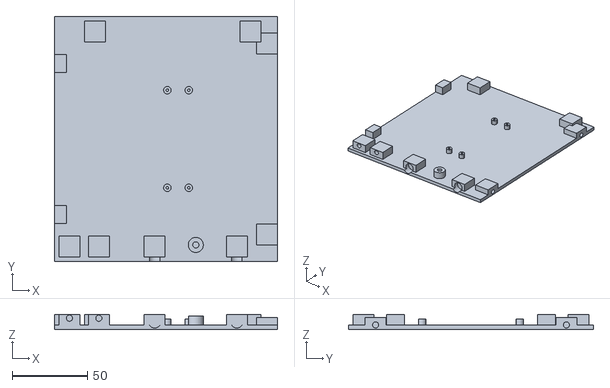
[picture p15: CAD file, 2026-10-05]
STL/rightwall_flat2.stl
148.0 x 162.4 x 10.0

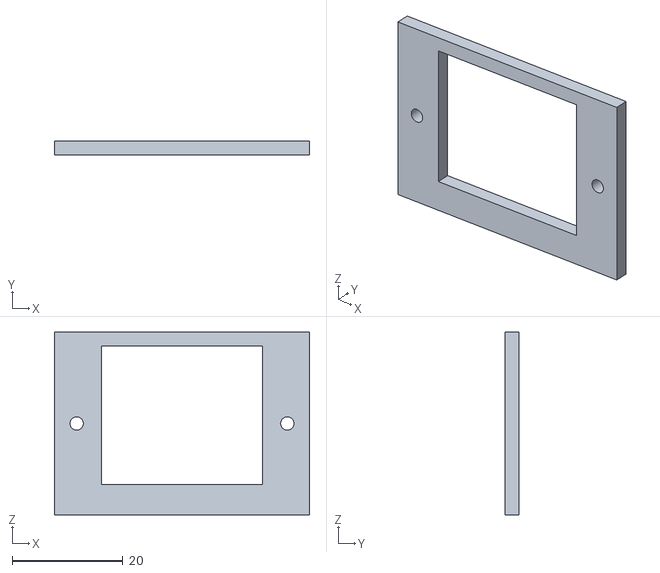
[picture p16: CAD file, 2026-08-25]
openscad/parts/03_panels/oled_bracket.stl
46.0 x 2.50 x 33.0

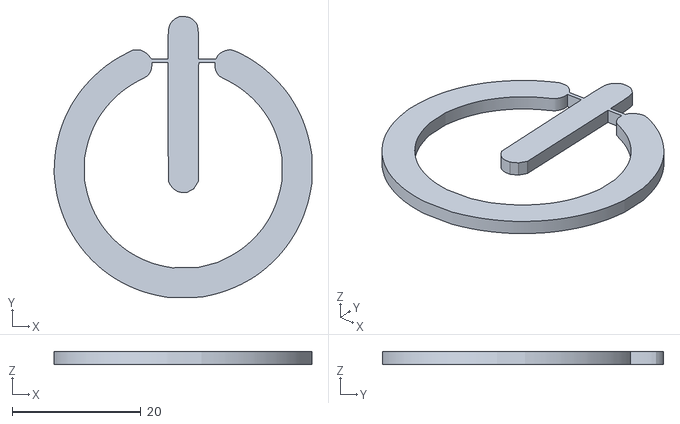
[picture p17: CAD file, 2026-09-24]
STL/Anagramas/Apagar.stl
40.0 x 43.6 x 2.00

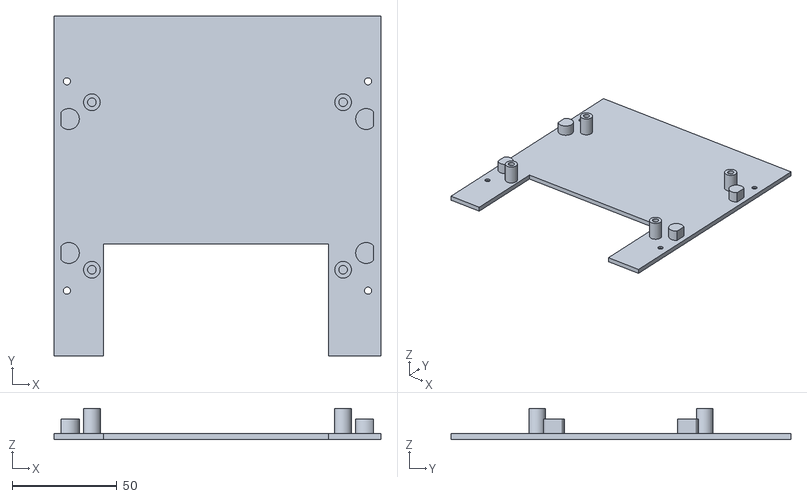
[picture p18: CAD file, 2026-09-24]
STL/floor_flat2.stl
156.0 x 162.4 x 15.0

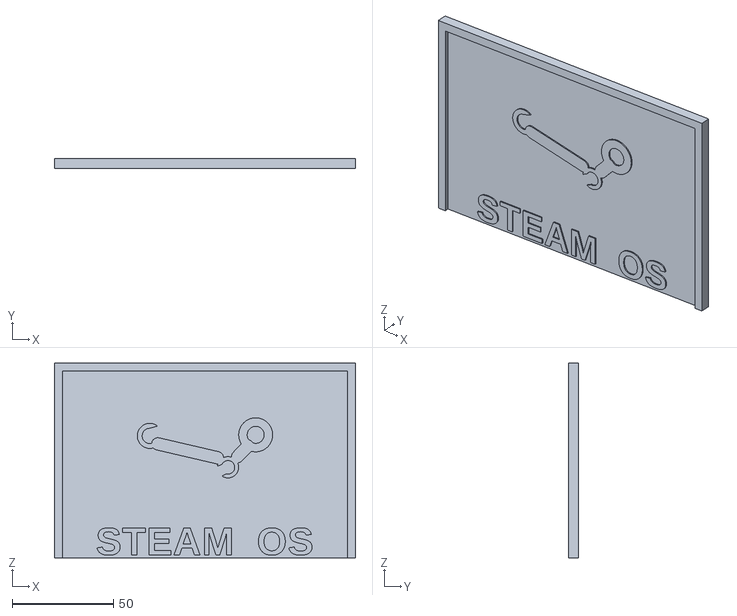
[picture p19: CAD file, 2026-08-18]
openscad/parts/03_panels/nfc_panel_Steam.stl
149.0 x 5.00 x 96.5

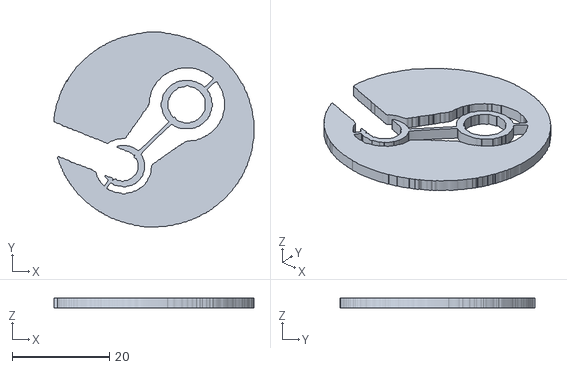
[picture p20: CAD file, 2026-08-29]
STL/Anagramas/Steam.stl
41.1 x 40.0 x 2.00

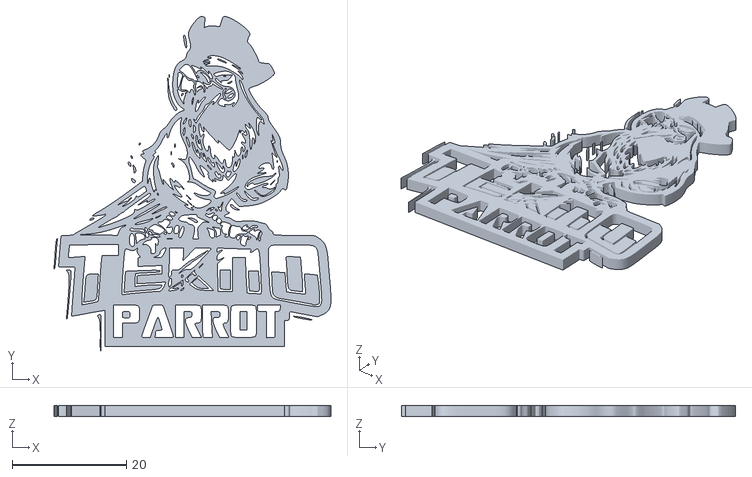
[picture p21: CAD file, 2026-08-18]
openscad/parts/03_panels/Teknoparrot.stl
48.6 x 58.6 x 2.00

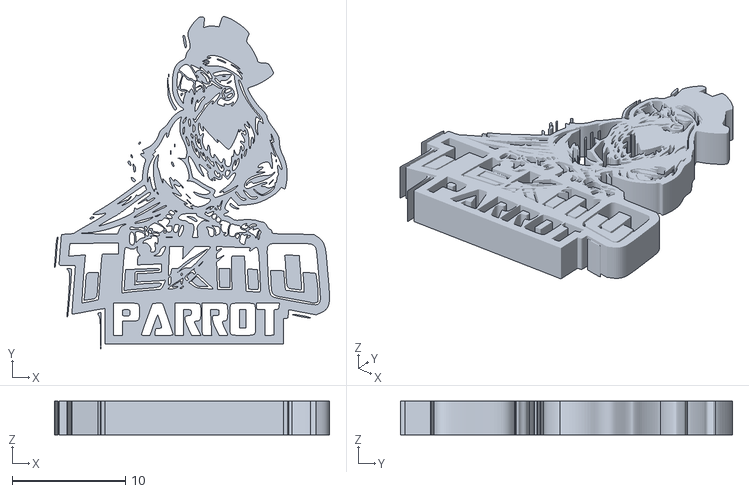
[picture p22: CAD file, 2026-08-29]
STL/Anagramas/Parrot.stl
24.3 x 29.3 x 3.00

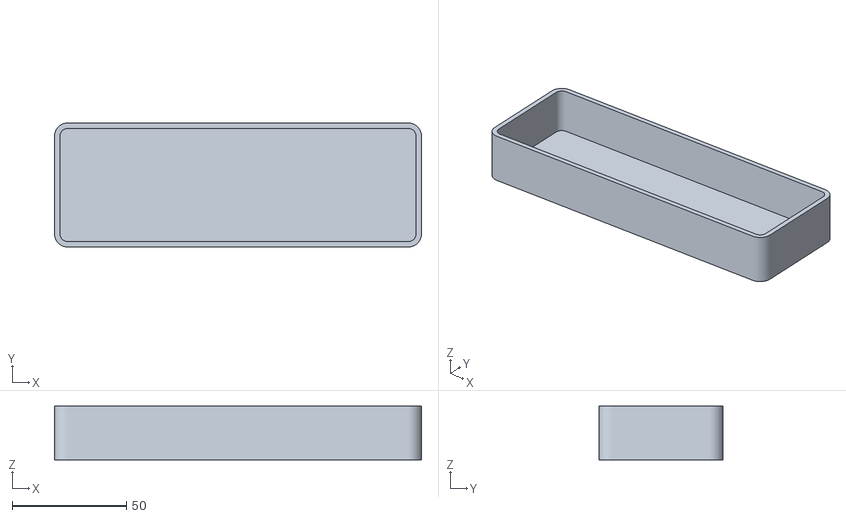
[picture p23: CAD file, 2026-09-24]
STL/caja_nfc_panel_tapa.stl
160.4 x 54.2 x 23.4

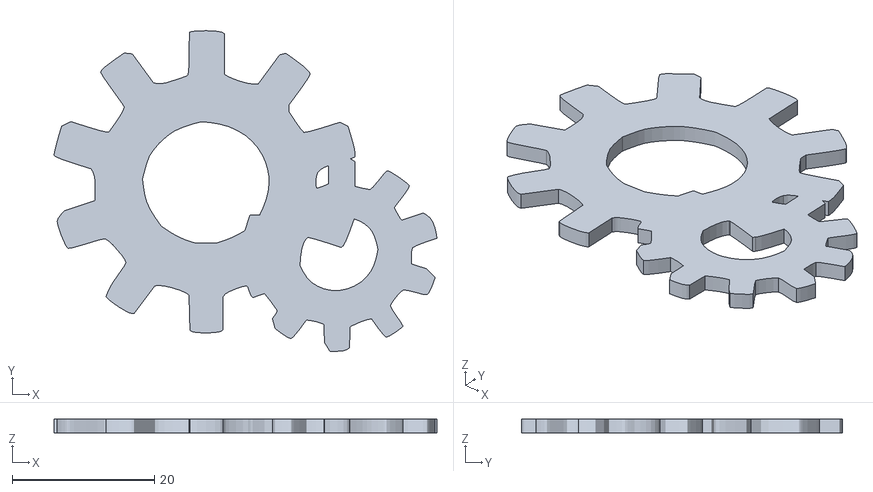
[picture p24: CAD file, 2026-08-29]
STL/Anagramas/engranaje.stl
53.8 x 45.0 x 2.00

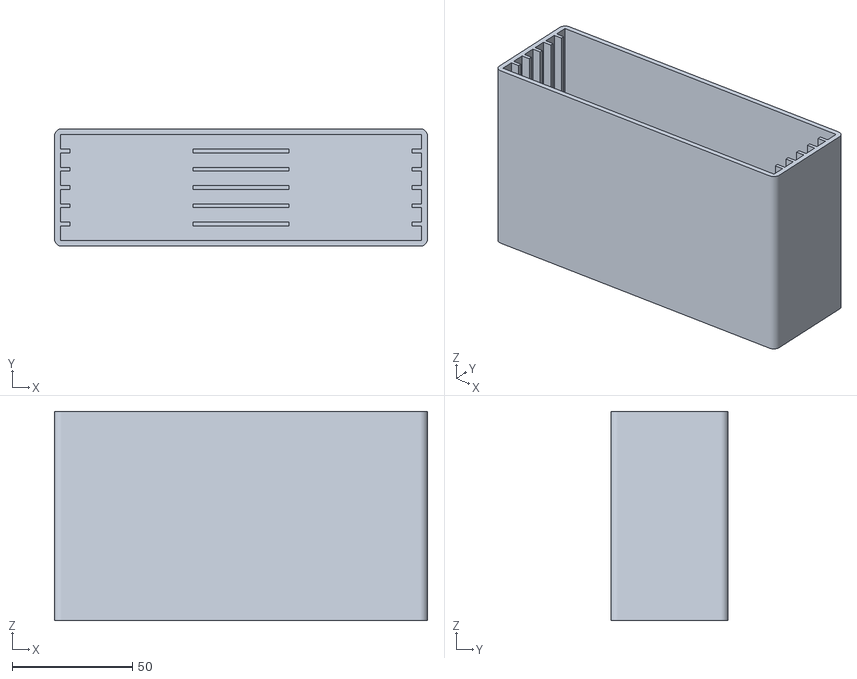
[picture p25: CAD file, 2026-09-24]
STL/caja_nfc_panel_caja.stl
155.0 x 48.8 x 86.9

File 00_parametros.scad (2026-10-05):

//
// ============================================================================
// SteamMachine UM790
// Project Phoenix
//
// Archivo : 00_parametros.scad
// Versión : 3.0
//
// ÚNICA fuente de parámetros del proyecto.
//
// ============================================================================

$fn = 64;

//=============================================================================
// INFORMACIÓN
//=============================================================================

project_name    = "SteamMachine UM790";
project_version = "3.0";

//=============================================================================
// CARCASA EXTERIOR (Steam Machine original)
//=============================================================================

case_width  = 156.0;
case_depth  = 162.4;
case_height = 152.0;   // altura EXTERIOR total, CON patas (dato original, sin modificar)

wall_thickness = 3.0;

bottom_thickness = 3.0;
top_thickness    = 3.0;

// Patas — CONFIRMADO por el usuario (2026-08-03): externas, 4 mm,
// añadidas por DEBAJO del cascarón (no van incluidas en la altura de
// trabajo interna). shell_height es la altura real del cascarón
// (suelo a techo) que usa todo el ensamblaje virtual y el chasis;
// case_height sigue siendo el dato exterior original de 152 mm.
//
// Antes de esta confirmación, todo el ensamblaje usaba case_height
// (152) directamente como altura de trabajo interna — ver
// docs/Virtual_Assembly_Report.md, sección "Patas externas (148/152 mm)".
leg_height   = 4.0;   // Dato real confirmado por el usuario (2026-08-03)
shell_height = case_height - leg_height;  // 148.0

//=============================================================================
// CÁMARA INFERIOR
//=============================================================================

lower_air_chamber = 12.0;

//=============================================================================
// BANDEJA
//=============================================================================

// tray_width — CORREGIDO (2026-08-03, pregunta del usuario: "¿podrá
// insertarse sin que nada se lo impida?"): con 150 mm (el hueco
// exacto entre paredes, sin holgura), la bandeja rozaba los rellenos
// de imanes/tornillos de las paredes laterales (sideBossPad() etc,
// que sobresalen 7 mm hacia el interior) durante el recorrido de
// bajada al insertarla — no en su posición final (eso ya estaba
// verificado sin colisión), sino en el TRAYECTO para llegar ahí.
// Reducido a 130 mm: dejando 3 mm de holgura a cada lado del canal
// libre entre rellenos (136 mm), y con margen de sobra respecto a
// los anclajes reales del UM790 (off_x = 56,5 mm). tray_depth NO
// necesita el mismo ajuste: el problema es solo con las paredes
// laterales (fijas), no con el frente/fondo (paneles separados, no
// son obstáculo durante la inserción vertical).
tray_width     = 130.0;
tray_depth     = 150.0;
tray_thickness = 3.0;

// Pilares de apoyo de la bandeja (openscad/parts/02_chassis/floor.scad,
// traySupportPosts()) y sus taladros de paso correspondientes en la
// propia bandeja (openscad/parts/01_bandeja/base.scad,
// trayScrewClearanceHoles()) — comparten estos valores para no
// desincronizarse.
//
// tray_support_inset_x = 5.0: con 12 mm de margen, el pilar caía en
// la zona HUECA de la bandeja (el marco macizo, base_frame_width =
// 10 mm, solo llega hasta 65 mm desde el centro; con inset=12 el
// pilar quedaba en X=63 mm, fuera de ese marco). Con inset=5, el
// pilar (Ø8 mm) queda centrado en X=70 mm, dentro del marco sólido
// [65,75] con margen a ambos lados.
//
// tray_support_inset_y = 35.0 (no el mismo valor que X): con el mismo
// inset en X e Y, el pilar (en la esquina, Y=70 mm) quedaba dentro
// de la zona de los rellenos de imanes/tornillos de la pared
// (sideBossPad()/rearBossPad(), que ocupan Y desde ±67,2 mm hasta el
// borde) — el relleno tapaba el hueco del inserto del pilar (aviso
// del usuario, 2026-08-03). Con Y=40 mm el pilar sigue sobre el marco
// sólido (basta con que X esté en la franja del marco) pero fuera de
// la franja de los rellenos.
tray_support_diameter = 8.0;
tray_support_inset_x  = 5.0;
tray_support_inset_y  = 35.0;

base_frame_width   = 10.0;
base_outer_chamfer = 4.0;
base_inner_chamfer = 4.0;

// Parámetros que faltaban (base.scad los usaba sin que existieran en
// este archivo — bandeja no renderizaba correctamente). Añadidos
// ahora, sin modificar ningún otro valor de la bandeja.
base_island_size  = 16.0;  // lado de cada isla de apoyo bajo los postes
base_bridge_width = 8.0;   // ancho de los refuerzos en cruz de la base

//=============================================================================
// PCB UM790
//=============================================================================

pcb_width     = 122.0;
pcb_depth     = 119.5;
pcb_thickness = 1.60;

um790_mount_spacing_x = 113.0;
um790_mount_spacing_y = 99.0;

//=============================================================================
// POSTES
//=============================================================================

// Altura de postes — RECONCILIADA con el valor confirmado por el
// usuario en el ensamblaje virtual v1 (docs/Virtual_Assembly_Report.md).
// Antes: 6.0 mm (no dejaba hueco suficiente para el pulsador/USB
// frontal tras el panel; ver informe, hallazgo de colisión con la PCB
// y los postes).
um790_post_height   = 20.0;
um790_post_diameter = 7.0;

insert_diameter = 4.10;
insert_depth    = 5.00;

// Compartido entre openscad/parts/02_chassis/top.scad (taladros de
// paso) y walls.scad (insertos): deben coincidir en X/Y, por eso es
// un único parámetro y no un valor duplicado en cada archivo.
top_screw_y_inset = 15.0;

// Compartido entre walls.scad (topInsertPad) y top.scad (topInsertRelief).
top_insert_pad_depth = 8.0;  // grosor local en los insertos de la tapa (>= insert_diameter + margen)

//=============================================================================
// DERIVADOS
//=============================================================================

off_x = um790_mount_spacing_x/2;
off_y = um790_mount_spacing_y/2;

// PEDIDO POR EL USUARIO (2026-08-03): "desplazar los pilares que
// sujetan el UM790 para aproximar esta al panel posterior" — la
// placa quedaba 21,45mm corta respecto al panel trasero (confirmado
// por el usuario con la placa real montada, ~2cm de hueco). Se
// desplaza hacia atrás (+Y): los 4 postes (posts.scad), las islas de
// apoyo bajo ellos (base.scad) y la posición de referencia de la
// placa (um790_pos, assembly_positions.scad) — deja ~3,45mm de hueco
// restante hasta el panel, razonable para tolerancia y el grosor de
// los conectores. NO afecta a los nervios/marco exterior de la
// bandeja (siguen en su sitio, estructura distinta).
um790_post_y_offset = 18.0;

//=============================================================================
// NERVIOS
//=============================================================================

rib_width  = 3.0;
rib_height = 5.0;

//=============================================================================
// VENTILACIÓN
//=============================================================================

// PEDIDO POR EL USUARIO (2026-08-03): el suelo debe ser una rejilla
// en su práctica totalidad, para recoger más caudal de aire externo.
// Antes: 12 mm de margen por lado (dejaba 132x138,4 mm de rejilla
// sobre 156x162,4 mm de suelo). Ahora: 3 mm — el mínimo razonable
// para que el borde del suelo siga teniendo algo de material sólido
// donde apoyan las paredes, sin restar apenas superficie de rejilla.
bottom_grill_margin = 3.0;

// top_grill_margin — CORREGIDO (2026-08-03, aviso del usuario: "no
// se ve ningún agujero cuadrado, solo las tiras del ventilador"): con
// 16 mm, la zona de rejilla (124x130 mm) quedaba MÁS PEQUEÑA que la
// zona de exclusión del ventilador (136x136 mm, ver topVentCut() en
// top.scad) — la exclusión se comía la rejilla entera, no quedaba
// ningún hueco cuadrado real, solo se veían las tiras del protector
// de dedos del ventilador. Bajado a 6 mm (deja justo un anillo de
// huecos cuadrados alrededor del ventilador — el propio ventilador ya
// ocupa la mayor parte del área de ventilación disponible).
top_grill_margin = 6.0;

vent_slot_width  = 4.0;
vent_slot_length = 40.0;
vent_spacing     = 8.0;

//=============================================================================
// VENTILADOR SUPERIOR
//=============================================================================

fan_size       = 120.0;
fan_thickness  = 15.0;
fan_hole_pitch = 105.0;

//=============================================================================
// PANEL FRONTAL
//=============================================================================

front_panel_thickness = 3.0;
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

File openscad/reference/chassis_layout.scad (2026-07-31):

//
// ============================================================================
// SteamMachine UM790
// Project Phoenix
//
// Archivo : chassis_layout.scad
// Versión : 5.0
//
// ENSAMBLAJE VISUAL DEL PROYECTO
//
// ============================================================================

include <../../00_parametros.scad>;

use <../parts/01_bandeja/tray.scad>;

$fn = 64;


//=============================================================================
// CONFIGURACIÓN
//=============================================================================

bottom_air_gap = 12;

wall = wall_thickness;


//=============================================================================
// CHASIS TRANSPARENTE
//=============================================================================

module chassis_reference()
{

    color([0.75,0.75,0.75,0.12])

    difference()
    {

        translate([
            -case_width/2,
            -case_depth/2,
            0
        ])

        cube([
            case_width,
            case_depth,
            case_height
        ]);


        translate([
            -case_width/2+wall,
            -case_depth/2+wall,
            wall
        ])

        cube([
            case_width-2*wall,
            case_depth-2*wall,
            case_height
        ]);

    }

}


//=============================================================================
// BANDEJA
//=============================================================================

module tray_reference()
{

    translate([
        -tray_width/2,
        -tray_depth/2,
        bottom_air_gap
    ])

    color("LightGray")

    tray();

}


//=============================================================================
// UM790
//=============================================================================

module um790_reference()
{

    color([0.10,0.70,0.10,0.70])

    translate([
        -pcb_width/2,
        -pcb_depth/2,
        bottom_air_gap
        + tray_thickness
        + um790_post_height
    ])

    cube([
        pcb_width,
        pcb_depth,
        35
    ]);

}


//=============================================================================
// VENTILADOR
//=============================================================================

module fan_reference()
{

    color([0.10,0.10,0.10,0.70])

    translate([
        -60,
        -60,
        case_height-15
    ])

    cube([
        120,
        120,
        15
    ]);

}


//=============================================================================
// ESP32
//=============================================================================

module esp32_reference()
{

    color("RoyalBlue")

    translate([
        -27.5,
        -14,
        case_height-38
    ])

    cube([
        55,
        28,
        12
    ]);

}


//=============================================================================
// PLACA EXPANSIÓN
//=============================================================================

module shield_reference()
{

    color("FireBrick")

    translate([
        -38,
        -38,
        case_height-42
    ])

    cube([
        76,
        76,
        2
    ]);

}


//=============================================================================
// NFC
//=============================================================================

module nfc_reference()
{

    color("Gold")

    translate([
        -30,
        -case_depth/2+5,
        case_height-45
    ])

    cube([
        60,
        40,
        2
    ]);

}


//=============================================================================
// EJES
//=============================================================================

module axis()
{

    color("Red")
    cube([200,1,1]);

    color("Green")
    cube([1,200,1]);

    color("Blue")
    cube([1,1,200]);

}


//=============================================================================
// ENSAMBLAJE
//=============================================================================

axis();

chassis_reference();

tray_reference();

um790_reference();

fan_reference();

shield_reference();

esp32_reference();

nfc_reference();

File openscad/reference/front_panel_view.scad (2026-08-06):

//
// ============================================================================
// SteamMachine UM790
// Project Phoenix
//
// Archivo  : front_panel_view.scad
// Versión  : 1.0
// Fecha    : 2026-08-03
//
// Alzado frontal 2D del panel, generado por proyección plana de las
// posiciones ya validadas en virtual_assembly_v1.scad. Es una AYUDA
// VISUAL para revisar la disposición de agujeros/recortes, NO un
// plano acotado ni una pieza imprimible.
//
// Convención: se proyecta el ensamblaje 3D sobre el plano frontal
// (X = anchura, Z = altura), descartando la profundidad (Y).
//
// ============================================================================

include <../../00_parametros.scad>;
include <components/assembly_positions.scad>;

use <components/assembly_instances.scad>;

$fn = 48;


//=============================================================================
// SILUETA DEL PANEL (contorno exterior del frontal)
//=============================================================================

//=============================================================================
// ZONA DEL PANEL NFC (superior, intercambiable) — solo el contorno
//=============================================================================

module nfcZoneOutlineSolid(frame=2)
{
    translate([-nfc_panel_width/2, -1, nfc_panel_z_low])
    difference()
    {
        cube([nfc_panel_width,1,nfc_panel_height]);
        translate([frame,-1,frame])
            cube([nfc_panel_width-2*frame,3,nfc_panel_height-2*frame]);
    }
}


//=============================================================================
// SEPARACIÓN DE LOS TRES PANELES DEL FRONTAL
//
//   1. Panel inferior FIJO — aloja pulsador, OLED y USB doble. Tamaño
//      MÍNIMO imprescindible (petición del usuario).
//   2. Barra LED — se imprime EN LA MISMA PIEZA que el panel inferior,
//      con la Anycubic Kobra X en dos filamentos independientes (no es
//      una pieza separada, es una zona de color distinto en la misma
//      impresión). Altura real (led_bar_height).
//   3. Panel superior EXTRAÍBLE — aloja el tag NFC intercambiable.
//      Tamaño MÁXIMO posible (el resto del hueco disponible).
//
// Todas las cotas (front_panel_lower_top, front_panel_led_z_low/high)
// están ya calculadas en assembly_positions.scad — este archivo NO
// las recalcula, solo las dibuja, para no repetir la misma lógica en
// dos sitios (ver aviso de front_panel_zones_consistent más abajo).
//=============================================================================

module lowerPanelZoneSolid()
{
    translate([-case_width/2,-1,0])
        cube([case_width,1,front_panel_lower_top]);
}

module ledBarZoneSolid()
{
    translate([-case_width/2,-1,front_panel_led_z_low])
        cube([case_width,1,front_panel_led_z_high-front_panel_led_z_low]);
}

module nfcZoneFillSolid()
{
    translate([-case_width/2,-1,nfc_panel_z_low])
        cube([case_width,1,nfc_panel_z_high-nfc_panel_z_low]);
}

module upperMarginZoneSolid()
{
    translate([-case_width/2,-1,nfc_panel_z_high])
        cube([case_width,1,shell_height-nfc_panel_z_high]);
}


//=============================================================================
// ALZADO
//
// IMPORTANTE — orden de dibujado: las CUATRO zonas de color se pintan
// PRIMERO, opacas, cubriendo entre todas el panel completo (Z 0 a
// case_height). El contorno del panel, el marco NFC y los
// componentes se dibujan DESPUÉS, por encima. Si se invierte este
// orden, el contorno opaco tapa por completo las zonas de color
// (fallo del primer intento de esta vista).
//=============================================================================

module frontElevation()
{
    // Zona 1 — panel inferior fijo (pulsador, OLED, USB)
    color([0.60,0.78,0.90,1])
        projection(cut=false) rotate([-90,0,0]) lowerPanelZoneSolid();

    // Zona 2 — barra LED (MISMA pieza que la zona 1, 2º filamento)
    color([1.00,0.82,0.10,1])
        projection(cut=false) rotate([-90,0,0]) ledBarZoneSolid();

    // Zona 3 — panel NFC extraíble
    color([1.00,0.93,0.75,1])
        projection(cut=false) rotate([-90,0,0]) nfcZoneFillSolid();

    // Zona 4 — margen fijo del chasis (no es un panel)
    color([0.75,0.75,0.75,1])
        projection(cut=false) rotate([-90,0,0]) upperMarginZoneSolid();

    // Contorno exterior del panel, por encima de las zonas (solo el borde)
    color([0.3,0.3,0.3,1])
    {
        translate([-case_width/2,-2,0])           cube([case_width,0.1,0.6]);
        translate([-case_width/2,-2,shell_height-0.6]) cube([case_width,0.1,0.6]);
        translate([-case_width/2,-2,0])           cube([0.6,0.1,shell_height]);
        translate([case_width/2-0.6,-2,0])        cube([0.6,0.1,shell_height]);
    }

    // Marco del panel NFC (borde de la pieza extraíble)
    color([0.9,0.4,0.05,1])
        projection(cut=false) rotate([-90,0,0]) nfcZoneOutlineSolid();

    color([0.15,0.35,0.15,1])
        projection(cut=false) rotate([-90,0,0]) rc522InstanceBody();

    color([0.85,0.05,0.05,1])
        projection(cut=false) rotate([-90,0,0]) pushbuttonInstanceBody();

    color([0.05,0.05,0.4,1])
        projection(cut=false) rotate([-90,0,0]) oledInstanceBody();

    color([0.1,0.1,0.1,1])
        projection(cut=false) rotate([-90,0,0]) usbFrontInstanceBody();

    // Líneas divisorias entre las tres zonas
    color([0.1,0.1,0.1,1])
    {
        translate([-case_width/2,-2,front_panel_lower_top-0.3])
            cube([case_width,0.1,0.6]);
        translate([-case_width/2,-2,front_panel_led_z_high-0.3])
            cube([case_width,0.1,0.6]);
        translate([-case_width/2,-2,nfc_panel_z_high-0.3])
            cube([case_width,0.1,0.6]);
    }
}

frontElevation();

echo(str("Panel inferior fijo (MÍNIMO): Z 0 - ", front_panel_lower_top, " (", front_panel_lower_top, " mm alto)"));
echo(str("Barra LED (misma pieza, 2º filamento): Z ", front_panel_led_z_low, " - ", front_panel_led_z_high, " (", front_panel_led_z_high-front_panel_led_z_low, " mm alto)"));
echo(str("Panel NFC extraíble (MÁXIMO): Z ", nfc_panel_z_low, " - ", nfc_panel_z_high, " (", nfc_panel_height, " mm alto)"));
echo(str("Margen fijo superior del chasis: Z ", nfc_panel_z_high, " - ", shell_height, " (", shell_height-nfc_panel_z_high, " mm alto)"));
echo(front_panel_zones_consistent
    ? "OK: nfc_panel_height (00_parametros.scad) coincide con el cálculo de abajo hacia arriba."
    : "AVISO: nfc_panel_height (00_parametros.scad) NO coincide con el cálculo de abajo hacia arriba — revisar.");

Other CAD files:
STL/leftwall_flat2.stl
openscad/parts/03_panels/nfc_panel_blank.stl
openscad/parts/03_panels/nfc_panel_retrobat.stl
STL/Anagramas/Gung.stl
openscad/reference/um790_reference.scad
STL/Anagramas/Retrobat.stl
STL/Anagramas/nfc_panel_blank.stl
STL/caja_nfc_panel_caja_y_tapa.stl
STL/chassis.stl
STL/floor.stl
STL/floor_flat (1).stl
STL/floor_flat.stl
STL/foot.stl
STL/leftwall_flat.stl
STL/lower_panel.stl
STL/rc522_bracket.stl
STL/rc522_bracket2.stl
STL/rear_panel.stl
STL/rear_panel_horizontal.stl
STL/rightwall_flat.stl
STL/top.stl
STL/tray.stl
obsoletos/front_layout.scad
obsoletos/front_panel.scad
obsoletos/parts_03_panels/oled_bracket.scad
obsoletos/rc522_bracket_v1.scad
obsoletos/um790_reference.scad
obsoletos/virtual_assembly_v1.scad
openscad/parts/01_bandeja/base.scad
openscad/parts/01_bandeja/posts.scad
openscad/parts/01_bandeja/rear_panel.scad
openscad/parts/01_bandeja/ribs.scad
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

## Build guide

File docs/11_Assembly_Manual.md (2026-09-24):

\# SteamMachine UM790

\# 11 - Assembly Manual

Version: 1.1

Status: Draft

\---

\# Objetivo

Este documento describe el procedimiento completo de montaje de SteamMachine UM790.

Debe permitir ensamblar el equipo desde cero siguiendo una secuencia lógica, minimizando errores y evitando desmontajes innecesarios.

\---

\# Herramientas necesarias

\## Herramientas

\- Destornillador Phillips PH0

\- Destornillador Phillips PH1

\- Llaves Allen (si procede)

\- Alicates de punta fina

\- Pinzas de electrónica

\- Cúter

\- Regla metálica

\- Calibre digital

\- Multímetro

\---

\## Herramientas para impresión

\- Espátula

\- Lima fina

\- Lija P400

\- Lija P800

\---

\## Herramientas para insertos

\- Soldador regulable

Temperatura recomendada

220 °C

Punta cilíndrica

\---

\# Materiales

\## Tornillería

M2

M3

M4 (si procede)

\---

\## Insertos térmicos

M2

M2.5

M3

M4

\---

\## Imanes

3 × 2 mm

6 × 2 mm

\---

\# Componentes

\- Minisforum UM790 Pro

\- ESP32 Terminal Adapter

\- RC522

\- Noctua NF-A12x15 PWM

\- HUB USB

\- OLED

\- Pulsador metálico

\- Prolongadores USB empotrables

\- Tira LED direccionable WS2812B, 5 V (aprox. 15 cm / 9 LED)

\---

\# Comprobación previa

Antes de comenzar:

□ Todas las piezas impresas sin deformaciones, y todas en PETG (el PLA se
deforma con el calor del equipo; solo vale para pruebas de encaje).

□ Todos los insertos disponibles.

□ Tornillería completa.

□ Componentes probados individualmente.

\---

\# Orden de montaje

La secuencia debe respetarse.

\---

\# Paso 1

\## Preparación del chasis inferior

Instalar:

\- insertos térmicos M3 (postes de la bandeja, patas del pie desmontable, injerto suelo-pared)

\- pie desmontable (openscad/parts/02_chassis/foot.scad — atornillado desde fuera, por debajo, a los insertos del suelo; ya NO son patas integradas de una pieza — ver CHANGELOG [1.5.2]/[1.5.3])

\- soportes

Antes de montar las paredes (paso siguiente): atornillar el suelo a cada pared por el injerto M3 suelo-pared (2 tornillos por lado, desde fuera y por debajo del suelo, roscando en el inserto ciego de la base de cada pared — CHANGELOG [1.5.2]).

Verificar:

□ Todos los insertos completamente asentados.

\---

\# Paso 2

\## Montaje del UM790

Instalar:

\- separadores

\- UM790

No apretar completamente hasta verificar la alineación.

Comprobaciones

□ Conectores traseros alineados.

□ Separación respecto a la base.

\---

\# Paso 3

\## Instalación del HUB USB

Fijar soporte.

Conectar:

UM790

↓

HUB

Todavía no conectar los prolongadores.

\---

\# Paso 4

\## Instalación del ESP32

Montar:

\- separadores M3

Conectar:

alimentación

USB

No conectar todavía RC522.

El ESP32 se alimentará mediante USB-C durante las pruebas. La línea de 5 V disponible en la placa se reservará para la pequeña sección de tira WS2812B.

\---

\# Paso 5

\## Instalación del RC522

Fijar al soporte estructural.

Conexiones al ESP32:

| RC522 | ESP32 |
|---|---|
| 3.3V | 3V3 |
| GND | GND |
| SDA / SS | GPIO5 |
| SCK | GPIO18 |
| MISO | GPIO19 |
| MOSI | GPIO23 |
| RST | GPIO27 |
| IRQ | NC |

El RC522 trabaja a 3,3 V. No alimentar el módulo a 5 V.

Verificar:

La antena queda centrada respecto al panel frontal.

No respecto a la PCB.

\---

\# Paso 6

\## Instalación del ventilador

Fijar Noctua.

Orientación

Entrada:

base

Salida:

tapa

Comprobar:

\- sentido del flujo

\- cable accesible

\---

\# Paso 7

\## Panel trasero

Montar

Panel

↓

Tornillos

↓

Insertos

No forzar.

**Pulsador de encendido del UM790** (añadido 2026-08-22, ver
CHANGELOG — independiente del ESP32):

↓

Insertar el pulsador en el hueco redondo del panel trasero (a ~2,5cm
del lateral derecho, altura media entre el disipador del UM790 y el
ventilador)

↓

Cablear sus dos contactos directamente al header de encendido de la
placa del UM790 — NO al ESP32, es un circuito totalmente aparte

\---

\# Paso 8

\## Panel frontal

Instalar:

OLED

↓

OLED (4 tornillos directos a través de lower_panel.scad — oledMountHoles();
sustituye al pegamento. La brida separada que se estudió en su momento
[oled_bracket.scad] quedó descartada — ver CHANGELOG [1.5.5])

↓

Pulsador

↓

USB

↓

Barra LED (canal rediseñado 2026-08-22: costillas repartidas en vez
de repisa — ver CHANGELOG)

↓

Cableado

No colocar todavía el panel intercambiable.

\---

\# Paso 9

\## Cableado

Orden recomendado

1

Ventilador

2

ESP32

3

OLED

4

RC522

5

LED

6

USB

Agrupar mediante bridas.

Nunca cruzar el ventilador.

### Pinout definitivo del ESP32

#### RC522 — SPI

| Señal | GPIO ESP32 | Alimentación |
|---|---:|---|
| SDA / SS | GPIO5 | — |
| SCK | GPIO18 | — |
| MISO | GPIO19 | — |
| MOSI | GPIO23 | — |
| RST | GPIO27 | — |
| IRQ | NC | — |
| VCC | — | 3V3 |
| GND | — | GND |

#### OLED — I²C

| Señal | GPIO ESP32 | Alimentación |
|---|---:|---|
| SDA | GPIO21 | — |
| SCL | GPIO22 | — |
| VCC | — | 3V3 |
| GND | — | GND |

La dirección I²C del módulo OLED debe comprobarse durante la puesta en marcha. El módulo instalado dispone de selección de dirección indicada en la propia PCB.

#### Tira LED — WS2812B

Se instalarán **8 LED** (dato real confirmado, 2026-08-25).

| Señal | Conexión |
|---|---|
| DIN | GPIO25 |
| +5V | 5V / VIN del ESP32 |
| GND | GND común |
| DOUT | NC |

La tira se alimenta desde la línea de 5 V disponible cuando el ESP32 está alimentado por USB-C. **GPIO25 se utiliza exclusivamente como señal de datos y nunca como alimentación.**

Para la entrada DIN se recomienda una resistencia serie de **330–470 Ω**. Se recomienda además un condensador de **470–1000 µF**, tensión nominal mínima 10 V, entre +5 V y GND cerca de la entrada de la tira.

El firmware deberá limitar el brillo máximo para mantener bajo el consumo. Con 8 LED, el consumo teórico máximo a blanco y brillo total es aproximadamente 480 mA, por lo que el brillo limitado será la configuración normal de funcionamiento.

**Todas las masas (GND) del ESP32, RC522, OLED y WS2812B deben estar eléctricamente comunes.**

No alimentar la tira WS2812B desde un GPIO.

### Resumen de conexiones

```text
ESP32
├── RC522 (SPI)
│   ├── SDA/SS → GPIO5
│   ├── SCK    → GPIO18
│   ├── MISO   → GPIO19
│   ├── MOSI   → GPIO23
│   ├── RST    → GPIO27
│   ├── VCC    → 3V3
│   └── GND    → GND
│
├── OLED (I²C)
│   ├── SDA    → GPIO21
│   ├── SCL    → GPIO22
│   ├── VCC    → 3V3
│   └── GND    → GND
│
└── WS2812B (8 LED)
    ├── DIN    → GPIO25
    ├── +5V    → 5V/VIN
    └── GND    → GND
```

\---

\# Paso 10

\## Panel superior

Montar.

Verificar:

No presiona ningún cable.

\---

\# Paso 11

\## Panel NFC (impresión en dos piezas + pegado)

Desde este ciclo, el panel NFC con anagrama se imprime en dos piezas
separadas en vez de como bloque único con el emblema en relieve:

Base del panel (STL/Anagramas/nfc\_panel\_blank.stl)

↓

Anagrama suelto (STL/Anagramas/Steam.stl, Retrobat.stl, Parrot.stl,
engranaje.stl, Gung.stl para el panel Zombies, Apagar.stl para el panel
Apagar — según el panel)

↓

Pegar el anagrama sobre la base con Loctite (cianoacrilato tipo
401/454). En PETG agarra peor que en PLA: lijar ligeramente las dos
caras y desengrasar con alcohol isopropílico antes de pegar; si se
despega, usar epoxi de 5 minutos

Ventaja frente a la pieza única: el tiempo de impresión baja de ~6h a
~1h, al no necesitar imprimir el relieve del emblema integrado en el
mismo trabajo que la base.

Instalar:

Imanes

↓

Tag NFC

↓

Panel

Comprobar:

Inserción

Extracción

Lectura

\---

\# Primera puesta en marcha

Conectar

Fuente

↓

USB ESP32

↓

Pantalla

Debe aparecer:

SteamMachine

↓

Ready

\---

\# Pruebas iniciales

\## OLED

□ Texto correcto.

\---

\## LED

□ Color correcto.

□ Brillo limitado según configuración de firmware.

□ Los 8 LED encienden correctamente sin reiniciar el ESP32.

\---

\## RC522

□ Detecta panel.

\---

\## Pulsador

□ Envía evento.

\---

\## USB

□ Reconocido por el sistema (`lsusb`).

\---

\## Ventilador

□ Gira correctamente.

\---

\# Checklist

\## Mecánica

□ Todos los tornillos instalados.

□ Sin piezas sueltas.

□ Sin rozamientos.

\---

\## Cableado

□ Ordenado.

□ Sin cables en el ventilador.

\---

\## Firmware

□ Arranca.

□ Detecta panel.

\---

\## Software

□ Reconoce panel.

□ Cambia OLED.

□ Cambia LEDs.

□ Lanza plataforma.

\---

\# Mantenimiento

Cada seis meses

\- limpiar ventilador

\- revisar tornillos

\- limpiar rejillas

Cada doce meses

\- revisar pasta térmica (si procede)

\- comprobar ventilador

\---

\# Sustitución de paneles

1

Retirar panel.

2

Insertar nuevo panel.

3

Esperar actualización OLED.

4

Pulsar botón.

\---

\# Resolución de problemas

\## No detecta panel

\- comprobar RC522

\- comprobar UID

\- comprobar distancia

\---

\## OLED apagada

\- comprobar I²C

\- comprobar alimentación

\---

\## LED apagados

\- comprobar ESP32

\- comprobar GPIO25 / señal DIN

\- comprobar 5 V / VIN

\- comprobar GND común

\- comprobar resistencia serie de 330–470 Ω

\- comprobar alimentación

\---

\## USB no funciona

\- comprobar HUB

\- comprobar cable interno

\---

\# Fin del montaje

El equipo queda listo para comenzar las pruebas descritas en

10\_Test\_Plan.md

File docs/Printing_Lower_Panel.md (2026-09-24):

# SteamMachine UM790
## Guía de impresión — Panel inferior (lower_panel.stl)
Version: 1.0
Status: Aprobado, verificado con impresión real
Date: 2026-08-17

Pieza: `openscad/parts/03_panels/lower_panel.scad` → `lower_panel.stl`

---

## 1. Resumen

El panel inferior se imprime en **dos filamentos**: el cuerpo
completo en el color base, y una franja estrecha (el difusor de la
tira LED) en un segundo filamento translúcido. El cambio de
filamento se hace por **rango de altura** (Z), no pintando a mano —
es una franja recta de lado a lado del panel, ideal para ese
método.

Laminador de referencia: Anycubic Slicer Next (basado en
OrcaSlicer). Los nombres de herramienta deberían ser equivalentes en
cualquier laminador con soporte de modificadores por rango de altura
y multi-material/AMS.

---

## 2. Filamentos

| Filamento | Uso | Notas |
|---|---|---|
| Filamento 1 | Cuerpo completo del panel | Color base a elección |
| Filamento 2 | Franja del difusor LED | Translúcido, para dejar pasar la luz de la tira LED |

---

> ⚠️ **Material: PETG (2026-09-21).** El PLA se deforma con la
> temperatura del equipo, así que esta pieza se imprime en PETG. **Los
> dos filamentos deben ser PETG** (también el translúcido del difusor):
> mezclar PLA y PETG en una pieza da mala unión entre capas. El PETG
> hace puentes algo peor que el PLA: comprueba las costillas del canal
> LED (sección 5). Los consumos de la sección 6.1 son de una laminación
> con PLA/PLA+; hay que volver a laminar con los perfiles PETG.

## 3. Orientación de la pieza

Orientar la pieza **de pie**, con su eje Z hacia arriba, apoyada
sobre su borde más largo (el mismo criterio que el resto de paneles
frontales del proyecto). No imprimir plana.

---

## 4. Rango de altura del difusor

**Z: 40,5 mm a 46,5 mm**

Este rango está verificado por cálculo directo sobre los parámetros
actuales del proyecto (`front_panel_led_z_low`,
`front_panel_led_z_high`, `front_bezel_border`, `led_diffuser_width`
— ver `lower_panel.scad`, módulo `ledDiffuserZone()`). No ha
cambiado a pesar de varios ajustes de ancho y tornillería del panel
en rondas anteriores — el ancho del panel (149 mm) y el grosor
(3 mm) no afectan a la posición Z de esta franja.

Pasos en Anycubic Slicer Next:

1. Cargar `lower_panel.stl` y orientarlo como se indica en la
   sección 3.
2. Confirmar que ambos filamentos están cargados (ver sección 2).
3. En la **lista de objetos** (panel lateral, no la barra de
   iconos de arriba), hacer **clic derecho** sobre el nombre
   `lower_panel.stl`.
4. En el menú contextual, elegir **"Modificador de rango de
   altura"**.
   > ⚠️ El icono de la barra de herramientas superior con forma de
   > cubo y línea de puntos **no es esto** — es una herramienta de
   > pintado de superficie distinta (pincel, sin modo de rango de
   > altura). El modificador de rango de altura solo se añade desde
   > el menú contextual de la pieza.
5. Se crea un sub-elemento "Capas" bajo la pieza, con un rango por
   defecto. Introducir el rango **40,5 a 46,5 mm** en los campos
   "Rango de altura".
6. Con ese rango seleccionado en la lista, asignarle el
   **filamento 2** (aparece como una casilla de color junto al
   rango) — no al objeto completo. El resto de la pieza
   (`lower_panel.stl` en sí) debe quedar en filamento 1.

---

## 5. Soportes

**Rediseño 2026-08-22**: la pared del canal ya no tiene una repisa en
voladizo (se eliminó por completo — chocaba con los conectores USB-C
internos, ver CHANGELOG). Ahora son 6 costillas cortas (10mm de vano,
8mm de ancho cada una — ver `led_channel_rib_count`/`led_channel_rib_width`
en `lower_panel.scad`) que conectan la pared directamente con el
panel. Un vano de 10mm en una pieza tan estrecha normalmente NO
necesita soporte (la mayoría de impresoras hacen bridging limpio hasta
15-20mm), pero compruébalo en la vista de previsualización de tu
laminador antes de asumirlo — si ves puentes largos sin apoyo o
cuelgan mal en la previsualización, activa soportes solo en esa franja
concreta.

---

## 6. Verificación antes de imprimir

En la vista de **Previsualización**, con el esquema de color puesto
en **Filamento**, comprobar que:

- La franja del difusor (40,5–46,5 mm) se distingue claramente del
  resto del cuerpo del panel.
- Las costillas del canal LED (6, repartidas a lo largo) imprimen
  limpias, sin necesidad de soporte — si alguna sale mal, activar
  soporte solo ahí.
- El resto de la pieza queda enteramente en el filamento 1.

> ⚠️ **El modelo 3D en gris no significa que falte configuración.**
> Tanto la vista "Preparar" como la vista "Previsualización" (antes
> de mover el deslizador de capas) pueden mostrar la pieza en un
> solo color aunque el rango de altura esté correctamente
> configurado — el color por filamento solo se ve capa a capa,
> moviendo el **deslizador vertical de capas/altura** (a la derecha
> de la vista 3D, tras laminar) hasta una capa dentro del rango
> 40,5–46,5 mm (con altura de capa 0,2 mm, aproximadamente las
> capas 202 a 232).

**Confirmación más fiable** — el panel **Esquema de colores**
(columna izquierda tras laminar) desglosa el consumo por filamento;
si el filamento 2 aparece con longitud/peso distinto de cero y hay
al menos 2 "Tiempos de cambio de filamento", el rango está aplicado
correctamente, con independencia de lo que se vea en la vista 3D.

---

## 6.1. Verificación real (2026-08-17)

Confirmado con una laminación real en Anycubic Slicer Next:

| Filamento | Longitud | Peso |
|---|---|---|
| 1 (Anycubic PLA) | 6,81 m | 20,32 g |
| 2 (Anycubic PLA+) | 1,96 m | 5,83 g |

- Tiempos de cambio de filamento: **2** (uno al entrar en la franja
  del difusor, otro al salir — coincide con lo esperado para un
  único rango de altura).
- Tiempo de impresión del modelo: 1h 8m. Tiempo total (incluyendo
  purgas): 1h 9m.
- Coste estimado: 0,53 (moneda del laminador).

Esquema de colores tras laminar, confirmando el consumo del filamento 2

---

## 7. Historial

- **2026-08-22**: rediseño del canal LED (repisa en voladizo
  eliminada, sustituida por 6 costillas cortas) y nuevos bosses para
  la brida de sujeción de la OLED — cambia la geometría del canal y
  puede que ya no necesite soporte (ver sección 5). **Los tiempos,
  pesos y coste de la sección 6 son de la versión anterior del
  modelo — hay que volver a laminar y actualizar estos números antes
  de confiar en ellos.**
- **2026-08-06**: primera versión de este flujo de trabajo,
  confirmada con una impresión real (franja de 6 mm, dentro del
  hueco libre de marco).
- **2026-08-17**: parámetros reverificados tras varias rondas de
  ajuste del panel (ancho a 149 mm, tornillería M3, pared del canal
  LED a 10 mm) — el rango Z del difusor no se ha visto afectado por
  ninguno de esos cambios. Documento creado a partir de esta
  verificación, a petición del usuario.
- **2026-08-17 (más tarde)**: guía corregida tras confusión real del
  usuario siguiendo estos mismos pasos — el paso 3-4 original
  (icono de la barra de herramientas) señalaba una herramienta
  equivocada (pintado de superficie, sin modo de rango de altura).
  Corregido al método real: clic derecho sobre la pieza → menú
  contextual. Añadido el aviso sobre el modelo en gris (normal, no
  es un fallo) y la verificación real de consumo de filamento tras
  laminar (sección 6.1), que confirma que el rango se aplica
  correctamente.

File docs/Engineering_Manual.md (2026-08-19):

# SteamMachine UM790 – Engineering Manual

Este documento consolida la documentación del proyecto.

## Capítulos
1. Visión general
2. Arquitectura del sistema
3. Especificaciones mecánicas
4. Diseño electrónico
5. Firmware
6. Software
7. Protocolo
8. API
9. Normas de desarrollo
10. Plan de pruebas
11. Manual de montaje
12. Mantenimiento
13. BOM
14. Historial

### Resumen
- Carcasa: 156×162.4×148 mm (152 mm con patas).
- UM790 Pro + ESP32 + RC522 + OLED + HUB USB + Noctua NF-A12x15.
- Paneles NFC intercambiables con fijación magnética.
- Comunicación JSON por USB Serie.
- Software modular en Python y firmware ESP32.

> Este es el documento maestro inicial; se ampliará con diagramas, planos y anexos durante el desarrollo.

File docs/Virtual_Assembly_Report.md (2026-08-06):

# SteamMachine UM790
## Virtual Assembly Report — v1
Version: 2.0
Status: Definitivo (confirmado por el usuario)
Date: 2026-08-03

Informe de resultados de `openscad/reference/virtual_assembly_v1.scad`,
el ensamblaje virtual completo construido **antes** de diseñar el
bastidor definitivo. Verifica que ningún componente colisiona, que el
cableado tiene espacio, que el ventilador no interfiere con nada, que
los conectores traseros son accesibles y que el HUB USB puede llegar a
los USB frontales con cables cortos.

Complementa (no sustituye) `docs/02_Mechanical_Layout.md` (DIM v1.0,
Approved), que sigue siendo la referencia de criterios de diseño.

**Todas las decisiones de este documento han sido confirmadas por el
usuario el 2026-08-03** y se dan por definitivas para el ensamblaje
virtual v1. El diseño del bastidor (`openscad/parts/02_chassis`) puede
comenzar a partir de aquí.

---

## 1. Resultado final de la comprobación de colisiones

```
Pares sin colisión : 28 / 28
Pares en colisión  : 0
Errores de render  : 0

AVISOS (volúmenes de seguridad de cableado, no bloqueantes):
  - rc522InstanceKeepout <-> esp32InstanceBody (12 triángulos)
  - esp32InstanceKeepout <-> rc522InstanceBody (24 triángulos)
```

Reproducible con:
```bash
cd openscad/reference/checks
python3 run_collision_checks.py
```

Los dos avisos son solo una indicación de que el cableado entre el
RC522 y el ESP32 pasa cerca uno del otro (ambos en el lateral
izquierdo, por diseño) — no es una colisión mecánica dura, solo un
punto a cuidar al enrutar los cables en el montaje real.

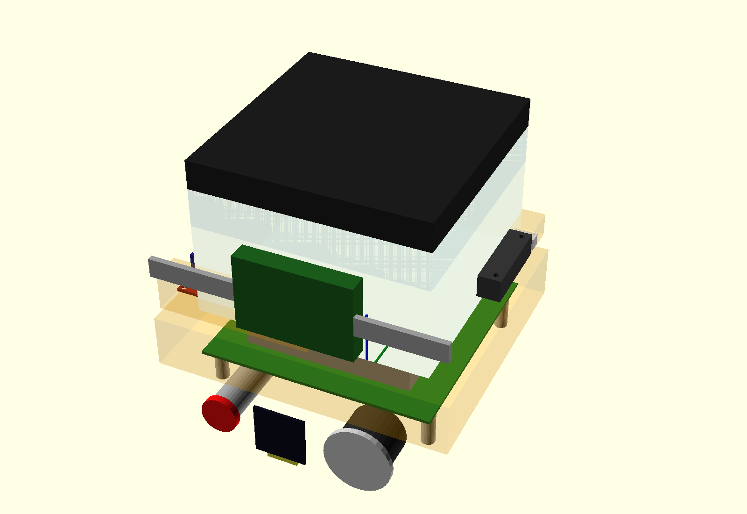
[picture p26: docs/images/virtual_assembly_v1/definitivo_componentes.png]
Componentes del ensamblaje

*Ensamblaje virtual sin la carcasa, estado definitivo.*

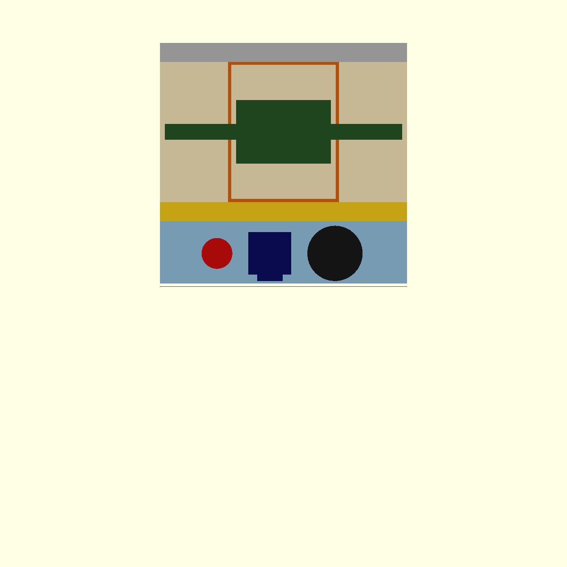
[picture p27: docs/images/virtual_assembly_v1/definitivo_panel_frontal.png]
Panel frontal — las tres zonas

*Alzado frontal: panel inferior fijo (azul), barra LED (amarillo), panel NFC (beige/naranja), margen fijo (gris).*

---

## 2. Decisiones confirmadas por el usuario (2026-08-03)

| Decisión | Valor | Nota |
| --- | --- | --- |
| Altura de separadores del UM790 | **20 mm** | `um790_standoff_height` en `00_parametros.scad` |
| Posición X del pulsador | **-42 mm** | esquiva el poste de anclaje izquierdo de la PCB |
| Posición X del USB empotrable | **+32,5 mm** | esquiva el poste de anclaje derecho de la PCB |
| USB frontal | **1 unidad de doble puerto** (no 2 independientes) | componente real localizado por el usuario; cables flexibles al HUB |
| Ancho real de la tira LED | **10 mm** | + 1 mm de margen de canal a cada lado = 12 mm total |
| Tamaño del panel inferior fijo | **mínimo imprescindible: 39,5 mm** | envolvente del clúster + 3 mm de margen |
| Tamaño del panel NFC extraíble | **máximo posible: 88,5 mm** | todo el hueco restante hasta el margen superior fijo |

Estas decisiones son la razón por la que el resultado final es 28/28
sin colisión — se llegó a este estado a través de varias iteraciones
(ver sección 4, historial).

---

## 3. Las tres zonas del panel frontal (definitivo)

| Zona | Z (mm) | Alto | Contenido |
| --- | --- | --- | --- |
| 1 — Panel inferior fijo | 0 – 39,5 | 39,5 mm | Pulsador (X=-42), OLED (X=-8,6), USB doble (X=32,5) — fila única, misma altura Z=19 |
| 2 — Barra LED | 39,5 – 51,5 | 12 mm | Impresa en la MISMA pieza que el panel inferior, 2º filamento (Anycubic Kobra X) |
| 3 — Panel NFC extraíble | 51,5 – 140 | 88,5 mm | RC522 centrado a media altura (Z=95,75), separado 3 mm del panel |
| — Margen fijo del chasis | 140 – 152 | 12 mm | No es un panel; parte del chasis principal fijo |

Comprobación de consistencia incorporada: `assembly_positions.scad`
calcula estas cuatro zonas de abajo hacia arriba (a partir del
clúster) de forma independiente al valor de `nfc_panel_height` fijado
en `00_parametros.scad`, y avisa (`front_panel_zones_consistent`) si
alguna vez dejan de coincidir — por ejemplo, si se cambia el tamaño de
algún componente del clúster inferior sin actualizar
`nfc_panel_height`.

Vista de alzado reproducible con:
```bash
cd openscad/reference
openscad front_panel_view.scad
```
(`front_panel_view.scad` es una ayuda visual de proyección plana, NO
una pieza imprimible ni un plano acotado.)

---

## 4. Historial de esta verificación (resumen)

1. **Primera pasada** (12 mm de separadores, posiciones de
   `front_layout.scad` sin verificar): 26/28 — colisión real entre el
   pulsador/USB y la PCB del UM790, por falta de profundidad libre
   tras el panel frontal (~18,45 mm disponibles frente a 55 mm/28 mm
   necesarios).
2. **Elevar el UM790 a 20 mm sin más**: seguía en 26/28 — el problema
   se trasladaba de la PCB a los postes de anclaje de la propia PCB
   (no modelados en la primera versión de `um790.scad`).
3. **Postes de anclaje añadidos + pulsador/USB reposicionados en X**
   para esquivarlos: 28/28.
4. **USB real localizado por el usuario** (unidad doble, cables
   flexibles): permitió intentar una fila única con el OLED, que en
   el primer intento con 2 USB independientes no cabía (solapes de
   5,88 mm). Con la unidad doble sí cupo: 28/28, panel más compacto.
5. **Corrección de un fallo de visualización**: la primera vista de
   alzado frontal tapaba las zonas de color con un contorno opaco
   dibujado encima; corregido invirtiendo el orden de dibujado.
6. **Tira LED con dato real (10 mm)**: sustituyó el hueco de
   conveniencia (25 mm) inventado en el primer intento. De paso se
   detectó y corrigió una colisión de nombres con un parámetro
   `led_bar_height` ya existente en el proyecto (usado por
   `front_panel.scad` y `front_layout.scad`, valor antiguo 8 mm).
7. **Panel inferior mínimo / NFC máximo**: cálculo de abajo hacia
   arriba a partir de la envolvente real del clúster; `nfc_panel_height`
   pasa de 70 mm a 88,5 mm.
8. **Confirmación del usuario** (este documento): separadores a
   20 mm y posiciones X del pulsador/USB, definitivas.

---

## 5. Parámetros añadidos o modificados en `00_parametros.scad`

Solo se han modificado tres valores YA EXISTENTES en el archivo (el
resto de cambios son parámetros nuevos, añadidos sin tocar nada
más):

| Parámetro | Antes | Ahora | Motivo |
| --- | --- | --- | --- |
| `led_bar_height` | 8.0 (estimado) | `led_bar_strip_width + 2*led_bar_margin` = 12.0 (dato real) | Dato real proporcionado por el usuario |
| `nfc_panel_height` | 70.0 | 88.5 | Maximizado tras minimizar el panel inferior (petición del usuario) |
| `um790_standoff_height` | 12.0 (dato inicial de esta tarea) | 20.0 | Confirmado por el usuario para resolver la colisión con la PCB/postes |

**Importante**: `led_bar_height` y `nfc_panel_height` los usan
también `openscad/parts/03_panels/front_panel.scad` y
`front_layout.scad` (piezas ya construidas, aunque no impresas ni
finalizadas). Este cambio afecta a esos dos ficheros la próxima vez
que se rendericen.

---

## 6. Discrepancia pendiente (fuera del alcance de esta tarea)

Sigue habiendo dos valores de altura de separadores del UM790 sin
reconciliar con el confirmado aquí (20 mm):

| Fuente | Valor |
| --- | --- |
| `openscad/parts/01_bandeja/posts.scad` (bandeja física ya construida) | 6 mm |
| `docs/02_Mechanical_Layout.md` (DIM v1.0, Approved) | 8 mm |
| **Este ensamblaje virtual v1 (confirmado)** | **20 mm** |

Antes de imprimir la bandeja física o dar el DIM por definitivo en
este punto, hay que decidir cuál de los tres prevalece — lo más
probable, dado todo lo verificado aquí, es actualizar `posts.scad` y
el DIM a 20 mm, pero esa decisión no se ha tomado todavía y queda
fuera del alcance de este ensamblaje virtual (que solo verifica,
no modifica piezas ya construidas).

---

## 8. Patas externas (confirmado 2026-08-03)

El usuario confirmó que las patas son **externas y miden 4 mm**,
añadidas por debajo del cascarón — no incluidas en la altura de
trabajo interna. Esto obligó a un recálculo:

| Parámetro | Antes | Ahora |
| --- | --- | --- |
| `shell_height` (nuevo, altura real del cascarón) | — (se usaba `case_height`=152 directamente) | **148,0** |
| `leg_height` (nuevo) | — | **4,0** |
| `nfc_panel_height` | 88,5 | **84,5** |
| `z_fan_bottom` | 134 | 130 |
| `rc522_pos[2]` | 95,75 | 93,75 |
| `esp32_pos[2]` / `hub_pos[2]` | 99,8 | 97,8 |

`case_height` (152, con patas) NO se ha modificado — sigue siendo el
dato exterior original de la Steam Machine. Se ha añadido
`shell_height = case_height - leg_height` como la altura real que usa
todo el ensamblaje y el chasis a partir de ahora.

La comprobación de consistencia incorporada en `assembly_positions.scad`
(`front_panel_zones_consistent`) detectó automáticamente que
`nfc_panel_height` había quedado desactualizado tras el primer intento
de este recálculo (dejaba 4 mm de solape con la barra LED) — quedó
corregido y revalidado.

**Resultado tras el recálculo**: 28/28 pares del ensamblaje sin
colisión (sin cambios), 30/32 en la comprobación estructural del
chasis (sin cambios; los 2 "colisiona" siguen siendo los mismos
contactos de superficie intencionados: RC522 y ESP32 tocando su punto
de anclaje en la pared).

Patas añadidas como geometría real (no solo de referencia) en
`openscad/parts/02_chassis/floor.scad` (`floorLegs()`): 4 patas
cuadradas de 10×10×4 mm (estimado) en las esquinas.

---

## 10. Colisiones estructura-contra-estructura (2026-08-03)

Hasta este punto, la verificación solo comparaba cada pieza del
chasis contra los 8 componentes electrónicos — nunca las piezas del
chasis **entre sí**. Un aviso del usuario sobre los pilares de la
bandeja llevó a añadir esta comprobación
(`openscad/parts/02_chassis/checks/run_structure_checks.py`, sección
"ESTRUCTURA vs ESTRUCTURA"), que encontró varias colisiones de
volumen real:

- Pilares de apoyo de la bandeja macizos, y mal ubicados (zona hueca
  de la bandeja, y luego dentro del relleno de la pared).
- Panel trasero: Z de arranque y anchura solapando el suelo y las
  paredes.
- Lengüeta bandeja↔panel trasero a la altura equivocada.
- Panel inferior: misma anchura errónea que el panel trasero.
- Tornillos M2 (panel inferior) e imanes (panel NFC) invadiendo el
  relleno local de la pared.

Todo corregido — ver `CHANGELOG.md`, entrada [0.3.6], para el
detalle completo de cada fallo y su corrección.

**Pendiente, retirado por no resolverse a tiempo**: la fijación
adicional pared↔panel trasero (más allá de la unión con la bandeja,
que sí funciona) — colisionaba con el relleno de la pared de forma
que no se resolvió limpiamente en esta sesión.

---

## 11. Siguientes pasos (histórico — ver sección 12 para el estado final)

1. ~~Resolver la fijación pared↔panel trasero retirada~~ — resuelta
   en una sesión posterior (`wallPadRelief()` aplicado también ahí).
2. Reconciliar la altura de separadores en `posts.scad` y
   `docs/02_Mechanical_Layout.md` con el valor confirmado (20 mm) —
   sigue pendiente, no bloqueante (solo afecta a un comentario del
   DIM, no a ninguna pieza).
3. Guías de inserción de la bandeja y rejilla de protección de dedos
   del ventilador: hechas.

---

## 12. CIERRE — Chasis validado como definitivo (2026-08-03)

El usuario ha dado por bueno el chasis en su estado actual; no se
prevén más cambios de diseño salvo que surja algún problema al
imprimir/montar. Resumen de lo verificado antes de este cierre:

### Correcciones de esta sesión (ver `CHANGELOG.md` para el detalle
completo, entradas 0.3.0 a 0.4.1)

- Chasis completo construido desde cero: suelo (ahora con rejilla en
  prácticamente toda su superficie), paredes laterales, tapa, panel
  trasero, bandeja (con elevación real sobre sus pilares de apoyo) y
  los dos paneles frontales (inferior fijo + NFC extraíble).
- Encontrados y corregidos: postes/imanes que sobresalían de las
  paredes, patas y postes de anclaje mal posicionados, dos casos de
  coordenadas globales usadas donde hacían falta locales (soportes de
  la tapa "en el aire"), colisiones reales entre piezas del chasis
  nunca comprobadas entre sí, y — el hallazgo más importante — la
  bandeja no cabía en su recorrido de inserción aunque su posición
  final fuera correcta (ancho reducido de 150 a 130 mm).

### Verificaciones que respaldan el cierre

1. **Sintaxis**: limpia en las ~30 piezas del proyecto.
2. **Ensamblaje (28 pares)**: 28/28 sin colisión.
3. **Estructura vs 8 componentes electrónicos (32 pares)**: 29/32 sin
   colisión — los 3 restantes son contactos de anclaje intencionados
   (RC522, ESP32, HUB), no colisiones.
4. **Estructura vs estructura** (piezas del chasis entre sí): todos
   los pares relevantes verificados — la mayoría de forma manual con
   sondas dirigidas por la lentitud del script automático completo —
   sin colisión real, solo contactos de diseño esperados (suelo+
   paredes se imprimen como una pieza; tapa, panel trasero y paneles
   frontales se apoyan/atornillan a las paredes).
5. **Recorrido de inserción de la bandeja**: verificado en 4 alturas
   intermedias de su trayecto de bajada (no solo en la posición
   final) — sin obstrucción.

### Limitaciones conocidas, no bloqueantes

- Varias medidas quedan como estimadas, no confirmadas por el
  usuario: diámetro de la brida del USB (35 mm), huella de las patas
  en planta (10×10 mm).
- El comentario de separadores en `docs/02_Mechanical_Layout.md`
  sigue sin reconciliar con el valor real (20 mm) — solo texto, no
  afecta a ninguna pieza.
- No se ha verificado el recorrido de inserción de ninguna otra pieza
  aparte de la bandeja (paneles frontales, panel trasero, tapa) — se
  asume que sus rutas de montaje (encaje frontal/trasero por imanes o
  tornillos, no deslizamiento vertical) no tienen el mismo tipo de
  riesgo, pero no se ha comprobado explícitamente.

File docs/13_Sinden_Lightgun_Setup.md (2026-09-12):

# 13. Puesta en marcha de la Sinden Lightgun (Bazzite)

Procedimiento completo para dejar funcionando una Sinden Lightgun en la
Steam Machine (Bazzite/Fedora atómico), documentado tras la sesión del
2026-09-10/11. Escrito para no tener que redescubrir esto la próxima
vez — sobre todo la parte de adaptar las instrucciones oficiales
(pensadas para Arch/SteamOS) a Fedora/`rpm-ostree`.

---

## 0. Descartado antes: Wiimote + barra IR casera

Antes de tener la Sinden se intentó con un Wiimote + barra de LEDs
infrarrojos casera, usando `cwiid`/`wminput` (el software clásico para
traducir la cámara IR del Wiimote a puntero de ratón en Linux).

**Descartado**: `cwiid` no se actualiza desde hace más de una década y
falla con un error de Python (`PyCapsule_GetPointer called with
incorrect name`) incluso en su perfil más básico, en dos versiones
distintas de Debian (trixie y bookworm) — apunta a una incompatibilidad
de fondo con las versiones actuales de BlueZ, no arreglable cambiando
de distro. No merece la pena retomarlo salvo que aparezca un fork
mantenido. La alternativa moderna sería `xwiimote` (sí mantenido, ya
integrado en el kernel) + un script propio para traducir la posición IR
a ratón — no se ha llegado a escribir.

Con la Sinden Lightgun (periférico pensado específicamente para esto,
con software oficial) todo lo anterior deja de hacer falta.

---

## 1. Software oficial

Descargar desde `sindenlightgun.com/drivers/` — versión usada:
`SindenLightgunSoftwareReleaseV2.08b.zip`. Dentro:

```
SindenLightgunLinuxSoftwareV2.05/
├── SteamdeckVersion/Lightgun/   ← la que usamos (más cercana a Bazzite)
├── PCversion/
└── ARMversion/                   (Raspberry Pi, no aplica)
```

Copiar el contenido de `SteamdeckVersion/Lightgun/` a `~/Lightgun` en
la Steam Machine.

El `readme.txt` de esa carpeta trae las instrucciones oficiales, pero
están escritas para SteamOS/Arch (`pacman`, `steamos-readonly`) — no
funcionan tal cual en Bazzite. Lo que sigue es la traducción a
Fedora/`rpm-ostree`.

---

## 2. Dependencias (Fedora/Bazzite)

Bazzite es inmutable — los paquetes de sistema se instalan con
`rpm-ostree install` (no `dnf install` a secas) y **requieren
reiniciar** para aplicarse (a diferencia de `pacman` en SteamOS).

```bash
sudo rpm-ostree install mono-complete sdl12-compat SDL_image
systemctl reboot
```

Notas:
- `SDL2` ya viene de serie en Bazzite (`sdl2-compat`) — no hace falta
  instalarlo, y pedirlo junto con `SDL2-devel` provoca un conflicto de
  dependencias (`pkgconfig(glu)`) que no hace falta resolver, porque
  `-devel` tampoco hace falta para ejecutar el programa ya compilado.
- `mono-complete` sí está en los repos de Fedora directamente, sin
  necesidad de repos externos.
- `sdl12-compat` y `SDL_image` (la versión 1.2, no `SDL2_image`) están
  en Fedora con esos nombres exactos.

### 2.1. `libjpeg.so.8` — no está en Fedora, hay que sacarlo de un `.deb`

Fedora solo trae `libjpeg.so.62` (mucho más reciente); el software de
Sinden necesita literalmente la versión 8 (símbolo `LIBJPEG_8.0`) — un
enlace simbólico a la `.62` NO sirve, da error de versión de símbolo.

```bash
cd ~/Lightgun
curl -LO http://archive.ubuntu.com/ubuntu/pool/main/libj/libjpeg-turbo/libjpeg-turbo8_2.1.2-0ubuntu1_amd64.deb
ar x libjpeg-turbo8_2.1.2-0ubuntu1_amd64.deb
tar xf data.tar.xz
cp ./usr/lib/x86_64-linux-gnu/libjpeg.so.8 .
cp ./usr/lib/x86_64-linux-gnu/libjpeg.so.8.2.2 .
```

(El paquete `libjpeg8` de Ubuntu está vacío, solo depende de
`libjpeg-turbo8` — es este último el que hay que bajar.)

### 2.2. Nombres de librería exactos (Mono no busca con `lib` delante)

Mono busca los `.so` por el nombre EXACTO declarado en el binding, sin
el prefijo `lib` — hace falta un enlace:

```bash
cd ~/Lightgun
ln -s libSdlInterface.so SdlInterface.so
ln -s libCameraInterface.so CameraInterface.so
```

Para depurar qué librería falta en cada momento:

```bash
LD_LIBRARY_PATH=. ldd libSdlInterface.so
LD_LIBRARY_PATH=. ldd libCameraInterface.so
```

(mirar las líneas `not found` — sin `LD_LIBRARY_PATH=.` no encuentra
las que están en la propia carpeta).

---

## 3. Permisos: cámara y puerto serie

```bash
sudo usermod -a -G video $USER
```

### 3.1. El grupo `dialout` — fallo real de esta instalación de Bazzite

`usermod -a -G dialout` y `gpasswd -a ... dialout` **no funcionan** en
este sistema aunque no den ningún error: el grupo `dialout` que ve
`getent group dialout` no vive en `/etc/group` (que está casi vacío,
gestionado aparte por `systemd`/`altfiles`) — `gpasswd` incluso llega a
decir literalmente que el grupo "no existe en /etc/group", aunque
`getent` sí lo ve. Comprobado con `cat /etc/nsswitch.conf | grep
group`: `files [SUCCESS=merge] altfiles [SUCCESS=merge] systemd`.

Arreglo: añadir la línea a mano, con el mismo GID que ya tiene el
sistema (18, estándar en casi cualquier distro):

```bash
echo 'dialout:x:18:'"$USER" | sudo tee -a /etc/group
systemctl reboot
```

Tras reiniciar, `groups` debería incluir `dialout`. Sin esto, el
programa encuentra la pistola pero da "Permiso denegado" al intentar
abrir `/dev/ttyACM0`.

---

## 4. Firmware — necesita v1.9, no la de fábrica

El propio software avisa en mayúsculas: **hace falta firmware v1.9**
para que el modo joystick (usado para la calibración) funcione bien.
Con v1.8 (de fábrica en la unidad usada aquí), el gesto de calibración
(mantener D-pad izquierda 5s) no llega a registrarse — la calibración
se sale sola apuntando a la esquina inferior derecha sin que dé tiempo
a nada.

La actualización de firmware **requiere Windows** (no hay ruta
documentada desde Linux) — usar
`SindenLightgunWindowsV2.08/SindenLightgun/Lightgun.exe` en un PC con
Windows:

1. Instalar los drivers de `Tools/FirmwareUpdateDrivers/` si Windows no
   reconoce la pistola sola.
2. Abrir `Lightgun.exe`, pestaña de actualización de firmware, subir a
   v1.9.
3. **Paso aparte, no combinado con la actualización**: en esa misma
   pestaña, activar explícitamente la casilla de "joystick
   functionality" para cada pistola.
4. No desconectar la pistola ni cerrar el programa mientras actualiza.

---

## 5. Lanzar y calibrar

```bash
cd ~/Lightgun
LD_LIBRARY_PATH=. mono LightgunMono.exe steam joystick sdl
```

- `steam` → encoge la utilidad para que quepa en pantalla.
- `joystick` → modo joystick (necesita firmware v1.9, ver arriba).
- `sdl` → abre la utilidad de calibración.

**Requisito de luz — importante**: la cámara de la Sinden puede
"temblar"/dar saltos con luz solar, bombillas incandescentes/halógenas
cerca, o reflejos — confirmado en esta sesión que a oscuras la mira
queda perfectamente estable. Jugar con la sala en penumbra, sin luz
directa detrás/cerca de la pantalla.

Procedimiento de calibración (con la mira ya estable):
1. Apuntar al centro de la pantalla.
2. Mantener pulsado **D-pad izquierda** 5 segundos seguidos.
3. Cuando la mira se centre sola, **disparar** ahí.
4. Salir apuntando a la esquina inferior derecha de la pantalla.

Ajustes recomendados en el software de Sinden para este juego
concreto (pestaña "Main"): contraste 128, brillo 39. Monitor/TV a
60Hz (una tasa de refresco alta no le sienta bien al rastreo).

---

## 6. THE HOUSE OF THE DEAD: Remake — marco blanco + mod necesario

El juego se publicó **sin soporte nativo de lightgun**. Con el marco
blanco de Sinden por sí solo, varios usuarios reportan que la mira se
descalibra en cada cambio de escena/cutscene — hace falta un mod de
terceros para que sea jugable de verdad.

### 6.1. Ajuste de pantalla del juego (aparte del mod)

En los ajustes de vídeo del propio juego: **Screen Mode = Fullscreen
Window** (no pantalla completa exclusiva) — si no, el marco de Sinden
no se puede superponer encima del juego. Desactivar la mira propia del
juego en Ajustes → Gameplay (la de Sinden ya hace ese papel).

### 6.2. ArcadeMod (argonlefou) — instalación

Repositorio: `github.com/argonlefou/HotdRemake_ArcadePlugin`.

**Ojo con esto**: el paquete instalable está en la sección
**Releases** del repositorio (a la derecha en GitHub), NO en el botón
verde "Code → Download ZIP" — ese botón baja el código fuente, sin el
`.exe` ya compilado. Es un error fácil de cometer (hay varios usuarios
en los foros con la misma confusión, buscando un `ArcadeMod_Config.exe`
que "no existe" tras bajar el ZIP equivocado).

1. `github.com/argonlefou/HotdRemake_ArcadePlugin/releases` → última
   versión (v3.0 en el momento de escribir esto) → descargar el `.zip`
   de sus Assets.
2. Descomprimir todo el contenido en la carpeta raíz del juego (donde
   está `The House of the Dead Remake.exe`).
3. Quitar cualquier plugin antiguo previo (p.ej. el de "Mystery
   Wizard", de versiones más viejas del parche) — pueden chocar entre
   sí.
4. Ejecutar `ArcadeMod_Config.exe`:
   - `Input Type` = **SINGLE PLAYER** (con una sola Sinden basta; MULTIPLAYER
     necesita además DemulShooter, para 2 pistolas).
   - `Display Settings` → Screen Mode = **FULLSCREEN WINDOW**.
   - Ajustar resolución a la pantalla real.
   - Guardar con "Save Config" (genera `ArcadeMod_Config.ini`).
5. El juego puede fallar/cerrarse la PRIMERA vez que arranca tras
   cambiar resolución o modo de pantalla — fallo conocido y
   documentado por el propio autor. Volver a abrirlo una segunda vez.
6. Jugar con teclado (`1` = inicio P1, `2` = inicio P2, `5` = monedas)
   y after eso, ratón/lightgun.
7. Para desinstalar: borrar el `.dll` de `BepInEx\plugin\` en la
   carpeta del juego.

### 6.3. Aviso: compatibilidad con Proton sin confirmar

El ArcadeMod está pensado para Windows (usa BepInEx, un framework de
modding de Unity). La Steam Machine corre el juego vía **Proton**
(capa de compatibilidad de Steam), y no hay ninguna confirmación
encontrada de que este mod en concreto funcione bajo Proton — ningún
hilo de los revisados lo menciona probado en Linux. Puede funcionar
(muchos plugins de BepInEx sí lo hacen), pero es la primera vez que se
prueba aquí. Si no carga, probar forzando una versión de Proton
distinta (Proton GE suele arreglar líos de compatibilidad con
BepInEx).

---

## 7. Pendiente

- **Verificar dentro del Game Mode/Big Picture real** (gamescope), no
  solo en el escritorio de KDE donde se hizo esta puesta a punto —
  gamescope tiene problemas conocidos y todavía abiertos con
  dispositivos de ratón "emulados" (cursor invisible, entrada no
  capturada). No confirmado si afecta a este periférico en concreto.
- **Confirmar el ArcadeMod funcionando de verdad** bajo Proton en la
  Steam Machine (ver 6.3) — quedó pendiente de probar tras corregir el
  enlace de descarga (Releases, no Code).
- THE HOUSE OF THE DEAD 2: Remake tiene su propio parche, distinto
  (de "Disc0-LightgunMad", mencionado en `sindenwiki.org`) — no
  investigado todavía.
- **El marco blanco no aparece en Linux fuera de la utilidad de
  calibración** (`sdl`) — confirmado con capturas reales: ni
  `mono LightgunMono.exe joystick` en primer plano ni
  `mono-service LightgunMono.exe joystick` en segundo plano dibujan
  ningún marco continuo durante el juego. A diferencia de Windows, el
  port a Linux de Sinden no trae overlay de marco a nivel de sistema
  — confirmado también por comentarios de la comunidad ("sería genial
  que Sinden diera un marco a nivel de sistema como en Windows").
  Se descartó la vía física (tira de LED alrededor del monitor, más
  simple y sin depender de ningún software) a favor de un overlay
  propio, en construcción — ver siguiente punto.

## 8. Overlay de marco blanco a medida (KDE/Wayland) — EN CONSTRUCCIÓN, sin terminar

Bazzite/KDE aquí corre en **Wayland** (`echo $XDG_SESSION_TYPE` →
`wayland`), no X11 — confirmado. Bajo Wayland, una ventana normal no
puede colocarse "siempre encima de todo, incluido el juego a pantalla
completa" ni "dejar pasar el ratón a través suyo" sin usar el
protocolo `wlr-layer-shell` — por eso hace falta un programa propio
(no una simple ventana), usando **LayerShellQt** (Qt6 + C++). Se
comprobó que existe un proyecto ya hecho con esta misma técnica,
confirmado funcionando en Fedora KDE/Wayland (`github.com/Defiect/koverlay`,
para notas de texto) — sirvió para confirmar que la técnica es viable
en esta plataforma exacta antes de escribir la nuestra.

### Dónde se quedó

Código en `~/sinden_border/` (dentro de una distrobox de **Fedora 44**,
`distrobox create --name sindenborder --image fedora:44` — Fedora, no
Debian, para que las librerías de Wayland/Qt coincidan con las del
sistema anfitrión).

Dependencias (dentro de la distrobox):
```bash
sudo dnf install -y qt6-qtbase-devel qt6-qtdeclarative-devel layer-shell-qt-devel wayland-devel cmake gcc-c++ make
```

`CMakeLists.txt` — el nombre real del paquete CMake es `LayerShellQt`
(NO `LayerShellQtInterface`, que era una suposición inicial
equivocada), con el target `LayerShellQt::Interface`:
```cmake
cmake_minimum_required(VERSION 3.16)
project(sinden_border)

set(CMAKE_AUTOMOC ON)
set(CMAKE_CXX_STANDARD 17)

find_package(Qt6 REQUIRED COMPONENTS Widgets)
find_package(LayerShellQt REQUIRED)

add_executable(sinden_border main.cpp)
target_link_libraries(sinden_border PRIVATE Qt6::Widgets LayerShellQt::Interface)
```

`main.cpp` — un `QWidget` sin decoración, fondo transparente, que
pinta solo un marco blanco (grosor configurable por argumento,
40px por defecto) y usa `LayerShellQt::Window` para anclarse a los 4
bordes de la pantalla en la capa superior (`LayerOverlay`), sin robar
el teclado (`KeyboardInteractivityNone`) y transparente para el ratón
(`Qt::WindowTransparentForInput` + `Qt::WA_TransparentForMouseEvents`):

```cpp
#include <QApplication>
#include <QWidget>
#include <QPainter>
#include <QScreen>
#include <QWindow>
#include <LayerShellQt/Window>

class BorderOverlay : public QWidget
{
public:
    explicit BorderOverlay(int thickness) : m_thickness(thickness)
    {
        setAttribute(Qt::WA_TranslucentBackground);
        setAttribute(Qt::WA_TransparentForMouseEvents);
        setWindowFlag(Qt::FramelessWindowHint);
        setWindowFlag(Qt::WindowStaysOnTopHint);
        setWindowFlag(Qt::WindowTransparentForInput);
    }

protected:
    void paintEvent(QPaintEvent *) override
    {
        QPainter p(this);
        p.setPen(Qt::NoPen);
        p.setBrush(Qt::white);
        const int w = width();
        const int h = height();
        p.drawRect(0, 0, w, m_thickness);
        p.drawRect(0, h - m_thickness, w, m_thickness);
        p.drawRect(0, 0, m_thickness, h);
        p.drawRect(w - m_thickness, 0, m_thickness, h);
    }

private:
    int m_thickness;
};

int main(int argc, char *argv[])
{
    QApplication app(argc, argv);

    int thickness = (argc > 1) ? QString(argv[1]).toInt() : 40;

    BorderOverlay overlay(thickness);
    QScreen *screen = QGuiApplication::primaryScreen();
    overlay.setGeometry(screen->geometry());
    overlay.show();

    auto lsWindow = LayerShellQt::Window::get(overlay.windowHandle());
    lsWindow->setLayer(LayerShellQt::Window::LayerOverlay);

    LayerShellQt::Window::Anchors anchors(LayerShellQt::Window::AnchorTop);
    anchors |= LayerShellQt::Window::AnchorBottom;
    anchors |= LayerShellQt::Window::AnchorLeft;
    anchors |= LayerShellQt::Window::AnchorRight;
    lsWindow->setAnchors(anchors);

    lsWindow->setExclusiveZone(-1);
    lsWindow->setKeyboardInteractivity(LayerShellQt::Window::KeyboardInteractivityNone);
    lsWindow->setScope(QStringLiteral("sinden-border"));

    return app.exec();
}
```

### Fallos ya encontrados y corregidos, por si se repiten

- `find_package(LayerShellQtInterface)` → nombre real es
  `find_package(LayerShellQt)`, target `LayerShellQt::Interface`.
  Confirmado con `rpm -ql layer-shell-qt-devel | grep -i cmake`.
- `LayerShellQt::Window::AnchorTop | ... | AnchorRight` pasado
  directamente a `setAnchors()` → error de compilación (`invalid
  conversion from 'int' to 'LayerShellQt::Window::Anchor'`, con
  `-fpermissive`): el operador `|` entre valores del enum da un `int`
  normal, no el `QFlags` que espera Qt. Arreglado construyendo el
  `QFlags` explícitamente (`LayerShellQt::Window::Anchors anchors(...);
  anchors |= ...;`) en vez de un único `|` encadenado.

### Siguiente paso (sin hacer todavía)

Con el fallo de compilación de arriba corregido en el propio
`main.cpp` (ver más arriba, ya corregido en el código de esta
sección), toca:
```bash
cd ~/sinden_border/build
make
./sinden_border
```
Y comprobar en pantalla: ¿aparece el marco blanco?, ¿el centro es
realmente transparente (se ve el escritorio a través)?, ¿el ratón
atraviesa la ventana (un clic en algo de debajo funciona con
normalidad)? Sin probar todavía.

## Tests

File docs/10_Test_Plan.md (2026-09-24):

\# SteamMachine UM790

\# 10 - Test Plan

Version: 1.0

Status: Active

\---

\# Objetivo

Este documento define el procedimiento de validación completo del proyecto SteamMachine UM790.

Cada fase del proyecto deberá superar las pruebas correspondientes antes de considerarse finalizada.

No se avanzará a la siguiente fase hasta completar satisfactoriamente la anterior.

\---

\# Tipos de pruebas

Las pruebas se dividen en seis categorías:

\- Mecánicas

\- Térmicas

\- Eléctricas

\- Firmware

\- Software

\- Integración

\---

\# 1. Validación del ensamblaje virtual

\## Objetivo

Verificar que todos los componentes pueden coexistir sin interferencias.

\## Pruebas

\### T001 — Colisión de componentes

Comprobar:

\- UM790

\- Ventilador

\- RC522

\- ESP32

\- HUB USB

\- OLED

\- Pulsador

\- USB frontales

Resultado esperado

Ninguna colisión.

Estado

Pendiente

\---

\### T002 — Holguras de montaje

Verificar:

\- Cableado

\- Tornillos

\- Insertos

\- Conectores

Holgura mínima

3 mm

Resultado esperado

Sin interferencias.

\---

\### T003 — Accesibilidad

Verificar acceso a:

\- Tornillos

\- Panel trasero

\- USB

\- OLED

\- Ventilador

Resultado esperado

Acceso posible sin desmontar el equipo completo.

\---

\# 2. Validación mecánica

\## T010 — Chasis inferior

Comprobar:

\- Rigidez

\- Planitud

\- Ajuste de insertos

\- Soportes

Resultado

Sin deformaciones.

\---

\## T011 — Chasis superior

Verificar:

\- Ajuste

\- Tornillería

\- Ventilación

\---

\## T012 — Panel frontal

Verificar

\- Imán

\- OLED

\- USB

\- Pulsador

\- Barra LED

\---

\## T013 — Panel trasero

Verificar

\- Todos los conectores accesibles

\---

\## T014 — Paneles NFC

Verificar

\- Inserción

\- Extracción

\- Lectura NFC

Resultado esperado

100 % de lectura.

\---

\# 3. Validación térmica

\## Objetivo

Garantizar el funcionamiento continuo.

\---

\## T020 — Reposo

Equipo

Bazzite

30 minutos

Registrar

CPU

SSD

Temperatura ambiente

\---

\## T021 — Carga máxima

Ejecutar

Prime95

\+

FurMark

Durante

30 minutos

Registrar

Temperaturas

RPM

Ruido

\---

\## T022 — Deformación de las piezas (PETG)

Durante T021 y T070, medir con termómetro IR la temperatura de las piezas más
expuestas (junto a la salida de aire y pegadas al mini PC).

Resultado esperado

Sin deformación visible ni holguras nuevas tras 24 h. Temperatura de la
pieza claramente por debajo del ablandamiento del PETG (~70-80 °C).

\---

\## Límites

CPU

< 85°C

SSD

< 70°C

Ventilador

Sin vibraciones.

\---

\# 4. Validación eléctrica

\## T030

ESP32

Arranque correcto.

\---

\## T031

OLED

Mostrar texto.

\---

\## T032

Barra LED

Todos los colores.

\---

\## T033

RC522

Detectar paneles.

\---

\## T034

USB frontales

Transferencia de archivos.

\---

\# 5. Validación firmware

Pruebas realizadas a mano por el monitor serie de PlatformIO
(`pio device monitor`), sobre el ESP32-WROOM-32D DevKit real ya
cableado — ver `firmware/README.md`, sección "Prueba de integración",
para el procedimiento paso a paso.

\## T040

Arranque

Enviar BOOT.

Resultado: ✔ Superado (2026-08-25). Al arrancar (o tras pulsar RESET
con el monitor abierto) aparece `{"event":"boot","firmware":"1.0.0"}`,
precedido del ruido normal del bootloader del ESP32.

\---

\## T041

Lectura NFC

Enviar UID correcto.

Resultado: ✔ Superado (2026-08-25). Acercar un tag genera
`{"event":"tag","uid":"..."}` con un UID de 8 caracteres hex, y
permanece detectado mientras el tag sigue puesto (confirmado 10-15s
sin `tag_removed` falso). Se encontró y corrigió un fallo real por el
camino: `{"event":"tag_removed"}` se disparaba a los ~450ms aunque el
tag siguiera físicamente puesto (causa: `PICC_HaltA()` dejaba la
tarjeta en un estado que no responde al sondeo siguiente — ver
CHANGELOG.md v1.1.4). Confirmado corregido en hardware real tras
reflashear.

\---

\## T042

Pulsador

Enviar evento.

Resultado: ✔ Superado (2026-08-25). Cada pulsación genera
`{"event":"button"}`. Confirmado en GPIO13 (ver
`firmware/src/config.h`) — deja de estar marcado como pin provisional.

\---

\## T043

OLED

Actualizar información.

Resultado: ✔ Superado (2026-08-25). `{"cmd":"oled",...}`,
`{"cmd":"oled2",...}` y `{"cmd":"oled_clear"}` funcionan correctamente
en hardware real.

\---

\## T044

LED

Actualizar color.

Resultado: ✔ Superado (2026-08-25), tras una incidencia real que se
documenta aquí porque fue instructiva: la primera vez que se probó
(`{"cmd":"led","color":"#FF0000"}`), la tira no encendía, aunque el
comando se enviaba correctamente (confirmado con `--echo` en el
monitor). Se aisló el problema desconectando el nivelador lógico
74AHCT125 y conectando el ESP32 directo a un tramo de prueba de 8
LEDs: encendió bien. Con el 74AHCT125 en el circuito, nada — causa más
probable, el pin /1OE del chip flotante en vez de a GND (fallo típico
de este componente). Se decidió retirar el 74AHCT125 del diseño por
completo en vez de depurar el cableado del chip; la tira (8 LEDs,
confirmado como dato real y definitivo) funciona bien recibiendo la
señal directa del GPIO25 a 3.3V. Ver CHANGELOG.md v1.1.3 para el
historial completo de esta decisión, y
`Hardware/Hardware_Connections.md` para el cableado actualizado.

\---

\## T045

Recuperación

Desconectar USB.

Reconectar.

Debe recuperar la comunicación.

Resultado: ✔ Superado (2026-08-25). Tras un reinicio (equivalente
eléctricamente a desconectar/reconectar el USB), el ESP32 arranca
limpio y vuelve a mandar `{"event":"boot","firmware":"1.0.0"}`. Nota:
Windows puede reasignar el número de puerto COM al reconectar (visto
pasar de COM10 a COM7) — el Core lo detecta automáticamente por
VID:PID, así que no debería ser un problema; a tener en cuenta si se
fija el puerto a mano en `config.json`.

Nota adicional (2026-09-06): esta prueba cubre el lado del firmware
(el ESP32 arranca limpio). El lado del **Core en Python** tenía un
fallo real y distinto en su propia lógica de reconexión
(`SerialManager`), que solo se manifestó al arrancar por systemd sin
el ESP32 todavía listo — ver CHANGELOG.md v1.2.3 para el diagnóstico
completo y la corrección. Verificado con los tests existentes y una
prueba dirigida que simula el escenario real, y confirmado en
hardware real: tras actualizar el Core, un reinicio completo del
mini PC deja el servicio `active (running)` sin caerse.

\---

\# 6. Validación software

\## T050

Carga configuración.

Resultado: ✔ Superado (2026-08-25). El Core arranca, carga
`config.json` y conecta al ESP32 automáticamente por VID:PID (visto
en el log: "Conectado al ESP32 en COM7 @ 115200 bps").

\---

\## T051

Carga base de datos.

Resultado: ✔ Superado (2026-08-25). Carga `panel_database.json` y
reconoce el UID real del tag, asociándolo al perfil "Steam".

\---

\## T052

Reconocimiento de panel.

Resultado: ✔ Superado (2026-08-25). Acercar el tag genera "Panel
detectado" + "Perfil 'Steam' listo. Esperando pulsador..." en el log,
sin comandos manuales.

\---

\## T053

Cambio OLED.

Resultado: ✔ Superado (2026-08-25). Confirmado visualmente: la
pantalla muestra "Steam" al detectar el panel, y cambia a "Steam" /
"Launching..." (las dos líneas, `show_status()`) al pulsar el botón.

\---

\## T054

Cambio LED.

Resultado: ✔ Superado (2026-08-25). Al pulsar el botón con el panel
detectado, el log confirma "Lanzando plataforma: steam" — dispara la
animación de LEDs correspondiente (el fundido de color al detectar el
panel usa el mismo mecanismo, ya validado en T044 de firmware).

\---

\## T055

Lanzamiento de Steam.

\---

\## T056

Lanzamiento RetroDECK.

\---

\## T057

Lanzamiento de un emulador dentro de RetroDECK (p.ej. PS3 via RPCS3 integrado).

\---

\## T058

Lanzamiento panel Zombies (HOTD Remake / HOTD 2 Remake, via Steam).

\---

\## T059

Salida correcta.

\---

\# 7. Validación integración

\## T060

Sistema apagado.

Encender.

Debe iniciar correctamente.

\---

\## T061

Cambiar panel.

Actualizar OLED.

Actualizar LEDs.

Esperar botón.

\---

\## T062

Lanzar aplicación.

\---

\## T063

Cerrar aplicación.

Volver al estado Idle.

\---

\## T064

Repetir

100 veces.

Sin errores.

\---

\## T065

Apagado ordenado con el panel Apagar.

1. Colocar el panel: la OLED muestra APAGAR EQUIPO y NO se apaga nada.

2. Pulsar el botón: OLED Apagando..., LEDs a negro, el equipo se apaga.

3. Encender de nuevo: Bazzite debe arrancar sin pasar por grub>.

4. Repetir con una actualización de Bazzite en curso: debe salir Error al apagar y el equipo seguir encendido.

Previo: `systemctl poweroff` a mano debe apagar sin pedir contraseña.

\---

\# 8. Ensayos prolongados

\## T070

Funcionamiento continuo

24 horas.

\---

\## T071

500 cambios de panel NFC.

\---

\## T072

500 pulsaciones.

\---

\## T073

100 lanzamientos de aplicaciones.

\---

\# 9. Criterios de aceptación

Cada prueba tendrá uno de estos estados.

PASS

FAIL

BLOCKED

NOT TESTED

\---

\# 10. Registro

Cada prueba deberá registrar

Fecha

Versión

Responsable

Resultado

Observaciones

\---

\# 11. Checklist de entrega

☐ Ensamblaje virtual validado

☐ Chasis impreso

☐ Paneles ajustados

☐ Temperaturas correctas

☐ Firmware estable

☐ Software estable

☐ Comunicación estable

☐ Integración completada

☐ Documentación actualizada

☐ STL publicados

☐ Release GitHub creada

\---

\# Estado

Documento activo.

Será actualizado conforme avance el proyecto.

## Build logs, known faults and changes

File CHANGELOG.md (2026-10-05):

# Changelog

Todos los cambios importantes de este proyecto se documentarán en este archivo.

El formato está inspirado en [Keep a Changelog](https://keepachangelog.com/) y el proyecto sigue Versionado Semántico (Semantic Versioning).

---

## [Sin publicar] - 2026-10-05 — Hub USB nuevo (placa alargada 4x USB-A) en la pared derecha

### Cambiado

- El hub USB CJMCU-204 (44,1 x 44,1 mm, postes Ø3 a 36,1 x 21 mm) se
  sustituye por una placa alargada de 68,7 x 18,2 mm con 4 bocas USB-A
  en un lado largo y entrada USB-C en un extremo.
- Se monta en la pared DERECHA, en horizontal, con las bocas USB-A
  hacia ARRIBA. Centro en Y=0, Z=82 (`usb_hub_mount_z`), más bajo que
  antes (97,8) para dejar ~57 mm libres por encima para las clavijas.
- `hubMountBosses()` (walls.scad): 4 postes Ø5 x 4 mm (antes Ø8 x 2 mm)
  a 64,7 x 14,2 mm, con piloto Ø1,8 para tornillo M2x6 autorroscante
  (entra 1,5 mm en la pared, queda 1,5 mm de piel exterior). Los 4
  postes antiguos desaparecen.
- `00_parametros.scad`: `usb_hub_*` redefinidos;
  `usb_hub_mount_inset_z/y` sustituidos por
  `usb_hub_hole_spacing_x/y`. `hub_pos` usa ahora `usb_hub_standoff` y
  `usb_hub_mount_z`.
- `hub_usb.scad` v2.0: modelo de referencia del hub nuevo; el volumen
  de cableado está ahora por encima de las bocas (40 mm).
- `STL/rightwall_flat2.stl` regenerado (misma posición en la cama que
  el anterior). Comprobado: estanco, 1 solo cuerpo; 28/28 pares sin
  colisión en el ensamblaje virtual.

### Corregido

- Rebaje de los imanes del panel frontal (`frontMagnetCuts()`,
  walls.scad): no se quedaba solo en el relleno, ahora se prolonga
  también por la pared, desde el borde frontal hasta el relleno (canal
  semicircular de ~2 mm, 1 mm de piel exterior), como en el
  `leftwall_flat2.stl` de referencia del usuario. La fuente reproduce
  ahora ese STL (diferencia < 1 mm³, solo facetado).
  `STL/rightwall_flat2.stl` regenerado con el rebaje.

### Pendiente

- Medidas del hub tomadas de fotos con cinta métrica: confirmar con
  calibre la separación entre taladros (64,7 x 14,2 mm) antes de
  imprimir.

## [1.6.0] - 2026-09-21 — Panel NFC Apagar (apagado ordenado), caja de paneles documentada y material a PETG

### Contexto

- Cuando el equipo se apaga de golpe, a veces Bazzite no vuelve a
  arrancar y hay que restaurarlo desde la consola (ver `grub>` en
  `GUIA_INICIO.md`). Se añade un panel NFC para apagar de forma ordenada.
- El PLA se deforma con la temperatura del equipo: todas las piezas
  pasan a imprimirse en PETG.

### Añadido

- `software/core/power_manager.py` (`PowerManager`): ejecuta
  `systemctl poweroff` (configurable en `power.poweroff_command`), sin
  excepciones; `dry_run` en modo simulado para no apagar la máquina de
  desarrollo.
- Perfil `APAGAR` (`config/profiles/apagar.json`, `action: "poweroff"`) y
  entrada `UID_APAGAR_PENDIENTE` en `panel_database.json`.
- `Application`: acciones de sistema por perfil (lista cerrada), aviso en
  OLED/LEDs antes de apagar, error visible si el sistema rechaza la
  orden, y el Core ignora eventos mientras se apaga. Al cerrarse el
  servicio por el apagado, la OLED queda limpia.
- 25 tests nuevos (122 en total). Los tests no tocan `logs/steammachine.log`.
- `docs/14_Caja_Paneles_NFC.md`: la caja de paneles (6 ranuras) no
  estaba documentada. Medidas comprobadas contra los STL.
- `Apagar.stl` documentado (ya estaba en `STL/Anagramas/`).
- Pruebas T022 (deformación térmica de las piezas) y T065 (apagado
  ordenado) en `docs/10_Test_Plan.md`.

### Cambiado

- Material: PETG para todas las piezas (README, GUIA_INICIO, docs 07,
  11, `Printing_Lower_Panel.md`, caja). Notas: los dos filamentos del
  panel inferior deben ser PETG; el cianoacrilato agarra peor en PETG.
- README: corregido un `---` pegado al final de una frase.

### Pendiente

- Sustituir `UID_APAGAR_PENDIENTE` por el UID real del tag.
- Probar el apagado en el hardware real (T065); no verificado que polkit
  permita `systemctl poweroff` desde el servicio de usuario.
- Validar holguras de la caja/tapa y del resto de piezas en PETG (T022).
- `Apagar.stl` no tiene `.scad` paramétrico (como `Gung.stl`).
- `VERSION.md` sigue en v1.1.3, desfasado respecto a este CHANGELOG.

---

## [1.5.8] - 2026-09-11 — Documentada la puesta en marcha de la Sinden Lightgun (Bazzite)

### Contexto

- Sesión completa (2026-09-10/11) llevando la Sinden Lightgun desde
  "no se lee" hasta calibrada y jugando, en la propia Steam Machine
  (Bazzite). Se intentó primero con un Wiimote + barra IR casera
  (`cwiid`/`wminput`) — descartado por incompatibilidad de fondo entre
  ese software (sin mantenimiento desde hace más de una década) y las
  versiones actuales de BlueZ, confirmado con el mismo fallo en dos
  versiones distintas de Debian.

### Añadido

- `docs/13_Sinden_Lightgun_Setup.md`: procedimiento completo,
  documentado para no tener que redescubrirlo — traducción de las
  instrucciones oficiales de Sinden (pensadas para Arch/SteamOS) a
  Fedora/`rpm-ostree`; extracción manual de `libjpeg.so.8` desde un
  `.deb` de Ubuntu (no está en Fedora); el fallo real de esta
  instalación con el grupo `dialout` (vive fuera de `/etc/group`,
  `usermod`/`gpasswd` no lo tocan sin editar el fichero a mano);
  requisito de firmware v1.9 (con "joystick functionality" activada)
  para que la calibración funcione; requisito de sala en penumbra
  (confirmado en esta sesión: con luz ambiental la mira tiembla,
  a oscuras queda estable); instalación del ArcadeMod de argonlefou
  para THE HOUSE OF THE DEAD: Remake (con el aviso de descargarlo
  desde la sección Releases del repositorio, no desde "Code → Download
  ZIP", que da un `.exe` inexistente — error real cometido en esta
  misma sesión).

### Pendiente (anotado en el propio documento)

- Confirmar que todo esto funciona igual dentro del Game Mode/Big
  Picture real (gamescope), no solo en el escritorio de KDE.
- Confirmar el ArcadeMod funcionando bajo Proton en la Steam Machine.
- THE HOUSE OF THE DEAD 2: Remake usa un parche distinto, sin revisar
  todavía.
- **Confirmado: el marco blanco no aparece en Linux** fuera de la
  utilidad de calibración (`sdl`) — ni en primer plano ni con
  `mono-service` en segundo plano. A diferencia de Windows, el port a
  Linux de Sinden no trae overlay de marco a nivel de sistema.
- **Overlay propio en construcción, sin terminar** (`docs/13_Sinden_Lightgun_Setup.md`,
  sección 8): programa en C++/Qt6 con `LayerShellQt` para dibujar el
  marco por encima de todo bajo Wayland/KWin (confirmado que la sesión
  de KDE aquí es Wayland, no X11). Ya corregidos dos fallos de
  compilación reales (nombre del paquete CMake `LayerShellQt`, no
  `LayerShellQtInterface`; conversión de `QFlags` en `setAnchors()`).
  Queda por compilar y probar en pantalla — sesión cortada por falta
  de tiempo antes de llegar a ese punto.

---

## [1.5.7] - 2026-09-09 — Corregido: los postes de las patas invadían 1mm el grosor macizo de la pared, en las 4 esquinas

### Contexto

- El usuario, con una captura de OpenSCAD (`floor_flat.scad`, 4
  círculos rojos en las esquinas): "los soportes para los insertos
  siguen interfiriendo con los paneles laterales".

### Corregido

- `floor.scad`, `leg_edge_margin`: nunca tuvo en cuenta el grosor de
  la propia pared (`wall_thickness`=3mm) al calcular el margen desde
  el borde de la carcasa — solo restaba 2mm. El poste de la pata
  (Ø10mm) llegaba hasta X=76 en las 4 esquinas por igual, invadiendo
  1mm el tramo macizo de la pared (X 75-78) — no un inserto
  concreto de la pared, la pared en sí, en cualquier punto de su
  longitud. Por eso "seguía" pasando tras el ajuste de [1.5.3], que
  solo corrigió la posición en Y contra insertos concretos, no este
  solape en X contra el grosor base. Subido `leg_edge_margin` de 2 a
  4mm — el poste ahora llega como mucho a X=74, con 1mm de margen
  limpio respecto a la cara interior de la pared (X=75). Verificado
  que no introduce ningún solape nuevo (con tray posts, con el
  injerto suelo-pared) — al mover el poste hacia el centro, solo
  gana margen, nunca lo pierde.

---

## [1.5.6] - 2026-09-09 — Corregido: el rebaje de pines de la OLED abría por fuera en vez de por dentro

### Contexto

- El usuario adjuntó su propio `lower_panel.scad` ("el fichero
  correcto es este") tras detectar que mi reconstrucción de [1.4.9]
  tenía el rebaje de pines de la OLED abierto por la cara EXTERIOR
  del panel en vez de por la INTERIOR.

### Corregido

- `oledCut()`: el rebaje ciego para los pines de soldadura arrancaba
  en `-case_depth/2` (cara exterior, donde se ve la pantalla) y
  cortaba `oled_pin_clearance_pocket_depth` hacia dentro — dejaba el
  hueco abierto por fuera y cerrado justo donde están los pines (la
  cara interior, contra la que apoya el módulo). Invertido: ahora
  arranca cerca de la cara interior
  (`-case_depth/2 + front_panel_thickness - oled_pin_clearance_pocket_depth`)
  y corta hacia allí, dejando la piel sólida hacia fuera (no importa,
  no la alcanza nada) y el hueco abierto hacia dentro, donde
  sobresalen los pines de verdad.
- `openscad/parts/03_panels/lower_panel.scad` sustituido entero por
  el fichero del usuario, no solo el fragmento del rebaje — trae
  además el historial real de esta corrección (varias rondas de
  ida y vuelta el 2026-08-29, incluida una vez anterior en la que
  también quedó "por fuera en lugar de por dentro") que mi
  reconstrucción de [1.4.9], al venir del CHANGELOG y no de esa
  sesión, no tenía capturado con el mismo detalle.

---

## [1.5.5] - 2026-09-08 — Descartado `oled_bracket.scad`; la OLED se fija con 4 tornillos directos

### Contexto

- Revisando el despiece pieza a pieza, el usuario confirmó: la brida
  de sujeción de la OLED (`oled_bracket.scad`, [2026-08-22]) "solo
  fue un modelo para analizar pero está descartado". La fijación real
  es con 4 tornillos directos a través de `lower_panel.scad`
  (`oledMountHoles()`, ya implementada desde antes que la brida y
  nunca sustituida).

### Descubierto de paso

- La brida nunca llegó a tener sus bosses de anclaje
  (`oledInsertBosses()`) realmente construidos en `lower_panel.scad`
  — quedaron solo como parámetros reservados en
  `assembly_positions.scad` (`oled_bracket_*`), sin ninguna geometría
  que los usara. No había nada que desmontar en la pieza impresa real,
  solo limpieza de datos muertos.

### Eliminado / movido

- `openscad/parts/03_panels/oled_bracket.scad` y su STL, movidos a
  `obsoletos/parts_03_panels/` (mismo criterio ya establecido en
  [2026-08-14] para piezas descartadas — conservados como referencia
  histórica, marcados ⚠️ OBSOLETO, sin usarse). `obsoletos/README.md`
  actualizado.
- `assembly_positions.scad`: bloque `oled_bracket_*` (insertos, bosses,
  posiciones de tornillo) y la copia de `oled_screen_width/height`
  que solo consumía la brida — comentados, no borrados, con nota de
  por qué existían (para no perder el criterio numérico ya
  comprobado, por si se retoma en el futuro). `oled_pos` y el resto
  de referencias que sí siguen en uso, intactos.

### Corregido

- `docs/11_Assembly_Manual.md`: paso de montaje de la OLED,
  actualizado de "brida + 2 tornillos M2" a "4 tornillos directos a
  través del panel inferior", que es lo que de verdad se monta.
- Comentario suelto en `lower_panel.scad` que aún daba a entender que
  la brida seguía activa, corregido.

---

## [1.5.4] - 2026-09-08 — Avellanado del injerto M3 suelo-pared; VERSION.md eliminado (redundante con este CHANGELOG); manual de montaje al día

### Corregido

- `floorWallGraftClearanceHoles()` ([1.5.2]): aviso del usuario ("los
  orificios... parecen muy grandes y sin avellanado"). El diámetro
  (Ø3,4mm) es la holgura M3 estándar ya usada en el resto del
  proyecto, no un tamaño fuera de lo normal — pero le faltaba el
  avellanado cónico que sí llevan el resto de tornillos que entran
  desde una cara exterior (tapa, panel trasero, panel inferior, todos
  Ø6mm). Añadido, mismo criterio.

### Eliminado

- `VERSION.md`: a petición del usuario ("si consideras que documentos
  como VERSION.md no tienen sentido los podríamos eliminar"). Sin
  referencias entrantes desde ningún otro fichero (verificado antes
  de borrar). Es precisamente el fichero que estaba desincronizado
  (v1.1.3) cuando destapamos el desajuste del ZIP en [1.4.9] — este
  CHANGELOG ya hace de fuente única de verdad sobre el estado del
  proyecto, sin necesidad de un "número de versión" aparte que
  mantener sincronizado a mano.

### Cambiado

- `docs/11_Assembly_Manual.md`, Paso 1: "instalar patas" sustituido
  por la secuencia real — pie desmontable atornillado desde fuera
  ([1.5.2]/[1.5.3]) — y añadido el paso de atornillar el suelo a cada
  pared por el injerto M3 antes de montar el resto ([1.5.2]).

---

## [1.5.3] - 2026-09-08 — Corregido: la rejilla del suelo no atravesaba la pieza; retirada a petición del usuario; patas reubicadas (colisión con insertos de pared)

### Contexto

- Sesión de revisión de `floor_flat.scad`/`leftwall_flat.scad`/
  `rightwall_flat.scad`/`foot.scad` (impresión plana del chasis,
  ver [1.5.2]). El usuario aportó capturas del visor de OpenSCAD que
  destaparon dos fallos reales en `floor.scad`, no solo apariencia.

### Corregido

- `floorVentCut()`: `valvePattern()` (`lib/ventilation.scad`) usa
  `cube(..., center=true)`, que centra el corte también en Z. Con el
  `translate(Z=-1)` que tenía, el corte real quedaba entre Z=-3,5 y
  Z=1,5, mientras el suelo ocupa Z=0 a `bottom_thickness`=3 — solo se
  cortaba la mitad inferior, dejando 1,5mm de piel maciza sin cortar
  en la cara de arriba de los ~60 rombos a la vez. Nunca atravesaron
  la pieza. Corregido moviendo el punto de partida al centro real del
  grosor de la placa (`bottom_thickness/2`); verificado con los
  números que el nuevo rango (Z -1 a 4) cubre de sobra el suelo.
- `floorLegMountInserts()` ([1.5.2]): el taladro del inserto M3 solo
  abría dentro del propio poste (desde Z=2,9 hacia arriba) — nunca
  atravesaba los 3mm de la placa del suelo. Visto desde la cara
  exterior real (Z=0), los postes se veían macizos. Añadido
  `floorLegScrewClearanceHoles()`: taladro de paso M3 (Ø3,4mm,
  distinto del taladro del inserto) que sí atraviesa la placa entera,
  restado a nivel de `chassisFloor()`.
- `leg_center_offset_y` (patas del pie desmontable, [1.5.2]): a la Y
  de la esquina real (74,2mm) el poste de la pata invadía el relleno
  del tornillo del panel inferior en la pared (Z 3-17,
  `lower_panel_screw_z_low`=10) — solape real de 8×9×7mm, confirmado
  con las cotas exactas, no solo aparente en el visor. La esquina
  trasera, a la misma Y en positivo, coincidía igual de lleno en X/Y
  con el relleno del tornillo del panel trasero, pero se libraba solo
  porque ese relleno vive a otra Z (20-34 y 123-137) — un margen de
  seguridad accidental. Reubicadas las 4 patas a Y=±32: lejos de
  ambos rellenos (27mm+ de margen) y del injerto suelo-pared
  ([1.5.2], Y=±50 — 7mm de margen). Base de apoyo resultante: 64mm
  delante-detrás × 142mm en X.

### Cambiado

- `chassisFloor()`: ya NO llama a `floorVentCut()` — petición del
  usuario ("debilitaba mucho la pieza" + uno de los taladros del
  injerto M3 suelo-pared coincidía con un rombo, área ocupada por la
  rejilla hasta casi el borde). El módulo `floorVentCut()` se
  conserva definido en el fichero, sin usarse, por si se retoma con
  otra distribución.
- Ventilación de entrada de aire: sin la rejilla, la entrada pasa a
  ser el hueco ya existente bajo el clúster frontal
  (`frontClusterRelief()`, pulsador/OLED/USB) — comprobado con el
  usuario que da un área libre similar (6.526mm² vs 7.241mm² de la
  rejilla retirada, ~90%) y solapa parcialmente (~14mm) con el borde
  delantero de la placa del UM790, aunque no queda centrado bajo el
  disipador como pretendía el diseño original de la rejilla. Sin
  verificación térmica real — pendiente de comprobar con una
  impresión y uso real; si hiciera falta más caudal, el usuario
  propuso como plan B una rejilla que empiece a ~2cm del borde (fuera
  ya del alcance de los taladros de los insertos).
- Confirmado con el usuario (sin cambios de diseño): el ventilador
  superior debe EXTRAER aire (no impulsarlo hacia dentro) — coincide
  con `docs/DESIGN_RULES.md` ("Entrada inferior. Salida superior.")
  y con como ya se le llamaba en un comentario de `top.scad`, "el
  extractor".

---

## [1.5.2] - 2026-09-08 — Impresión plana del chasis: injerto M3 suelo-pared (nuevo), pie desmontable reconciliado, insertos de la tapa realineados

### Contexto

- El usuario pidió revisar `floor_flat.scad`/`leftwall_flat.scad`/
  `rightwall_flat.scad`/`foot.scad` — preparados en otra sesión, sin
  ninguna entrada en este CHANGELOG hasta ahora — contra 5
  requisitos: impresión plana, unión por injertos M3, patas
  desmontables con M3, altura total ≤ la original, suelo realmente
  liso por abajo, y sin colisión entre insertos.

### Añadido

- **Injerto M3 suelo-pared** (`openscad/reference/components/assembly_positions.scad`,
  `walls.scad`, `floor.scad`): no existía NINGÚN punto de fijación
  entre el suelo y las paredes. Nuevo: `floorWallGraftBoss()`/
  `floorWallGraftInsertCuts()` (pared, inserto M3 ciego) +
  `floorWallGraftClearanceHoles()` (suelo, taladro de paso) — 2
  puntos por pared, Y=±50 (global), elegidos por quedar lejos de
  todos los insertos ya existentes en la pared (imanes/tornillos del
  panel inferior y trasero, ESP32, HUB).
- `floorLegMountInserts()` (`floor.scad`): sustituye a `floorLegs()`
  — insertos M3 ciegos en las mismas 4 posiciones donde antes había
  patas macizas integradas, para que `foot.scad` (pie desmontable,
  atornillado) tenga dónde anclarse. `foot.scad` ya hablaba de este
  módulo desde su creación, pero `floor.scad` nunca llegó a tenerlo
  — desajuste real entre dos ficheros pensados para encajar.

### Corregido

- `foot.scad`: `foot_height` de 6,0 a 4,0mm — con 6mm, la altura
  total montada (`shell_height` 148 + 6 = 154mm) superaba
  `case_height` (152, "dato original, sin modificar"). A 4mm
  (igual que `leg_height`) vuelve a dar exactamente 152mm.
- `walls.scad`, `topInsertPad()`/`topScrewInsertCuts()`: el usuario
  avisó de que los insertos M3 de la tapa quedaban desplazados hacia
  abajo respecto al borde superior real de la pared. La corrección de
  [entrada 2026-08-03] los frenaba `top_thickness` (3mm) de más, en la
  cara interior de la tapa en vez de en el borde real — pero la tapa
  es lisa, sin ningún reborde que aliviar (confirmado por el
  usuario): donde el relleno coincide en X/Y con la tapa, esta ya
  tiene su propio taladro de paso, no material macizo. El relleno
  ahora llega hasta el borde superior real de la pared
  (`shell_height`), sin necesitar ningún hueco de alivio en la tapa.

### Verificado (por separación de ejes, sin OpenSCAD en esta sesión — pendiente de confirmar con render/impresión real)

- Injerto suelo-pared sin colisión con: postes de pared existentes,
  ESP32/HUB (por separación en Y), pletinas del RC522.
- Patas (posición original, esquina) sin colisión con postes de
  bandeja — el resto de colisiones de las patas se detectó y corrigió
  en [1.5.3], con capturas reales del usuario.

---

## [1.5.1] - 2026-09-08 — Evaluado TeknoParrot vía Batocera-x86; descartado

### Decisión

- El usuario preguntó si el enfoque de un artículo de terceros
  (Batocera-x86 + wrapper Wine/DXVK/VKD3D curado por el equipo de
  Batocera para TeknoParrot) sería viable para el proyecto. Análisis:
  es la misma tecnología de traducción que ya se probó y se descartó
  vía Lutris ([1.4.4], DISPAROS ahora usa los remakes nativos de
  Steam de House of the Dead) — Batocera solo la tiene mejor
  empaquetada, no resuelve el problema de fondo, y además no es un
  paquete instalable suelto: adoptarlo implicaría sustituir Bazzite
  por Batocera-x86 como sistema operativo. Descartado — no hay
  ningún cambio de código. Documentado aquí para no repetir la
  evaluación más adelante.

---

## [1.5.0] - 2026-09-08 — Reconciliado: falta `auto_match` en steam.json/retro.json (AUTO no encontraba nada)

### Corregido

- El código de `Application`/`ProcessWatcher` ([1.4.6]) estaba
  completo y correcto, pero `software/config/profiles/steam.json` y
  `retro.json` nunca llegaron a tener el campo `"auto_match"` que esa
  misma entrada decía haber añadido — la tabla de coincidencias del
  perfil AUTO quedaba vacía en la práctica. Confirmado ejecutando la
  suite real (no solo leyendo el changelog): 1 test en rojo
  (`test_build_auto_match_table_reads_auto_match_from_loaded_profiles`).
  Añadido `"auto_match": ["steam"]` a steam.json y
  `"auto_match": ["retroarch", "retrodeck"]` a retro.json — 97/97
  tests en verde, coincide con el recuento de [1.4.7].

---

## [1.4.9] - 2026-09-08 — Reconciliado con un ZIP desactualizado: ventana OLED/mecanizado del panel inferior, canal LED; panel trasero nuevo del RC522

### Contexto

- El usuario subió un ZIP para retomar el proyecto en un hilo nuevo.
  `VERSION.md` decía v1.1.3, pero `CHANGELOG.md` incluía entradas
  hasta [1.4.8] — el código real de
  `openscad/parts/03_panels/lower_panel.scad` no tenía aplicado
  ninguno de los cambios de OLED de [1.2.2] a [1.3.0] (ventana,
  taladros M2, rebaje de pines, canal LED). Mismo patrón de desajuste
  que ya describe [1.3.2], repetido.

### Corregido (reconstruido a partir de las fórmulas ya documentadas en [1.2.2]-[1.3.0], sin inventar valores nuevos)

- `lower_panel.scad`: ventana OLED (26,0×15,0mm reales, antes
  14,5mm de alto), taladros M2 con separación horizontal/vertical
  distinta (23,0×23,5mm), posición de la ventana por fórmula
  (oled_window_z_offset=+2,25mm), bisel asimétrico (0,4mm arriba,
  2mm en los otros tres lados), rebaje de pines realineado a los
  taladros M2 fijos (profundidad 2,0mm), canal de la tira LED subido
  2mm.

### Añadido

- `openscad/parts/04_soportes/rc522_bracket.scad`,
  `rc522BracketBackdrop()`: petición del usuario (con foto) — el
  soporte del RC522 dejaba ver el interior del chasis (ventilador,
  cableado) por los huecos entre los brazos de la horquilla y
  alrededor de la cuna. Placa plana integrada en la misma pieza
  imprimible, justo detrás del lector, que cierra el resto de la
  abertura del panel NFC — verificado sin colisión por separación de
  ejes contra postes de pared, pletinas propias, ESP32/HUB y
  ventilador Noctua (sin OpenSCAD en esta sesión para confirmarlo con
  un render).

---

## [1.4.8] - 2026-09-04 — Anotado: el campo `icon` de panel_database.json no se usa todavía

### Documentado

- El usuario preguntó dónde se ubican los iconos referenciados por
  `"icon": "steam.png"` en `panel_database.json`. Respuesta: en
  ningún sitio — es un campo huérfano desde el principio del
  proyecto, sin ningún código que lo lea. `OLEDManager.show_logo()`
  ya tenía un `TODO` sobre esto (la OLED es solo texto, sin soporte
  de bitmaps en el protocolo del firmware) — no era un descuido nuevo,
  solo no estaba anotado en `docs/12_Profile_System.md`.
- Añadido a "Pendiente" en `docs/12_Profile_System.md`: para que
  `icon` sirva de algo hace falta (1) ampliar el protocolo del
  firmware para bitmaps 1-bit pequeños, y (2) crear una carpeta real
  de recursos (`software/resources/icons/` o similar) — ninguna de
  las dos existe hoy. Sin cambios de código en este turno.

---

## [1.4.7] - 2026-09-04 — Corregida la asignación real de UID a perfil; MAINTENANCE ya tiene panel físico

### Corregido

- El usuario confirmó la asignación real de sus tags NFC físicos, que
  resultó ser distinta de lo que [1.4.3]/[1.4.4] habían asumido:
  - `6739C003` → STEAM (sin cambios)
  - `E76DC103` → RETRO (sin cambios)
  - `112FC103` → **MAINTENANCE** (antes asignado por error a DISPAROS)
  - `56A1C003` → **DISPAROS** (antes retirado por error en [1.4.4],
    creyendo que era el panel de HOTD 2 Remake que ya no hacía falta)

### Cambiado

- `software/config/panel_database.json`: `112FC103` pasa de
  `"name": "Zombies"` / `profile: "DISPAROS"` a `"name": "Maintenance"`
  / `profile: "MAINTENANCE"` / `launcher: null`. Recuperado
  `56A1C003` con `"name": "Zombies"` / `profile: "DISPAROS"` /
  `launcher: "steam"` (la definición que antes tenía `112FC103`).
- `software/tests/test_panel_database.py`: actualizado el test de
  integridad que tenía la asignación anterior "grabada" — ahora
  comprueba explícitamente los 4 pares UID→perfil correctos, para
  detectar si esto se vuelve a desordenar en el futuro.
- `docs/12_Profile_System.md`: corregidas las menciones a UID
  concretos en el estado de DISPAROS y MAINTENANCE, y en "Decisiones
  cerradas" — MAINTENANCE ya no aparece como "sin panel físico
  asignado".
- 97 tests en total, todos en verde.

### Nota

- No he tocado el `CHANGELOG.md` de [1.4.3]/[1.4.4] — quedan como
  registro histórico de lo que se creía en su momento; esta entrada
  documenta la corrección, no reescribe lo anterior.

---

## [1.4.6] - 2026-09-04 — Perfil AUTO implementado: ProcessWatcher, cierra el alcance de la v0.2

### Añadido

- `software/core/process_watcher.py`: `ProcessWatcher` — vigila
  periódicamente (`psutil.process_iter(["name"])`, cada 5s por
  defecto) qué procesos corren, y avisa (callback) solo cuando el
  perfil detectado CAMBIA respecto a la última lectura (no en cada
  poll). Recibe una tabla ya construida (`{substring: profile_id}`),
  no decide el mapeo por sí mismo. `psutil` inyectable por
  constructor, mismo patrón que `SystemStatsProvider`, para poder
  testear con hilos reales pero procesos falsos (poll de 20ms en los
  tests, no 5s).
- Campo opcional `auto_match` en los perfiles: `steam.json` →
  `["steam"]`, `retro.json` → `["retroarch", "retrodeck"]`. `DISPAROS`
  y `MAINTENANCE` no lo llevan — ver limitaciones más abajo.
- `software/core/application.py`:
  - `_build_auto_match_table()`: arma la tabla plana a partir del
    `auto_match` de cada perfil cargado.
  - `_on_auto_profile_changed(profile_id)`: aplica el `oled.idle` /
    `led.idle` del perfil detectado (o pone la OLED en reposo si no
    hay nada relevante corriendo) — mismo mecanismo visual que un
    panel físico, sin tocar `self._pending_panel` (AUTO no lanza nada
    al pulsar el botón, solo informa).
  - `_on_tag_removed()`: arranca `ProcessWatcher` (entra en AUTO) —
    decisión de [1.3.3] finalmente implementada.
  - `_on_tag_detected()`: para `ProcessWatcher` en cuanto se detecta
    CUALQUIER panel físico, antes incluso de comprobar si el UID es
    válido — un panel físico manda siempre por encima de AUTO.
  - `initialize()`: crea el `ProcessWatcher` y lo arranca al final —
    AUTO es también el estado por defecto justo al arrancar, antes de
    que se coloque ningún panel.
  - `shutdown()`: para `ProcessWatcher` al cerrar, para no dejar el
    hilo de fondo colgado.
- 15 tests nuevos (96 en total, todos en verde):
  `test_process_watcher.py` (9 — coincidencia por subcadena, sin
  coincidencia, solo avisa en cambios, cambia de un perfil a otro,
  sin psutil, tabla vacía, `process_iter()` lanzando excepción,
  arranque/parada de hilo real con poll de 20ms, `start()`
  idempotente) + 6 de integración en `test_application.py`
  (`_on_tag_removed`/`_on_tag_detected` arrancan/paran el watcher;
  `_on_auto_profile_changed` con perfil real, con `None`, y con un id
  desconocido; `_build_auto_match_table` lee `auto_match` de los
  perfiles reales).
- `tests/fakes.py`: `FakeProcessWatcher`.

### Limitaciones conocidas (documentadas, no descuidos)

- **`DISPAROS` no participa en AUTO** — el proceso `steam` ya lo
  reclama `STEAM`, y la tabla de coincidencias es plana (un proceso
  solo puede apuntar a un perfil): mientras se juega a HOTD Remake/2,
  AUTO mostrará `STEAM`, no `DISPAROS`.
- **Nombres de proceso sin verificar contra el Bazzite real** —
  `retroarch`/`retrodeck` son un supuesto razonable dado que RetroDECK
  empaqueta RetroArch por debajo, pero no se ha comprobado todavía en
  la máquina física del usuario.
- **Sin debounce de arranque lento** — AUTO detecta un programa en
  cuanto su proceso aparece en la lista, ni un poll (hasta 5s) antes.

### Documentación

- `docs/12_Profile_System.md`: subido a versión 0.3 ("Implementado" —
  alcance completo de la v0.2 original en código: STEAM, RETRO,
  DISPAROS, MAINTENANCE y AUTO). Estado de AUTO actualizado con sus
  limitaciones; quitado de "Pendiente" el diseño de `ProcessWatcher`
  (ya resuelto), añadidos los puntos concretos que quedan abiertos.
- `software/README.md`: añadido `ProcessWatcher` a la estructura de
  `core/`.

---

## [1.4.5] - 2026-09-03 — Perfil MAINTENANCE migrado: primer StatusProvider real (CPU/RAM, foto fija)

### Añadido

- `software/status/` (paquete nuevo): `base_provider.py`
  (`BaseStatusProvider`, interfaz `snapshot() -> dict`),
  `system_stats_provider.py` (`SystemStatsProvider`, vía `psutil`,
  con `psutil` inyectable por constructor para poder testear sin
  depender de los sensores reales de la máquina), `status_manager.py`
  (`StatusManager`, registro `{"system_stats": SystemStatsProvider}`,
  mismo patrón que `Launcher`/`PLUGIN_CLASSES`).
- `software/config/profiles/maintenance.json`: `launcher: null`
  (perfil informativo, no lanza nada — a propósito), `oled.idle_template:
  ["CPU {cpu_temp}C RAM{ram_percent}%", "{ram_used_gb}/{ram_total_gb}GB"]`,
  `status_provider: "system_stats"`.
- `software/core/application.py`:
  - `_on_tag_detected()`: si el perfil tiene `oled.idle_template` +
    `status_provider`, se resuelve el snapshot vía `StatusManager` y
    se rellena la plantilla con `.format(**values)`; si falta alguna
    variable (`KeyError`/`IndexError`), se cae a `oled.idle` estático
    en vez de reventar. Retrocompatible con STEAM/RETRO/DISPAROS (sin
    `idle_template`, comportamiento idéntico a antes).
  - `_on_button()`: si el panel/perfil no tiene `launcher` (caso de
    MAINTENANCE), se ignora la pulsación sin animación de error —
    antes habría intentado `Launcher.launch(None)` y mostrado
    "error", dando a entender que algo había fallado.
  - Nuevo `self._status = StatusManager()`.
- `software/requirements.txt`: añadido `psutil`.
- 12 tests nuevos (81 en total, todos en verde):
  `test_system_stats_provider.py` (6 — snapshot sin psutil, lecturas
  correctas de CPU/RAM, fallo de sensor no revienta el resto),
  `test_status_manager.py` (3 — dispatch, provider desconocido,
  provider ausente), y 4 de integración en `test_application.py`
  (plantilla rellenada desde el provider; fallback a `oled.idle` si
  falta una variable; botón sin `launcher` no hace nada).
- `tests/fakes.py`: `FakeStatusManager`.

### Alcance deliberadamente recortado (no es un descuido)

- **Foto fija, no en vivo**: los valores se calculan una vez, al
  detectar el panel. El refresco periódico mientras el panel sigue
  puesto es una pieza aparte, sin implementar (ver "Pendiente").
- **Sin GPU ni FAN**: `psutil` no tiene una API genérica para ninguna
  de las dos en esta máquina — mejor "N/D" honesto que un dato
  inventado con una etiqueta que no le corresponde.
- **Sin fusionar el estado de `Application`** (conexión ESP32, último
  NFC...) — el `StatusProvider` de esta entrega solo aporta métricas
  de `psutil`.
- **Sin panel físico asignado**: no hay ningún UID en
  `panel_database.json` para MAINTENANCE todavía.

### Documentación

- `docs/12_Profile_System.md`: tabla de estado actualizada (MAINTENANCE
  migrado, con sus límites); sección "Perfiles con contenido en vivo"
  marca `system_stats` como implementado y `retroarch_network_commands`
  como pendiente; "Pendiente" reorganizado con los puntos concretos
  que deja abiertos este incremento.
- `software/README.md`: añadido `status/` a la estructura de carpetas.

---

## [1.4.4] - 2026-09-03 — Decisión: DISPAROS abre siempre Steam Big Picture; retirado el panel por-juego

### Decidido

- El botón del panel DISPAROS **siempre abre Steam Big Picture** —
  sin selector dentro del dispositivo. La lista real de juegos de
  disparos es una Colección de Steam que el usuario organiza a mano
  dentro del propio Steam, no un menú de este proyecto.
- Retirado el panel `56A1C003` (Zombies - HOTD 2 Remake): ya no hace
  falta un panel físico por juego, con el panel único de DISPAROS
  basta.

### Cambiado

- `software/config/panel_database.json`: eliminada la entrada
  `56A1C003`. El panel `112FC103` pasa a llamarse simplemente
  `"Zombies"` (antes "Zombies - HOTD Remake"), `launcher` cambia de
  `"hotd_remake"` a `"steam"`, `icon` a `"disparos.png"`.
- `software/config/profiles/disparos.json`: `launcher` cambia a
  `"steam"`; nuevos campos informativos `selector: "steam_collection"`
  y `selector_note` explicando la decisión. `games[]` se mantiene
  como catálogo de referencia (qué juegos se consideran parte de
  "Disparos"), pero ningún código lo lee todavía.
- `software/config/config.json`: `hotd_remake` y `hotd2_remake` se
  mantienen tal cual (siguen siendo `launcher` válidos por si se
  quieren lanzar directamente para pruebas), simplemente ya no los
  referencia ningún panel.
- Tests actualizados a la nueva realidad: el test que antes probaba
  "el botón lanza el juego propio del panel" se sustituye por
  `test_on_button_disparos_panel_always_opens_steam_big_picture`.
  Nuevo `test_default_database_disparos_panel_launches_steam_not_a_specific_game`
  en `test_panel_database.py`, que carga el `panel_database.json`
  real y comprueba tanto que `56A1C003` ya no existe como que
  `112FC103` lanza `"steam"` — para detectar si algún cambio futuro
  reintroduce por error el panel retirado. 69 tests en total, todos
  en verde.
- `docs/12_Profile_System.md`: el punto de "Pendiente" sobre el
  selector de DISPAROS se mueve a "Decisiones cerradas", con el
  razonamiento.

---

## [1.4.3] - 2026-09-03 — Perfil DISPAROS migrado (agrupa varios juegos, sin selector en el dispositivo todavía)

### Contexto

- El usuario pidió explícitamente: "un perfil que activará un único
  panel que debería dar acceso a los juegos de disparos que vayamos
  incluyendo en alguna especie de listado" — a diferencia de
  STEAM/RETRO (un perfil = un programa), DISPAROS agrupa varios
  juegos bajo la misma identidad.

### Añadido

- `software/config/profiles/disparos.json`: `led.idle`/`led.running`
  (`#FF3300`), `oled.idle: ["STEAM MACHINE", "DISPAROS"]`, y un campo
  nuevo `games[]` (catálogo: nombre + `launcher` de cada juego —
  hoy `hotd_remake` y `hotd2_remake`). El campo `launcher` a nivel de
  perfil (`"hotd_remake"`) queda tan inerte como el `running_template`
  de RETRO — `Application` sigue leyendo el `launcher` del PANEL, no
  el del perfil (ver "Sin cambios de código" más abajo).
- `software/config/panel_database.json`: los dos paneles Zombies
  (`112FC103` → HOTD Remake, `56A1C003` → HOTD 2 Remake) ganan
  `"profile": "DISPAROS"`. Su `launcher`/`led`/`icon` propios se
  mantienen sin tocar.
- 3 tests nuevos (68 en total, todos en verde):
  `test_default_profiles_directory_has_disparos_with_games_catalog`
  (valida el catálogo `games[]`), y dos de integración en
  `test_application.py` — uno confirma que la OLED muestra "DISPAROS"
  para un panel Zombies, y **el más importante**:
  `test_on_button_disparos_panel_launches_its_own_game_not_a_fixed_one`,
  que prueba explícitamente que pulsar el botón sigue lanzando el
  juego propio del panel insertado (`hotd2_remake` en ese caso), no
  un juego fijo del perfil — es la garantía de que unificar la OLED/
  LEDs bajo DISPAROS no ha cambiado qué juego se lanza.

### Sin cambios de código

- Igual que con RETRO: no ha hecho falta tocar `ProfileManager` ni
  `Application` — el mecanismo genérico de [1.4.0] ya cubre esto,
  precisamente porque `_on_button()` lee `panel["launcher"]` (del
  panel concreto), no del perfil. Eso es justo lo que hace que hoy
  "compartir perfil" sea seguro sin selector: cada panel sigue
  lanzando lo suyo.

### Pendiente (documentado en `docs/12_Profile_System.md`)

- El diseño real de "un único panel con una lista navegable" sigue
  sin resolver — necesita una decisión de UX de un solo botón (corta
  = siguiente, larga = lanzar; requiere ampliar el protocolo de
  `BUTTON` con duración) o, alternativa sin tocar firmware, apoyarse
  en una Colección de Steam organizada a mano. También queda abierto
  si retirar el panel `56A1C003` ahora que la intención es un panel
  único, o dejarlo como segunda entrada mientras no haya selector.

---

## [1.4.2] - 2026-09-03 — Perfil RETRO migrado (segundo perfil, mismo mecanismo genérico)

### Añadido

- `software/config/profiles/retro.json`: `launcher: "retrodeck"`,
  `led.idle`/`led.running` (`#8800FF`), `oled.idle: ["STEAM MACHINE",
  "RETRO"]`. Incluye también `oled.running_template` y
  `status_provider: "retroarch_network_commands"` del esquema de
  `docs/12_Profile_System.md`, pero **de momento quedan inertes** —
  `Application` todavía no lee ninguno de los dos campos (no hay
  `StatusProvider` implementado). Se dejan ya en el JSON para no
  tener que volver a tocar el fichero cuando se implemente.
- `software/config/panel_database.json`: panel RetroDECK (`E76DC103`)
  gana el campo `"profile": "RETRO"`. `launcher`/`led`/`icon` se
  mantienen igual.
- 2 tests nuevos: `test_default_profiles_directory_has_steam_and_retro`
  (carga la carpeta real `config/profiles/` y valida launcher + límite
  de 2 líneas en `oled.idle` de ambos perfiles, para detectar erratas
  sin necesidad de arrancar `Application`) y
  `test_on_tag_detected_retro_panel_shows_profile_idle_lines` (mismo
  mecanismo genérico que STEAM, verificado con un segundo perfil real
  en vez de asumir que "si funcionó una vez, funciona siempre"). 65
  tests en total, todos en verde.
- `docs/12_Profile_System.md`: añadida una tabla de estado de
  implementación en "Alcance propuesto para v0.2" (STEAM y RETRO
  migrados; DISPAROS, MAINTENANCE, AUTO pendientes).

### Sin cambios de código

- No ha hecho falta tocar `ProfileManager` ni `Application` —
  el mecanismo genérico de [1.4.0] (leer `oled.idle` cuando el panel
  tiene `profile`, retrocompatible si no lo tiene) ya cubre RETRO sin
  ninguna rama de código nueva. Es la señal de que el diseño de
  [1.4.0] estaba bien planteado: añadir un perfil "estático" es
  añadir un fichero, no tocar Python.

---

## [1.4.1] - 2026-09-03 — Decisión: sin animación de lanzamiento configurable por perfil

### Decidido

- El usuario eligió la opción B de las dos planteadas: no conectar
  `led.launch_animation` a `_on_button()`. La animación de lanzamiento
  se queda fija en `"launch"` para todos los perfiles, igual que
  antes de que existiera `ProfileManager`.

### Cambiado

- `software/config/profiles/steam.json`: eliminado el campo
  `led.launch_animation` (quedaba sin usar — `_on_button()` nunca
  llegó a leerlo).
- `docs/12_Profile_System.md`: quitado `launch_animation` del ejemplo
  de esquema y de su explicación; nueva sección "Decisiones cerradas"
  con el porqué (evitar complejidad sin necesidad real mientras todos
  los perfiles compartan la misma animación) y con la decisión de
  AUTO de [1.3.3] (que ya estaba resuelta pero seguía listada por
  error en "Pendiente" — corregido de paso).
- 63 tests siguen en verde (el campo no estaba conectado a ningún
  test, cambio sin impacto funcional).

---

## [1.4.0] - 2026-09-03 — Implementado ProfileManager (primer paso del sistema de perfiles, `docs/12_Profile_System.md`)

### Añadido

- `software/core/profile_manager.py`: `ProfileManager` — carga cada
  `.json` de `software/config/profiles/` (id = campo `"id"` del propio
  fichero, o el nombre de fichero si falta), y expone `get(profile_id)`
  / `all()`. Sigue el mismo patrón que `PanelDatabase` (carga desde
  disco en `load()`, tolera fichero/carpeta ausente o JSON mal
  formado sin reventar).
- `software/config/profiles/steam.json`: primer perfil migrado al
  nuevo esquema — `launcher: "steam"`, `led.idle`/`led.running`
  (`#0055FF`), `led.launch_animation: "launch"`, `oled.idle: ["STEAM
  MACHINE", "Steam"]` (2 líneas, dentro del límite real del firmware).
- `software/config/panel_database.json`: panel Steam (`6739C003`)
  gana el campo `"profile": "STEAM"`. `launcher`/`led`/`icon` se
  mantienen tal cual — el resto de paneles (RetroDECK, Zombies x2) se
  quedan sin `"profile"` por ahora, sin cambios en su comportamiento.
- `software/core/application.py`, `_on_tag_detected()`: si el panel
  tiene `"profile"` y `ProfileManager` lo resuelve, la OLED muestra
  `oled.idle` del perfil (1 o 2 líneas) en vez de `panel["name"]`. Si
  el panel no tiene `"profile"`, o el id no resuelve a ningún perfil
  cargado, el comportamiento es **exactamente el de antes** —
  retrocompatibilidad verificada con test dedicado.
- 10 tests nuevos en `software/tests/test_profile_manager.py`
  (carga, fichero/carpeta ausente, JSON malformado, `id` por nombre de
  fichero, copia defensiva de `all()`) + 2 en `test_application.py`
  (panel con perfil muestra `oled.idle`; panel con `profile` desconocido
  cae al comportamiento antiguo). 63 tests en total, todos en verde.

### Alcance de este paso

- Solo `STEAM` está migrado — es el perfil más simple del catálogo de
  `docs/12_Profile_System.md` (sin `status_provider`, sin animación de
  "running" distinta de la de reposo), elegido a propósito para
  validar el mecanismo antes de añadir `RETRO`, `DISPAROS` y
  `MAINTENANCE`.
- `_on_button()` no se ha tocado — sigue lanzando `panel["launcher"]`
  igual que siempre; conectar `led.launch_animation` del perfil ahí
  queda para el siguiente incremento.
- `ProcessWatcher` y los `StatusProvider` (RetroArch, sistema) siguen
  sin implementar — no hacían falta para este primer perfil.

### Pendiente

- Migrar `RetroDECK` → perfil `RETRO`, y los dos paneles Zombies →
  perfil `DISPAROS` (con `led`/`icon` como override por panel, según
  el esquema del documento de diseño).
- Perfil `MAINTENANCE` (necesita el `StatusProvider` de sistema antes
  de tener sentido).
- Decidir si `led.launch_animation` del perfil sustituye a la
  animación `"launch"` fija que usa hoy `_on_button()`.

---

## [1.3.3] - 2026-09-03 — Decisión: AUTO se activa sin panel puesto, no como panel propio

### Decidido

- El usuario resolvió el punto abierto de `docs/12_Profile_System.md`:
  AUTO se activa cuando no hay ningún panel físico insertado — no es
  un perfil seleccionable por su propio tag NFC.

### Cambiado

- `docs/12_Profile_System.md`: sección "Precedencia NFC físico vs.
  perfil AUTO" actualizada de "a decidir" a regla firme; añadida
  subsección "Implicación en `core/application.py`":
  `_on_tag_removed()` pasa de solo apagar/reposar a arrancar el
  `ProcessWatcher` (entra en AUTO); `_on_tag_detected()` debe pararlo
  al detectar un panel físico. Sin clave nueva en
  `panel_database.json` para AUTO.
- Documento subido a versión 0.2 (queda un único punto de diseño
  resuelto; el resto — `ProcessWatcher`, los `StatusProvider`, la
  ampliación de la OLED a más líneas — sigue pendiente de
  implementar).

---

## [1.3.2] - 2026-09-03 — Reconciliado con el zip subido por el usuario: UIDs reales conservados, correcciones OLED restauradas

### Contexto

- El usuario subió `SteamMachine-UM790-main__3_.zip` "por si no tenías
  toda la información actualizada". Comparado con el estado de
  trabajo de esta sesión, resultó tener contenido en ambas
  direcciones: cosas más nuevas que yo no tenía, y cosas más viejas
  que sobrescribían correcciones ya hechas hoy.

### Encontrado en el zip del usuario (más nuevo que mi copia — conservado tal cual)

- `software/config/panel_database.json`: los 3 UID de ejemplo/
  placeholder (`04B2D9C3`, `04C3EAD4`, `0AAABBCC`) sustituidos por los
  UID reales de los tags NFC del usuario (`E76DC103`, `112FC103`,
  `56A1C003`) — mismos nombres/launcher/led/icon, solo cambian las
  claves. Conservado sin tocar.
- Carpeta `obsoletos/` (creada 2026-08-14 según su propio README, antes
  de esta sesión): agrupa ficheros `.scad` ya sin uso
  (`front_panel.scad`, `front_layout.scad`, `rc522_bracket_v1.scad`,
  `virtual_assembly_v1.scad`, `front_panel_view.scad`,
  `chassis_layout.scad`, `um790_reference.scad`), verificados sin
  referencias entrantes antes de moverlos. Conservada.
- `VERSION.md` y carpeta `G-Code/` (con `lower_panel.gcode`).
  Conservados.
- Piezas de chasis nuevas sin documentar en este CHANGELOG hasta
  ahora: `openscad/parts/02_chassis/floor_flat.scad`, `foot.scad`,
  `leftwall_flat.scad`, `rightwall_flat.scad`,
  `openscad/parts/04_soportes/foot.scad`, y
  `STL/rear_panel_horizontal.stl` + STL sueltos
  (`floor_flat (1).stl`, `foot.stl`, `leftwall_flat.stl`,
  `rightwall_flat.stl`). Conservados tal cual — no hay contexto en
  este historial sobre su propósito o si vienen de otra sesión; sin
  inventar una entrada de motivo, pendiente de que el usuario lo
  aclare si quiere que se documenten.

### Encontrado en el zip del usuario (más viejo que mi copia — restaurado desde esta sesión)

- `openscad/parts/03_panels/lower_panel.scad`: el zip subido no tenía
  ninguna de las correcciones de OLED de [1.2.2] a [1.3.0] de esta
  misma sesión (ventana acoplada a los taladros M2 en vez de
  desacoplada, rebaje de pines en la cara exterior en vez de la
  interior, medidas de pantalla/separación de taladros sin la
  medición real por calibre, sin el offset del canal LED). Restaurado
  el fichero de esta sesión, que sí incluye todo lo anterior.
- `openscad/reference/components/assembly_positions.scad`: mismo
  contenido salvo el comentario explicativo del desacoplamiento de
  [1.2.9], que faltaba. Restaurado.
- `STL/lower_panel.stl`, `openscad/parts/03_panels/oled_bracket.stl`,
  `STL/probetas/probeta_pines_oled.stl`: regenerados desde el
  `lower_panel.scad` restaurado.
- Añadidos también `openscad/parts/03_panels/nfc_panel_zombies.scad` y
  `STL/nfc_panel_zombies_tumbado.stl` ([1.2.7]), que no estaban en el
  zip subido.

### Verificado

- `openscad/parts/03_panels/lower_panel.scad` renderiza sin errores
  (817 facetas, igual que la versión de esta sesión).
- Los 53 tests de `software/tests/` pasan.
- `panel_database.json`, `config.json`, `launcher.py` y los plugins de
  `software/launcher/` ya coincidían entre ambas copias — sin cambios.

---

## [1.3.1] - 2026-08-30 — Documento de diseño: sistema de perfiles (panel = perfil, no solo panel = programa)

### Añadido

- `docs/12_Profile_System.md`: propuesta de diseño para generalizar
  los paneles NFC de "panel = programa" (`launcher` directo) a
  "panel = perfil" (app + comportamiento de OLED + LEDs, con un
  perfil `AUTO` que detecta qué corre en Bazzite cuando no hay panel
  físico dedicado puesto). Basada en una propuesta del usuario, con
  tres correcciones respecto al planteamiento original:
  1. Regla de precedencia explícita entre panel físico y AUTO (el
     panel físico manda siempre; AUTO solo actúa como panel propio).
  2. Señalado que el protocolo OLED actual solo admite 2 líneas
     (`OLEDManager.show_status`), no las 5 líneas de los mockups
     originales — el motor de plantillas de la v0.2 trabaja con listas
     de 2 elementos; ampliar el firmware queda anotado como tarea
     aparte.
  3. Separados como componentes `StatusProvider` futuros (no incluidos
     en esta entrega) la integración con RetroArch Network Commands
     (UDP 55355, para nombre de juego + tiempo en RETRO) y las
     métricas de sistema (CPU/GPU/RAM, para MAINTENANCE).
- Esquema de datos propuesto: `software/config/profiles/*.json` (un
  fichero por perfil) + campo opcional `profile` en
  `panel_database.json`, retrocompatible con los paneles que ya usan
  `launcher` directo.
- Alcance v0.2 acotado a `STEAM · RETRO · DISPAROS · MAINTENANCE ·
  AUTO` (con contenido de OLED definido); `KODI · MUSIC · DESKTOP ·
  NIGHT · DEMO` quedan como huecos reservados en el esquema, sin
  diseñar su pantalla todavía.
- `DISPAROS` se documenta como el mismo concepto que el panel Zombies
  ya existente (`hotd_remake`/`hotd2_remake`), no un nombre nuevo.

### Pendiente

- Todo el documento es una propuesta sin implementar — ver su propia
  sección "Pendiente" para el desglose (`ProcessWatcher`, los dos
  `StatusProvider`, y la decisión final sobre cuándo se activa AUTO).

---

## [1.3.0] - 2026-08-30 — Recalculado con medidas reales del módulo OLED: ventana, taladros M2 y rebaje de pines

### Encontrado

- Con foto de la impresión real, el usuario mostró la ventana
  invadiendo el taladro M2 inferior ("¿No te parece que esto es una
  chapuza?"). Confirmado por cálculo: el offset -4,0 de [1.2.8] hacía
  que el corte recto de la ventana se solapara 0,85mm con el taladro
  inferior, y el bisel 2,85mm.
- El usuario decidió medir el módulo físico con calibre en vez de
  seguir ajustando a ciegas — decisión correcta, ya que reveló que el
  diseño llevaba varias suposiciones sin verificar.

### Medidas reales (calibre, módulo instalado en la carcasa, pines hacia arriba)

- Separación horizontal entre los 2 taladros M2 superiores: 23,0mm
  (igual que se venía usando).
- Separación VERTICAL entre taladro superior e inferior del mismo
  lado: 23,5mm (antes se asumía igual que la horizontal, 23,0 — no es
  un cuadrado exacto).
- Pantalla: 26 x 15mm (ancho ya correcto; alto corregido de 14,5 a
  15,0).
- Del centro del taladro superior al borde superior de la pantalla:
  2,0mm — la medida clave que faltaba.
- Pines de soldadura: sobresalen 2,0mm por detrás de la placa (antes
  se estimaba 1,5mm, insuficiente — no habrían cabido).

### Causa raíz del zigzag de las rondas anteriores

- Antes de [1.2.9], `oled_pos` movía a la vez los taladros M2 Y la
  ventana — cualquier feedback visual del usuario sobre "la pantalla"
  en realidad comparaba la ventana contra el botón/USB del panel, no
  contra los taladros de la propia OLED (imposible verlo por
  separado hasta que se desacoplaron). Por eso el offset empírico
  (-4,0) apuntaba en la dirección contraria a la que da el cálculo
  con datos reales (+2,25).

### Cambiado

- `openscad/parts/03_panels/lower_panel.scad`:
  - `oled_mount_spacing` dividida en `oled_mount_spacing_x` (23,0) y
    `oled_mount_spacing_z` (23,5) — ya no se asume un cuadrado.
  - `oled_screen_height`: 14,5 → 15,0.
  - `oled_gap_top_hole_to_screen = 2.0` (nueva constante, medida
    real).
  - `oled_window_z_offset` ahora se calcula con fórmula
    (`oled_mount_spacing_z/2 - oled_gap_top_hole_to_screen -
    oled_screen_height/2` = +2,25) en vez de un número fijo ajustado
    a mano.
  - `oled_pin_clearance_pocket_depth`: 1,5 → 2,0 (medida real; con el
    valor anterior los pines no habrían cabido).
  - Bisel de la ventana ahora asimétrico: `oled_bevel_margin_top =
    0.4` (reducido, solo en el borde superior, para no invadir el
    taladro con solo 2mm de holgura real) vs `oled_bevel_margin = 2.0`
    en los otros tres lados.
  - `oledMountHoles()` actualizado para usar `oled_mount_spacing_x`/
    `_z` por separado en vez de la variable única.
- Verificado por render (vista frontal + zoom a la zona superior):
  los 4 taladros M2 aparecen limpios alrededor de la ventana, sin
  solape con el bisel ni con el corte recto.
- Regenerados y sustituidos `STL/lower_panel.stl`,
  `openscad/parts/03_panels/oled_bracket.stl` y
  `STL/probetas/probeta_pines_oled.stl`.

### Pendiente

- Nueva impresión de prueba — primera vez que la posición de la
  ventana se calcula a partir de medidas reales en vez de prueba y
  error, así que hay bastante confianza, pero toca confirmarlo en
  mano.
- El margen de bisel superior (0,4mm) es deliberadamente pequeño para
  garantizar que no toque el taladro; visualmente será un chaflán
  casi plano en ese borde, distinto de los otros tres lados — si no
  gusta el resultado, se puede ajustar una vez impreso.

---

## [1.2.9] - 2026-08-30 — Desacoplada la ventana OLED de los taladros M2: eran fijos y no debían moverse

### Encontrado

- Con foto de la impresión real, el usuario señaló dos círculos junto
  al hueco de la pantalla que parecían haberse movido, pese a haber
  pedido explícitamente no tocar tornillos. Comparando renders, se
  identificaron como los 4 taladros M2 propios de la placa OLED
  (`oledMountHoles()`), no los M3 del panel contra la pared (esos
  seguían intactos, verificado de nuevo). El usuario confirmó: "sí,
  me refiero a los del propio OLED de métrica 2".

### Causa raíz

- Desde [1.2.2], `oled_pos` se usaba como referencia única tanto para
  los taladros M2 (fijos, correctos desde el principio) como para la
  ventana visible de la pantalla (la que el usuario pedía mover). Al
  desplazar `oled_pos` para bajar la ventana, arrastraba también los
  taladros M2 — que en el módulo OLED real NO se mueven, porque son
  la fijación física de la placa; lo que está descentrado es el área
  visible de la pantalla dentro de esa placa.

### Corregido

- `openscad/reference/components/assembly_positions.scad`:
  `oled_pos` vuelve a su posición original (sin ningún offset) — pasa
  a representar solo la placa/taladros M2/brida, que ya estaban bien
  y no se tocan más.
- `openscad/parts/03_panels/lower_panel.scad`, `oledCut()`: nuevo
  `oled_window_z_offset = -4.0`, aplicado SOLO a la ventana visible
  (el bisel y el hueco recto), no al resto. El rebaje de pines sigue
  centrado en los taladros M2 (ahora fijos de nuevo), sin cambios en
  su fórmula.
- Verificado con `echo()`: `oled_pos` = Z 19 (taladros M2 en 7,5 /
  30,5mm, igual que antes de [1.2.2]); taladros M3 del panel sin
  cambios (7 / 26,5mm); ventana ahora en Z=15 (los -4mm pedidos por
  el usuario, aplicados solo a ella).
- Regenerados y sustituidos `STL/lower_panel.stl`,
  `openscad/parts/03_panels/oled_bracket.stl` y
  `STL/probetas/probeta_pines_oled.stl` (recorte ampliado para cubrir
  desde los taladros M2 hasta la ventana, ahora más separadas).

### Pendiente

- Nueva impresión de prueba para confirmar que ahora sí encaja todo
  correctamente: taladros M2 fijos + ventana 4mm más abajo.

---

## [1.2.8] - 2026-08-30 — Ventana OLED: 2mm adicionales hacia abajo (total -4mm)

### Encontrado

- Tras imprimir el panel inferior con el ajuste de [1.2.2] (-2mm),
  el usuario reportó: "la pantalla sigue quedando dos milímetros
  alta. Los orificios de los tornillos están correctamente
  ubicados, pero el rectángulo de la pantalla debería bajar dos
  milímetros [más]".

### Cambiado

- `openscad/reference/components/assembly_positions.scad`:
  `oled_z_offset` de `-2.0` a `-4.0` (total acumulado desde la
  posición original de antes de [1.2.2]). Confirmado por `echo()`
  que los taladros de tornillo siguen exactamente en 7 / 26,5mm, sin
  cambios — coincide con lo que el usuario validó ("correctamente
  ubicados").
- El rebaje de pines y los bosses de la brida (`oled_bracket.scad`)
  se recalculan solos a partir de `oled_pos`, así que bajan con la
  pantalla automáticamente, manteniéndose alineados entre sí.
- Regenerados y sustituidos `STL/lower_panel.stl`,
  `openscad/parts/03_panels/oled_bracket.stl` y
  `STL/probetas/probeta_pines_oled.stl`.

### Pendiente

- Nueva impresión de prueba para confirmar que -4mm es ya la
  posición correcta.

---

## [1.2.7] - 2026-08-30 — Nuevo panel NFC "Zombies": base en blanco + anagrama Gung, listo para imprimir tumbado

### Añadido

- `openscad/parts/03_panels/nfc_panel_zombies.scad`: nuevo panel NFC
  del tema Zombies, siguiendo el mismo patrón que
  `nfc_panel_Steam.scad` / `nfc_panel_retrobat.scad` (base compartida
  de `nfc_panel.scad` + anagrama), con una diferencia: el anagrama no
  es geometría 2D generada en OpenSCAD, es el STL ya modelado por el
  usuario (`STL/Anagramas/Gung.stl`), importado y centrado.
  - `nfcPanelZombies()`: base + anagrama en coordenadas globales del
    caso (para previsualización/renders de galería, mismo criterio
    que los paneles hermanos).
  - `nfcPanelZombiesPrintable()`: el mismo conjunto rotado -90° sobre
    X, para que el eje fino del panel (el grosor) quede en Z — lista
    para laminar e imprimir tumbada directamente, sin reorientar nada
    a mano.
- `STL/nfc_panel_zombies_tumbado.stl`: exportado desde
  `nfcPanelZombiesPrintable()`. Verificado por bounding box: huella
  149 x 94,5mm, solo 5mm de alto — confirmado que queda tumbado.
- Verificado visualmente por render que el anagrama Gung queda
  centrado y con la orientación correcta (sin espejarse ni girarse)
  sobre la base.

### Nota

- `STL/Anagramas/Gung.stl` (el anagrama suelto, para el flujo de
  impresión en dos piezas + Loctite de [1.2.1]) no se ha tocado — este
  panel combinado es una pieza única alternativa, útil para
  previsualización o para imprimir de una sola vez si en algún
  momento no se quiere pegar con Loctite.

---

## [1.2.6] - 2026-08-30 — Galería: renders de la carcasa montada con distintos anagramas

### Añadido

- 3 renders nuevos de la carcasa **completa montada** (chasis + tapa
  superior + panel inferior + panel trasero + bandeja + panel NFC),
  cada uno con un anagrama de panel NFC distinto: Steam, RetroBat y
  en blanco. Todas las piezas ya estaban definidas en el mismo
  sistema de coordenadas global (`assembly_positions.scad`), así que
  el ensamblaje es una simple unión de los módulos de cada pieza sin
  necesidad de calcular ninguna posición nueva.
- Ficheros: `docs/img/render_ensamblaje_steam.png`,
  `render_ensamblaje_retrobat.png`, `render_ensamblaje_blank.png`.
- `README.md`: nueva sección "Carcasa montada, con distintos
  anagramas de panel NFC" en la galería, antes de las piezas sueltas.

### Nota

- El anagrama del panel Zombies (`STL/Anagramas/Gung.stl`) no tiene
  todavía un `.scad` paramétrico propio (como sí tienen Steam,
  RetroBat y TeknoParrot) — está modelado como STL suelto en
  coordenadas de su propia mesa de impresión, no en las coordenadas
  globales del proyecto. Por eso no se ha podido incluir en el
  render conjunto sin arriesgarse a una posición incorrecta. Si se
  quiere en la galería, habría que crear
  `openscad/parts/03_panels/nfc_panel_zombies.scad` a partir del
  logo, siguiendo el mismo patrón que `nfc_panel_retrobat.scad`.

---

## [1.2.5] - 2026-08-30 — Galería del README con renders reales del diseño actual

### Cambiado

- `README.md`: sustituida la imagen genérica de la galería (mockup
  subido a GitHub, sin relación directa con el CAD del proyecto) por
  5 renders generados directamente desde los ficheros OpenSCAD
  actuales — chasis, panel superior, panel inferior (ya con los
  ajustes de [1.2.2]-[1.2.4]), panel trasero y bandeja interior.
- Nuevos ficheros en `docs/img/`: `render_chasis.png`,
  `render_panel_superior.png`, `render_panel_inferior.png`,
  `render_panel_trasero.png`, `render_bandeja.png`. Generados con
  `openscad --imgsize=900,700 --camera=0,0,0,55,0,35,0` sobre cada
  `.scad` de pieza, usando su propio bloque `// PREVIEW` — se pueden
  regenerar en cualquier momento con el mismo comando si el diseño
  cambia.

---

## [1.2.4] - 2026-08-29 — Rebaje de pines OLED realineado a sus orificios de sujeción reales + probeta de comprobación

### Encontrado

- Tras [1.2.3], el usuario avisó: "el rebaje para los pines del OLED
  aun tienen que subir hasta estar centrados verticalmente con los
  orificios superiores de sujeción" — [1.2.3] lo había alineado con
  `lower_panel_hole_z_high` (26,5mm), que son los taladros M3 del
  panel contra la pared, no los "orificios de sujeción" a los que se
  refería. Los orificios de sujeción reales son el par superior de
  los 4 taladros M2 de `oledMountHoles()` (fijación de la propia
  placa OLED), a Z = 28,5mm — 2mm más arriba, coincide con "aun
  tienen que subir".

### Corregido

- `openscad/parts/03_panels/lower_panel.scad`, `oledCut()`: el rebaje
  de pines se centra ahora en `oled_pos[2] + oled_mount_spacing/2`
  (28,5mm) en vez de `lower_panel_hole_z_high` (26,5mm).
- Regenerado y sustituido `STL/lower_panel.stl`.

### Añadido

- `STL/probetas/probeta_pines_oled.stl`: probeta de comprobación —
  recorte pequeño y fino (32 x 3 x 10,25mm) del panel inferior,
  limitado a la zona del rebaje de pines + orificios superiores de
  sujeción del OLED, pensada para imprimir tumbada sobre la cama
  (rápida, sin gastar tiempo/material en el panel completo). Generada
  por intersección de `lowerPanel()` con una caja de recorte
  paramétrica en `oled_pos[0]`, sin tocar el fichero fuente
  `lower_panel.scad`.

### Nota técnica (revisar en algún momento, no bloqueante hoy)

- Se ha detectado que `oled_screen_width/height` está definido dos
  veces con valores distintos: en `assembly_positions.scad` (27,0 x
  20,0mm, usado por `oled_bracket.scad`) y localmente en
  `lower_panel.scad` (26,0 x 14,5mm, el que realmente usa `oledCut()`
  al ser la última asignación en el `include`). No afecta a los
  cambios de hoy, pero conviene unificarlo para que la brida
  (`oled_bracket.scad`) y la ventana (`lower_panel.scad`) usen
  siempre la misma medida.

---

## [1.2.3] - 2026-08-29 — Corregido: rebaje de pines en la cara equivocada; confirmado que los tornillos no se movieron

### Encontrado

- El usuario avisó, tras revisar el cambio de [1.2.2]: "has vuelto a
  poner el rebaje para los pines por fuera en lugar de por dentro" y
  "has bajado los orificios para los tornillos... tienes que
  devolverlos a su posición original".

### Comprobado

- Los taladros de tornillo (`lower_panel_hole_z_low/high`,
  `lower_panel_screw_z_low/high`) **no se han movido**: sus fórmulas
  dependen de `front_panel_lower_top` → `front_panel_cluster_z_high`
  → `front_cluster_z`, ninguna de las cuales usa `oled_pos` ni el
  rebaje de pines. Verificado numéricamente con `echo()` en OpenSCAD:
  `lower_panel_hole_z_low = 7`, `lower_panel_hole_z_high = 26.5`,
  `lower_panel_screw_z_low = 10`, `lower_panel_screw_z_high = 29.5` —
  mismos valores antes y después de [1.2.2]. No ha hecho falta
  ningún cambio de código en `lowerPanelScrewHoles()`.

### Corregido

- `openscad/parts/03_panels/lower_panel.scad`, `oledCut()` (rebaje de
  pines): el cubo arrancaba en la cara EXTERIOR del panel
  (`-case_depth/2`, la misma cara donde empieza el propio panel) y
  cortaba hacia dentro — dejaba el hueco abierto por fuera (donde se
  ve la pantalla) y cerrado justo donde están los pines (la cara
  interior). Invertido: ahora arranca cerca de la cara interior
  (`-case_depth/2 + front_panel_thickness - oled_pin_clearance_pocket_depth`)
  y corta hacia el interior, dejando la piel sólida en la cara
  exterior (donde no se nota) y el hueco abierto hacia el interior,
  donde sobresalen los pines.
- Regenerado y sustituido `STL/lower_panel.stl` (OpenSCAD 2021.01,
  sin warnings ni errores).

### Pendiente

- Nueva impresión de prueba para confirmar que el rebaje de pines
  encaja bien desde la cara interior antes de dar el panel por
  definitivo.

---

## [1.2.2] - 2026-08-29 — Ajustes del panel inferior tras la primera impresión real

### Encontrado

- Tras imprimir y montar el panel inferior real, el usuario reportó
  tres desajustes respecto al hardware:
  1. El hueco rectangular de la pantalla OLED queda 2mm demasiado
     alto.
  2. El rebaje ciego para los pines de soldadura de la OLED debería
     estar arriba del todo del panel, alineado con los orificios de
     los tornillos superiores — no siguiendo la posición de la
     pantalla como hasta ahora.
  3. El soporte/canal de la tira LED debería subir 2mm.
- Los taladros de tornillo (`lower_panel_hole_z_low/high`,
  compartidos con los insertos ya impresos en la pared) se mantienen
  sin tocar, tal y como pidió el usuario.

### Cambiado

- `openscad/reference/components/assembly_positions.scad`: nuevo
  `oled_z_offset = -2.0`, aplicado a `oled_pos[2]` — baja la ventana
  OLED 2mm sin mover nada más (los bosses de `oled_bracket_screw_positions`
  se recalculan solos a partir de `oled_pos`, así que se mueven con
  ella automáticamente).
- `openscad/parts/03_panels/lower_panel.scad`, `oledCut()`: el rebaje
  de los pines de soldadura ya no se calcula a partir de
  `oled_pos[2] + oled_screen_height/2` — ahora se centra en
  `lower_panel_hole_z_high` (misma Z que los taladros de tornillo
  superiores).
- `openscad/parts/03_panels/lower_panel.scad`, `ledChannelWalls()`:
  nuevo `led_channel_z_offset = 2.0`, sumado a `channelZ` — sube el
  canal/soporte de la tira LED 2mm.
- Regenerados y sustituidos `STL/lower_panel.stl` y
  `openscad/parts/03_panels/oled_bracket.stl` con los cambios
  aplicados (renderizado con OpenSCAD 2021.01, sin warnings ni
  errores).

### Pendiente

- Confirmar con una nueva impresión de prueba que los tres ajustes
  encajan correctamente antes de dar el panel inferior por definitivo.

---

## [1.2.1] - 2026-08-29 — Paneles NFC: impresión en dos piezas (base + anagrama pegado con Loctite)

### Cambiado

- Los STL de los paneles NFC con anagrama pasan de imprimirse como
  pieza única (base + emblema en relieve integrado) a imprimirse en
  dos piezas independientes: `STL/Anagramas/nfc_panel_blank.stl` (la
  base, común a todos los temas) y un STL suelto por anagrama
  (`Steam.stl`, `Retrobat.stl`, `Parrot.stl`, `engranaje.stl`,
  `Gung.stl`), que se pegan después con Loctite (cianoacrilato tipo
  401/454, compatible con PLA/PETG).
- Motivo: baja el tiempo de impresión de ~6h (pieza única con el
  relieve del emblema) a ~1h por panel.
- Documentado en `GUIA_INICIO.md` (paso 1, lista de materiales) y
  `docs/11_Assembly_Manual.md` (Paso 11, Panel NFC).
- Los STL de bloque único (con el emblema ya integrado) se mantienen
  en `STL/` y `openscad/parts/03_panels/` para quien prefiera esa vía.

### Confirmado

- `Gung.stl` es el anagrama del panel Zombies (04C3EAD4 / hotd_remake).

---

## [1.2.0] - 2026-08-28 — Panel TeknoParrot sustituido por panel Zombies (Steam nativo) + soporte RetroArch

### Contexto

- TeknoParrot tiene mala compatibilidad con Linux/Bazzite (depende de
  Wine + Demulshooter, poco fiable). Se decidió sustituir el panel de
  recreativas por un panel de disparos/zombies usando juegos nativos
  de Steam en vez de emulación, pensado para jugarse con Wiimote como
  pistola (Bluetooth + barra de sensor IR, integración pospuesta a más
  adelante).

### Añadido

- `software/launcher/hotd_remake_plugin.py` y
  `hotd2_remake_plugin.py`: lanzan THE HOUSE OF THE DEAD: Remake
  (AppID Steam `1694600`) y THE HOUSE OF THE DEAD 2: Remake (AppID
  `3376690`) via `steam://rungameid/`. Juegos nativos, sin BIOS ni
  cores.
- `software/launcher/retroarch_plugin.py`: lanza RetroArch (Flatpak
  `org.libretro.RetroArch`) directamente, sin pasar por RetroDECK.
  Instalado y validado en este ciclo con los núcleos Flycast, Beetle
  Saturn, PCSX-ReARMed y MAME2003-Plus.
- `config/panel_database.json`: panel `04C3EAD4` renombrado a
  "Zombies - HOTD Remake" (launcher `hotd_remake`); nuevo panel
  `0AAABBCC` "Zombies - HOTD 2 Remake" (launcher `hotd2_remake`) —
  UID placeholder pendiente de un segundo tag físico real.
- `config/config.json`: nuevas plataformas `retroarch`, `hotd_remake`,
  `hotd2_remake`.
- Documentación de instalación de RetroArch (Flatpak, actualización de
  información de núcleos, descarga de núcleos, ubicación de BIOS/ROMs)
  añadida en `GUIA_INICIO.md`, incluyendo el fallo conocido "No hay
  elementos disponibles" en el Descargador de núcleos y su solución.

### Eliminado

- `software/launcher/teknoparrot_plugin.py` y la plataforma
  `teknoparrot` de `config/config.json` / `panel_database.json`.

### Pendiente

- Emparejar el Wiimote por Bluetooth y montar la barra de sensor IR
  (ya adquirida) para usarlo como pistola en el panel Zombies.
- Asignar un UID de tag NFC real al panel de HOTD 2 Remake.
- Diseño físico (OpenSCAD) del panel Zombies: pendiente, igual que en
  su día quedó pendiente el icono de TeknoParrot hasta tener una
  imagen de referencia — `openscad/parts/03_panels/nfc_panel_teknoparrot.scad`
  no se ha tocado en este ciclo.

---

## [1.1.4] - 2026-08-25 — Corregido: falso "tag_removed" con el panel puesto

### Encontrado

- Probando el Core por primera vez contra el ESP32 real (conectado y
  funcionando por USB), el usuario reportó: "cuando pongo el tag al
  poco me dice que el panel se ha retirado, pero el tag sigue
  presentado". Reproducible de forma consistente.

### Causa

- `hardware/rc522.cpp`, `Rc522Reader::update()`: tras cada lectura
  correcta del UID, se llamaba a `PICC_HaltA()` +
  `PCD_StopCrypto1()` — buena práctica habitual para liberar la
  tarjeta tras operaciones MIFARE autenticadas, pero innecesaria aquí
  (solo leemos el UID, sin autenticación ni lectura de bloques). El
  problema: una tarjeta en estado HALT no responde al comando REQA
  que usa `PICC_IsNewCardPresent()` en el siguiente sondeo — según
  ISO14443A, un HALT solo se despierta con WUPA. El resultado: el
  firmware dejaba de "ver" el tag nada más leerlo la primera vez, y a
  los 3 sondeos fallidos (`RC522_REMOVAL_THRESHOLD` × 
  `RC522_POLL_INTERVAL_MS` ≈ 450ms) disparaba `tag_removed` aunque el
  tag siguiera físicamente puesto.

### Corregido

- Eliminadas las llamadas a `PICC_HaltA()`/`PCD_StopCrypto1()` del
  ciclo de sondeo. Sin ellas, la tarjeta permanece en estado ACTIVE y
  responde con normalidad a los sondeos siguientes mientras siga
  presente; la detección de retirada real (tag físicamente quitado)
  no se ve afectada, ya que en ese caso `PICC_IsNewCardPresent()`
  falla igualmente por ausencia de tarjeta, no por su estado.
- Confirmado en hardware real (2026-08-25): tras reflashear, el tag
  permanece detectado sin `tag_removed` falso mientras sigue puesto.

---

### Encontrado

- Probando el firmware ya validado en hardware real (compila, flashea,
  arranca), la barra LED no encendía con ningún comando
  (`{"cmd":"led",...}`) a pesar de que la comunicación serie
  funcionaba bien (confirmado con `--echo` en el monitor de
  PlatformIO). El usuario desmontó el 74AHCT125 y conectó el ESP32
  directo a un tramo de prueba de 8 LEDs: encendió correctamente. Con
  el 74AHCT125 en el circuito, nada. Causa más probable: el pin de
  habilitación /1OE del chip (activo a nivel bajo) quedó flotante en
  vez de a GND — fallo típico con este componente, y que ya estaba
  anotado como punto a verificar en la lista de comprobación de
  `Hardware/Hardware_Connections.md` antes de este cambio.

### Decisión

- Se retira el 74AHCT125 del diseño por completo. La señal de datos
  del GPIO25 va directa a la WS2812B en lógica de 3.3V — la tira lo
  admite bien en el tramo probado. Si con la tira completa (más larga
  que el tramo de prueba) aparecen problemas de señal, se revisará si
  hace falta reintroducir un nivelador, esta vez verificando bien el
  cableado de /OE.

### Cambiado

- `Hardware/Hardware_Connections.md`: reescrita la sección de
  ESP32→WS2812B (ya no hay paso intermedio por el chip), eliminada la
  sección de desacoplamiento del 74AHCT125 (100nF, específica del
  chip — el condensador de 470-1000µF de la propia tira se mantiene,
  es independiente), actualizada la lista de componentes y el
  checklist de verificación.
- `firmware/src/config.h`, `firmware/README.md`, `GUIA_INICIO.md`,
  `docs/07_Hardware_Specification.md`: quitadas las referencias al
  74AHCT125 en el pinout, la tabla de alimentación y la solución de
  problemas.

### Sin tocar

- No existía ningún componente ni keepout del 74AHCT125 en el CAD
  (`openscad/`) — era solo un componente de cableado, sin geometría
  propia en el ensamblaje, así que no hizo falta ningún cambio ahí.

---

## [1.1.2] - 2026-08-18 — Segunda pared del canal LED, en L, para que la tira quede enfrentada al panel

### Encontrado

- El usuario señaló (con dos capturas, la primera descartada por él
  mismo) que el soporte de la tira LED no ofrecía una superficie
  donde pegarla mirando hacia el panel: la pared existente
  (`ledChannelWalls()`) es horizontal, con su cara ancha mirando en
  Z, no en Y — no hay dónde pegar la tira para que sus LEDs miren
  directamente a la franja del difusor.

### Añadido

- `ledChannelBackWall()` — segunda pared, conectada al borde más
  alejado del panel de la pared existente ("el final de la
  existente"), doblada 90° hacia abajo (perfil en L). Su cara
  interior mira hacia el panel (eje Y) — ahí se pega la tira LED,
  con los LEDs enfrentados directamente a la franja del difusor.
  Confirmado el diseño con el usuario mediante un render de la
  sección transversal antes de darlo por definitivo.
- `led_channel_backwall_thickness = 2.0mm` (ESTIMADO) y
  `led_channel_backwall_margin = 2.0mm` (ESTIMADO, cuánto baja por
  debajo del borde inferior de la franja del difusor) — pendientes
  de confirmar con la pieza impresa.

### Verificado

- Pieza completa: "Simple: yes" (2-manifold válido, misma
  comprobación robusta de siempre).
- Confirmado visualmente por render de sección transversal (antes de
  aplicar el cambio) y por render del panel completo (después).
- Ensamblaje: 28/28 sin colisión (sin cambios).

---

### Encontrado — mismo patrón que otros ajustes con la pared ya impresa

- El usuario mandó una foto del montaje real: el taladro de paso del
  panel queda claramente por encima del inserto real de la pared
  (ya impresa, fija). "Los agujeros de fijación en el panel interior
  están altos. Hay que bajarlos 3mm".
- `lower_panel_screw_z_low/high` las comparte TANTO la pared (el
  inserto real, `sideBossPad()` en `walls.scad`) COMO el panel (el
  taladro de paso, `lower_panel.scad`) — no se podían bajar
  directamente sin mover también la definición de la pared, que no
  puede cambiar (ya impresa).

### Cambiado

- Nuevas variables `lower_panel_hole_z_low`/`lower_panel_hole_z_high`
  (`assembly_positions.scad`), específicas del panel, calculadas
  como `lower_panel_screw_z_low/high - 3.0` — la pared se queda con
  su valor original (10, 29.5), sin tocar.
- `lower_panel.scad` (`lowerPanelScrewHoles()`) actualizado para
  usar las nuevas variables en vez de las compartidas con la pared.

### Verificado

- Valores confirmados por variables exportadas: pared sin cambios
  (10, 29.5), panel en (7, 26.5) — ambos dentro del rango del panel
  (0 a 51,5mm), sin riesgo de salirse por el borde inferior.
- Sin colisión con los huecos del OLED, el pulsador ni el USB
  frontal en la nueva posición.
- Ensamblaje: 28/28 sin colisión (sin cambios).

---

### Cambiado

- `nfc_panel_height`: 96,5 → 94,5mm — el usuario midió el chasis
  real: interior=145mm, panel inferior=50mm, panel NFC=96mm, suma
  146mm, superando el interior real en 1mm. Reducido 2mm para dejar
  margen de seguridad.

### Corregido — fallo propio detectado antes de dar el cambio por bueno

- El primer intento (solo cambiar `nfc_panel_height`) recortaba por
  la parte de ABAJO del panel (con `nfc_panel_margin_top=0`, la
  fórmula sube `nfc_panel_z_low` en vez de bajar `nfc_panel_z_high`)
  — habría abierto un hueco de 2mm entre el panel NFC y el panel
  inferior, justo la unión que debía quedarse fija. Corregido
  restaurando `nfc_panel_margin_top=2`, para que el recorte salga
  por ARRIBA (más margen frente al techo del chasis) y el borde
  inferior se mantenga en 51,5mm, sin cambios.

### Verificado

- `nfc_panel_z_low` confirmado sin cambios (51,5mm); `nfc_panel_z_high`
  confirmado en 146mm (2mm menos).
- Imanes (`nfc_magnet_z_low/high`, valores absolutos desde una
  corrección anterior) y hueco del tag NFC (`nfc_tag_pocket_z`,
  también absoluto) confirmados dentro del panel con margen amplio
  (25mm hasta el nuevo techo) — no dependen de la altura del panel,
  no necesitaron ningún ajuste.
- Los 3 paneles temáticos (Steam, RetroBat, TeknoParrot) y el panel
  en blanco (con el logo de TeknoParrot) siguen compilando
  correctamente. Confirmado visualmente por render: logo y texto de
  Steam dentro de los límites, nada cortado.
- Ensamblaje: 28/28 sin colisión (sin cambios).

---

## [1.0.10] - 2026-08-17 — Franja del difusor LED adelgazada a 1mm (la luz no atravesaba bien 3mm)

### Añadido

- `ledDiffuserThinCut()` (`lower_panel.scad`) — recorte real desde
  la cara trasera de la franja del difusor (antes solo existía
  `ledDiffuserZone()`, una zona de referencia para la vista previa
  de color, sin ningún recorte real — el panel impreso tenía el
  mismo grosor uniforme, 3mm, en toda su superficie). El usuario
  confirmó tras imprimirlo que ese grosor no dejaba pasar bien la
  luz de la tira LED.
- `led_diffuser_skin_thickness = 1.0mm` — grosor que queda en la
  cara frontal de la franja, por donde pasa la luz. El resto del
  panel (incluido el marco perimetral) mantiene los 3mm originales,
  sin tocar.

### Verificado

- Grosor real confirmado por sonda geométrica directa: exactamente
  1mm dentro de la franja del difusor, exactamente 3mm fuera de
  ella (marco y resto del panel).
- OpenSCAD confirma la pieza como "Simple: yes" (2-manifold válido,
  la misma comprobación robusta usada en todo el proyecto) — un
  aviso inicial de "no watertight" de una herramienta externa
  (trimesh) resultó ser un artefacto de su comprobación más
  estricta en los bordes propios del panel, no un problema real de
  impresión.
- Ensamblaje: 28/28 sin colisión (sin cambios).

---

## [1.0.9.1] - 2026-08-17 — Logo TeknoParrot integrado en nfc_panel_blank.scad, a escala reducida

### Cambiado

- `nfc_panel_blank.scad`: añadido el logo de TeknoParrot (mismos
  datos de contorno ya verificados en `nfc_panel_teknoparrot.scad`
  — un único polígono cerrado, sin auto-intersecciones), a una
  escala reducida (0,1487, frente a 0,2173 en el panel temático
  completo) y centrado verticalmente en el panel, no pegado al
  marco — para que ocupe "gran parte pero no toda" la superficie,
  según pidió el usuario. Deja ~14mm de margen visible arriba y
  abajo.
- El archivo sigue llamándose "blank" aunque ya no está vacío — el
  usuario pidió integrar el logo en este fichero concreto, no crear
  uno nuevo.

### Corregido

- Centrado vertical real corregido: la fórmula ingenua dejaba el
  resultado 5mm más arriba de lo previsto (la silueta del logo no
  es simétrica respecto a su propio origen, mismo tipo de ajuste ya
  visto con el logo de Steam) — corregido con un offset verificado
  por geometría exportada, centro real confirmado en Z=92,75.

### Verificado

- Centrado confirmado por coordenadas exportadas tras la
  corrección.
- Ensamblaje: 28/28 sin colisión (sin cambios).

---

## [1.0.9] - 2026-08-17 — Insertos sobrantes de la bandeja eliminados (petición del usuario)

### Eliminado

- `trayRearBridgeInserts()` y `trayRearBridgeInsertPads()`
  (`openscad/parts/01_bandeja/base.scad`) — los postes cilíndricos
  donde roscaban las lengüetas del panel trasero, ya eliminadas en
  la ronda anterior (1.0.8). El usuario confirmó que se quitaran
  también: "Elimina los insertos sobrantes de la bandeja".
- Variables asociadas eliminadas junto con los módulos
  (`rear_bridge_x_inset_local`, `rear_bridge_insert_diameter`,
  `rear_bridge_post_height`) — solo se usaban ahí.

### Verificado

- `base.scad` y `tray.scad` siguen compilando correctamente.
- La bandeja completa sigue siendo watertight y una sola pieza.
- Confirmado por sonda directa: cero material por encima del
  grosor base de la bandeja en la posición exacta donde estaban los
  postes cilíndricos.
- Sin referencias sueltas a los módulos eliminados en ningún otro
  archivo del proyecto (solo comentarios informativos).
- Ensamblaje: 28/28 sin colisión (sin cambios).

---

### Eliminado

- **Lengüetas de unión con la bandeja** (`rearBridgeTab()`,
  `rearBridgeTabs()`, `rearBridgeScrewHoles()`) — el usuario las
  marcó directamente en una captura de su render: "sobran estos
  soportes, no son necesarios". El panel trasero se sujeta ahora
  **solo** con los tornillos M3 a las paredes laterales
  (`rearWallScrewHoles()`, ya verificados en rondas anteriores).

### Movido

- `rear_panel.scad` y su probeta (`probeta_panel_trasero.scad`):
  `openscad/parts/01_bandeja/` → `openscad/parts/03_panels/`
  (petición del usuario: encajaba conceptualmente mejor junto al
  resto de paneles, no con las piezas de la bandeja). Las rutas
  relativas de `include` no necesitaron ningún cambio (misma
  profundidad de carpeta).

### Actualizado — referencias en otros archivos

- Comentarios desactualizados corregidos en `assembly_positions.scad`,
  `walls.scad` y `base.scad` (rutas antiguas y menciones a las
  lengüetas ya eliminadas).
- `openscad/parts/02_chassis/checks/run_structure_checks.py`: ruta
  de `rear_panel.scad` actualizada a `03_panels` (el script en sí
  sigue sin mantenerse activamente, solo se corrigió la ruta para
  que no quede rota).

### Pendiente de confirmar por el usuario

- La bandeja (`base.scad`) conserva los insertos correspondientes
  (`trayRearBridgeInserts()`, `trayRearBridgeInsertPads()`) — no se
  pidió quitarlos explícitamente y no causan ningún problema (siguen
  siendo material sólido de apoyo), pero ya no tienen ningún
  tornillo real que rosque en ellos. Avisar si se quieren eliminar
  también.

### Verificado

- Panel trasero: sigue compilando correctamente tras quitar las
  lengüetas (2 volúmenes, igual que antes — los recortes de
  conectores). Confirmado visualmente por render: rectángulo liso,
  sin salientes laterales.
- Probeta: sigue watertight, un único cuerpo, tras la mudanza de
  carpeta.
- Ensamblaje: 28/28 sin colisión (sin cambios).

---

### Corregido — fallo propio de interpretación del CAD

- **Conector DC**: el usuario lo dibujó cuadrado en el DXF (4
  puntos, igual que todos los demás rectángulos — no una
  aproximación poligonal de un círculo, como sí eran las letras) —
  pero lo interpreté como redondo por costumbre ("conector DC =
  redondo"), sin fiarme del dato real. Corregido a cuadrado
  (10×10mm, `es_redondo=false`).

### Cambiado

- **Ancho del panel trasero**: mismo ajuste que los paneles
  frontales — 150 → 149mm (`rear_panel_width`, ahora en
  `00_parametros.scad` para compartirlo con la probeta). El usuario
  confirmó con la prueba física: encajaba bien ajustándolo desde la
  izquierda (lado USB), con ~1mm de sobrante por la derecha (lado
  DC) — coincide exactamente con el mismo exceso ya corregido en los
  paneles frontales.
- Probeta del panel trasero actualizada al mismo ancho (149mm) y con
  el conector DC ya corregido.

### Verificado — sin cambios necesarios

- Los tres sistemas de tornillo del panel trasero (a la pared:
  taladro 3,4mm + avellanado 6mm; a la bandeja: taladro 3,4mm +
  inserto en la bandeja con `insert_diameter`/`insert_depth`
  compartidos) ya estaban correctamente configurados para M3 desde
  antes — no ha hecho falta ningún cambio.

### Verificado

- Probeta: watertight, un único cuerpo, 149mm de ancho exacto,
  centrada en X=0,0.
- Confirmado visualmente por render: el conector DC es ahora un
  cuadrado real.
- Ensamblaje: 28/28 sin colisión (sin cambios).

---

### Cambiado

- `nfc_panel_width` y `lower_panel_width_oversize`: ajustados para
  que ambos paneles midan 149mm de diseño (antes 151mm) — confirmado
  con una probeta física impresa y medida con calibre por el
  usuario: a 151mm el panel real salía en 150mm, pero el hueco
  interior real del chasis medía solo 149mm (el panel real quedaba
  más ancho que el hueco). Una segunda probeta a 149mm de diseño
  salió en 149mm real exactos.
- **Nota sobre la merma**: no fue constante entre las dos pruebas
  (1mm la primera vez, 0mm la segunda) — pendiente de que el usuario
  confirme que 149mm encaja bien en la práctica.

### Encontrado y corregido — desajuste de los imanes, ya existente antes de este cambio

- Al revisar el efecto del cambio de ancho sobre los imanes, se
  encontró que el alojamiento del imán en el panel NFC **ya estaba
  desalineado 3mm** respecto al imán fijo de la pared, incluso a
  151mm — no es un fallo nuevo de esta ronda, sino una limitación ya
  aceptada en una ronda anterior (el alojamiento no puede llegar
  hasta la posición exacta de la pared sin salirse del borde del
  panel). Con el panel a 149mm, ese desajuste subía a 4mm (39% de
  solape entre los dos imanes de 8mm).
- `nfc_magnet_edge_margin`: 1,5 → 1,0mm (petición del usuario: "pon
  los encastres de los imanes lo más cercanos posible a los
  extremos, entre 1 y 1,5mm del borde") — sube el solape a ~46%,
  dejando exactamente 1mm de margen respecto al borde del panel.

### Verificado

- Anchos confirmados por variables exportadas: 149mm en ambos
  paneles.
- Taladros de tornillo del panel inferior: posición NO afectada por
  el cambio de ancho (`panelMountX()` depende de `case_width`, fijo,
  no del ancho del panel) — confirmado, sigue en X=70,5mm.
- Alojamiento del imán: confirmado por geometría exportada, exactamente
  1mm de margen respecto al borde del panel (149/2 - 73,5 = 1,0).
- Hueco del tag NFC: sigue centrado en X=0,0, sin cambios (no depende
  del ancho).
- Los 3 paneles temáticos (Steam, RetroBat, TeknoParrot) y el panel
  en blanco siguen compilando correctamente, comparten esta misma
  base.
- Ensamblaje: 28/28 sin colisión (sin cambios).

---

### Cambiado

- El usuario aportó un dibujo real a escala en AutoCAD
  (`EXTERIOR.dxf`) con las medidas exactas de los 6 conectores
  traseros — sustituye las estimaciones basadas en la foto con
  regla de rondas anteriores.
- Unidades del archivo verificadas antes de usar los datos
  (INSUNITS=5, centímetros — factor ×10 a mm aplicado).
- Referencia Z verificada contra el valor que ya se usaba por
  estimación: casi exacta (0,36mm de diferencia), lo que dio
  confianza para usar las Z medidas directamente sin reajustar el
  origen del proyecto.
- **Confirma** el orden (USB-USB-RJ45-HDMI-HDMI-DC) y la orientación
  vertical del HDMI ya corregidos en rondas anteriores — ahora con
  tamaños y posiciones precisos en vez de estimados:
  - USB apilado: cada pareja es un ÚNICO recorte rectangular
    (15×16mm, así viene dibujado en el CAD) — ya no dos huecos
    individuales con `rear_usb_stack_pitch` estimado (parámetro
    eliminado).
  - RJ45: 16,5×13mm (antes 16×13,5, estimado — casi igual).
  - HDMI: 6,25×16mm de media (antes 6×15, estimado).
  - DC: 10mm de diámetro (sin cambios, coincidía).
  - Cada conector con su propia Z medida (RJ45 y DC ligeramente más
    bajos que USB/HDMI, según el CAD) — antes todos a una única Z
    estimada.
- `rear_connector_gap` eliminado (las posiciones ahora son
  coordenadas X directas medidas, no una fórmula de huecos
  acumulados).

### Verificado

- 7 volúmenes en el recorte aislado (6 conectores, el redondo cuenta
  doble por su geometría de baja resolución) — confirma que siguen
  bien separados, sin fusionarse.
- Ancho total real: 99mm, dentro del panel sin problema.
- Ensamblaje: 28/28 sin colisión (sin cambios).

---

### Encontrado — fallo propio de la corrección anterior (1.0.0)

- El usuario revisó `walls.scad` y vio que los alojamientos seguían
  sin parecer M3. Causa: al corregir esto en la ronda 1.0.0, usé un
  valor ESTIMADO propio (`lower_panel_screw_diameter = 6.5`) en vez
  de comprobar si ya existía un valor establecido en el proyecto —
  y sí existía: `insert_diameter = 4.10mm` (00_parametros.scad), que
  el panel trasero y la tapa superior ya usaban de forma consistente
  para sus propios insertos M3. Mi "corrección" había creado un
  TERCER valor distinto, inconsistente con el resto del proyecto.

### Cambiado

- `lower_panel_screw_diameter` ahora referencia directamente
  `insert_diameter` (4,10mm) en vez de un valor propio.
- `lower_panel_screw_depth` ahora referencia directamente
  `insert_depth` (5mm) — coincidía por casualidad con el valor
  anterior, pero ahora queda enlazado para que no se pueda
  desincronizar en el futuro.

### Verificado

- Coincidencia exacta confirmada por variables exportadas:
  `lower_panel_screw_diameter`, `rear_wall_screw_diameter` e
  `insert_diameter` son los tres 4,10mm; profundidades también
  coinciden (5mm).
- Ensamblaje: 28/28 sin colisión (sin cambios).

---

### Cambiado

- `rc522_connector_hole_x`: 20,0 → 25,3mm — el usuario indicó que el
  hueco debía quedar "alineado a la derecha del todo, pero sin
  invadir el marco lateral". Ahora el borde derecho del hueco
  coincide exactamente con el borde de la cavidad del lector
  (nfc_reader_width/2 + la holgura de encaje = 30,3mm), justo hasta
  donde empieza la pared estructural, sin tocarla.

### Verificado

- Posición del borde derecho confirmada por geometría exportada:
  30,3mm, coincide exactamente con el objetivo.
- El soporte sigue siendo una pieza sólida y conectada (2 volúmenes).
- Ensamblaje: 28/28 sin colisión (sin cambios).

---

### Añadido

- Nuevo orificio rectangular en la repisa trasera del soporte del
  RC522 (`rc522BracketCradle()`), por donde el lector apoya — la
  fila de pines de conexión del módulo sobresale por ese borde y
  quedaba bloqueada sin salida. Posición y tamaño marcados a mano
  por el usuario en una foto de la pieza real impresa.
- `rc522ConnectorCutout()`: nuevo módulo, con las medidas del hueco
  como parámetros claramente marcados ESTIMADO (calculados a partir
  de las proporciones visibles en la foto, no de una medida exacta
  del conector) — a revisar tras imprimir.

### Verificado

- El soporte sigue siendo una pieza sólida y conectada (2 volúmenes,
  igual que antes de añadir el hueco).
- Posición confirmada visualmente por render, coincide con la marca
  de la foto.
- Ensamblaje: 28/28 sin colisión (sin cambios).

---

### Encontrado — fallo real confirmado con fotos del montaje real

- El usuario mandó fotos del hub USB (CJMCU-204) montado en la
  pared real: dos postes (los de abajo) ya atornillados y
  correctos; los otros dos (arriba) no coinciden con los agujeros
  reales de la placa. Separación vertical real entre postes: 21mm,
  no los 36,1mm que calculaba el diseño.
- Encontrado y corregido un problema en mi primer intento: cambiar
  directamente `usb_hub_width` (para ajustar la separación) también
  habría encogido el tamaño físico modelado de la placa completa
  (se usa en `hub_usb.scad` para el cuerpo/keepout), no solo la
  posición de los postes — detectado antes de dar el cambio por
  bueno.

### Cambiado

- Nuevos parámetros `usb_hub_mount_inset_z` (11,55mm) y
  `usb_hub_mount_inset_y` (4mm, sin cambios) — separan el ajuste de
  la posición de los postes del tamaño físico de la placa
  (`usb_hub_width`/`usb_hub_depth`, que se quedan en 44,1×44,1mm,
  intactos).
- `hubMountBosses()` (walls.scad) y `hubUsbMountHoles()`
  (hub_usb.scad) actualizados para usar estos insets específicos por
  eje, en vez de un inset compartido de 4mm en ambos.

### Verificado

- Tamaño físico de la placa confirmado sin cambios: 44,1×44,1mm.
- Separaciones confirmadas por variables exportadas: 21mm vertical,
  36,1mm horizontal.
- Ensamblaje: 28/28 sin colisión (sin cambios).

### Pendiente

- Como con los tornillos M3 y los imanes: esta corrección es para
  futuras impresiones de la pared, no corrige la pieza ya impresa
  del usuario.

---

### Encontrado — fallo real de diseño, no solo del panel sino también de la pared ya impresa

- El usuario pidió que los orificios de sujeción del panel inferior
  fuesen M3. Al revisar, estaban dimensionados para M2 en TRES
  sitios: el taladro de paso del panel (2,2mm), el avellanado del
  panel (4,5mm) y el alojamiento del inserto térmico en la PARED
  (6mm, ya impresa). Los tres debían cambiar juntos — un tornillo M3
  no rosca en un inserto M2.
- Confirmado con el usuario: las paredes ya están impresas con el
  alojamiento M2 antiguo. El cambio queda para futuras impresiones
  propias o de otros usuarios, no corrige las paredes actuales.

### Cambiado

- `lower_panel_csk_radius`: 4,5/2 → 6,0/2mm — reutiliza el mismo
  valor que ya estaba establecido para M3 en el panel trasero
  (`rear_csk_radius`), para que sea consistente en todo el proyecto.
- Taladro de paso del panel: 2,2 → 3,4mm (holgura estándar M3).
- `lower_panel_screw_diameter` (alojamiento del inserto en la
  pared): 6,0 → 6,5mm — ESTIMADO, inserto térmico M3 típico de
  ~4-4,6mm de diámetro exterior, con margen similar al que ya tenía
  el M2.
- `lower_panel_screw_depth`: 4,0 → 5,0mm — ESTIMADO, los insertos M3
  suelen ser algo más largos que los M2.
- `lower_panel_csk_depth`: 1,4 → 1,6mm — ESTIMADO, cabeza M3 algo
  más gruesa que la M2; sigue dentro de los 3mm del panel.

### Verificado

- Sin colisión con el hueco del OLED ni con el del pulsador.
- Ensamblaje: 28/28 sin colisión (sin cambios).

---

### Cambiado

- Revisado el repositorio completo a petición del usuario ("¿puedes
  identificar qué ficheros sobran o están obsoletos?"). Movidos 7
  archivos a la nueva carpeta `obsoletos/` (estructura original
  preservada en subcarpetas, con un README explicando cada uno):
  - `front_panel.scad`, `front_layout.scad` — ya marcados ⚠️
    OBSOLETO desde antes, sin referencias reales.
  - `rc522_bracket.scad` (v1.0, renombrado a
    `rc522_bracket_v1.scad`) — duplicado huérfano de la v2.0 en
    `04_soportes`, con el taladro mal orientado.
  - `virtual_assembly_v1.scad`, `front_panel_view.scad`,
    `chassis_layout.scad`, `um790_reference.scad` — herramientas de
    la fase de planificación previa al chasis actual, sin
    referencias `use`/`include` reales desde ningún archivo activo.
- `openscad/parts/02_chassis/checks/run_structure_checks.py` se
  queda en su sitio (no es un duplicado, pero está desactualizado —
  ver README de `obsoletos/`).

### Verificado

- Ninguna referencia `use`/`include` real hacia los 7 archivos
  movidos (comprobado antes de mover, no solo después).
- Ensamblaje: 28/28 sin colisión, sin cambios tras el traslado.

---

### Añadido

- `nfc_panel_blank.scad`: panel NFC sin ninguna marca, reutilizando
  `nfcPanelBase()` tal cual — pedido del usuario para poner su propio
  diseño directamente desde Anycubic Slicer (tras descartar tanto el
  grabado de detalle como la separación por regiones de color para
  TeknoParrot).

### Verificado

- Ensamblaje: 28/28 sin colisión (sin cambios).

---

### Cambiado

- Sustituida la silueta del logo (derivada de una foto de una pieza
  física) por una nueva, medida sobre `teknoparrot-logo.svg`
  aportado por el usuario — un diseño a color de líneas limpias
  (aunque el SVG en sí envuelve una imagen PNG incrustada, no rutas
  vectoriales puras, la imagen es mucho más limpia que la foto
  anterior). Medido por el mismo método de análisis de contorno
  (máscara por canal alfa + simplificación de polígono), un único
  contorno cerrado válido (verificado con `shapely`, sin
  auto-intersecciones).
- Escala ajustada para ocupar gran parte del panel (altura útil
  completa, ~63,5mm de ancho resultante), según pidió el usuario.
- Eliminado el intento fallido de grabado de detalle de la ronda
  anterior (`teknoparrotDetail2D()`, el SVG vectorizado desde la
  foto que CGAL rechazaba en cualquier operación booleana) — ya no
  aplica, era específico del logo antiguo. Limpiado el comentario
  obsoleto y borrado el SVG huérfano
  (`openscad/assets/teknoparrot_detail.svg`).

### Verificado

- Centrado confirmado por coordenadas exportadas (desviación mínima,
  -0,87mm) y toca justo el límite superior del marco (Z=142).
- Sin colisión real con el marco elevado.
- Ensamblaje: 28/28 sin colisión (sin cambios).

---

### Cambiado

- **Cruz central horizontal**: altura rebajada 3mm (5 → 2mm),
  igualada a la del "Horizontal superior" (ya rebajado en 0.9.3) —
  el usuario lo marcó tras montar la bandeja real impresa, tocando
  la parte inferior del UM790.

### Verificado

- Altura real confirmada por geometría exportada: 2mm (antes 5mm),
  igual que el horizontal superior.
- La bandeja sigue siendo una sola pieza conectada: watertight, un
  único cuerpo.
- Ensamblaje: 28/28 sin colisión (sin cambios).

---

### Encontrado — mismo tipo de fallo que los imanes (0.9.4), detectado a tiempo

- El usuario preguntó si el hueco del llavero seguía alineado con el
  lector RC522 tras los cambios de altura del panel. Comprobado:
  tanto `rc522_pos[2]` (posición del lector) como el centro Z del
  hueco del tag (`nfcTagPocket()`) usaban `nfc_panel_z_mid` — al
  ampliar la altura del panel, ese valor pasó de 93,75 a 99,75mm
  (6mm de desajuste).
- El soporte del lector (`openscad/parts/04_soportes/rc522_bracket.scad`,
  con bastante historial de ajustes ya confirmados por el usuario)
  **ya está impreso** con la posición antigua.

### Cambiado

- `rc522_pos[2]` y el nuevo `nfc_tag_pocket_z` (en `nfc_panel.scad`)
  fijados al mismo valor absoluto (93,75mm), independiente de
  `nfc_panel_z_mid` — igual que se hizo con los imanes en 0.9.4.

### Verificado

- Coincidencia exacta confirmada por variables exportadas de ambos
  archivos por separado: 93,75mm en los dos.
- Soporte RC522 (04_soportes) sigue compilando correctamente.
- Ensamblaje: 28/28 sin colisión (sin cambios).

---

### Encontrado — fallo real, detectado a tiempo antes de imprimir

- Buena pregunta del usuario tras las rondas de ajuste del panel
  NFC. Al ampliar `nfc_panel_height` 12mm (rondas 0.9.0+), tanto
  `front_magnet_z_high` (en `walls.scad`, la pared YA IMPRESA) como
  `nfc_magnet_z_high` (en `nfc_panel.scad`) se calculaban a partir de
  `nfc_panel_z_high` — al cambiar ese valor, AMBOS se recalcularon
  automáticamente a la vez, pasando de Z=121 a Z=133.
- El problema: la pared real, ya impresa, tiene el imán físicamente
  fijo en Z=121 — no puede "recalcularse". Mi archivo de la pared, al
  compartir la fórmula, mostraba una posición que ya no coincide con
  la pieza física real.

### Cambiado

- Ambos valores fijados a constantes absolutas (66,5 y 121mm),
  independientes de la altura del panel — coinciden exactamente con
  la posición real de los imanes en la pared ya impresa.
- Afecta a los 3 paneles NFC (Steam, RetroBat, TeknoParrot), que
  comparten `nfc_magnet_z_low/high` a través de `nfcPanelBase()`.

### Verificado

- Coincidencia exacta confirmada por variables exportadas de ambos
  archivos por separado: 66,5 y 121mm en los dos.
- Ensamblaje: 28/28 sin colisión (sin cambios).

---

### Cambiado

- `rib()` (módulo genérico de nervios) admite ahora un parámetro de
  altura opcional, con el valor global (`rib_height`) como valor por
  defecto — permite rebajar nervios concretos sin afectar al resto.
- **Horizontal superior** y **Cruz central vertical**: altura
  rebajada 3mm (5 → 2mm) — el usuario los señaló directamente en dos
  capturas de su laminador (necesitó una segunda captura más clara
  tras una primera identificación ambigua por mi parte), confirmando
  que tocan el disipador inferior del UM790.

### Verificado

- Altura real confirmada por geometría exportada: 2mm en ambos
  nervios (antes 5mm), en toda su extensión.
- La bandeja sigue siendo una sola pieza conectada: watertight, un
  único cuerpo.
- Ensamblaje: 28/28 sin colisión (sin cambios).

---

### Corregido — fallo propio en la ronda anterior

- La corrección anterior (0.9.1) eliminó el nervio interior
  ("Horizontal inferior", parte de la cruceta central) — pero el
  usuario señaló con una captura que la pieza que realmente choca
  con el USB interno y el pulsador es el **tramo delantero del
  marco exterior** (el borde más externo de la bandeja, no un nervio
  interior). Aclarado por el usuario: "el que está más al exterior".
- Recortado ese tramo específico (el resto del marco — trasero,
  izquierdo, derecho — sigue intacto). El nervio interior eliminado
  en la ronda anterior se queda igual (fuera), ya que no hay
  indicación de que deba recuperarse.

### Verificado

- La bandeja sigue siendo una sola pieza conectada: watertight, sin
  aristas problemáticas, un único cuerpo (`body_count=1`).
- Confirmado visualmente por render en planta: el marco queda
  abierto por el lado delantero, resto de la estructura intacta.
- Ensamblaje: 28/28 sin colisión (sin cambios).

---
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

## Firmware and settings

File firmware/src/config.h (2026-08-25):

// SteamMachine UM790 - Firmware ESP32
//
// config.h
//
// Configuracion centralizada (05_Firmware_Architecture.md, seccion
// "Configuracion"). Ningun otro fichero debe tener numeros de pin o
// timings sueltos: todo pasa por aqui.
//
// PINOUT: fijado por el diseno electronico real del proyecto (no ya una
// propuesta de partida). El resto de GPIO del ESP32-WROOM-32D DevKit
// (HW-394) quedan reservados sin asignar todavia.
//
// Alimentacion (referencia, no afecta al codigo pero conviene tenerlo
// documentado junto al pinout):
//   3V3          -> RC522 + OLED
//   VIN (~4.68V)  -> WS2812B
//   GND           -> masa comun
//
// El pin de datos de la barra LED (GPIO25) va DIRECTO a la WS2812B, en
// logica de 3.3V (sin nivelador). El diseno original preveia un
// 74AHCT125 (3.3V->5V) de por medio, pero se retiro (2026-08-25) tras
// comprobar en un tramo real de 8 LEDs que la tira funciona bien sin
// el: con 8 LEDs conectados directamente al ESP32 encendio
// correctamente, mientras que con el 74AHCT125 en el circuito no
// encendia nada (causa mas probable: el pin /1OE del chip quedo
// flotante). Si en el futuro la tira completa (mas larga) diera
// problemas de senal, revisar si conviene reintroducir un nivelador
// bien cableado.

#pragma once

// ---------------------------------------------------------------------
// Puerto serie (protocolo con el PC) - docs/04_Communication_Protocol.md
// ---------------------------------------------------------------------
#define SERIAL_BAUDRATE 115200

// Canal de depuracion opcional, NUNCA el mismo puerto USB que el protocolo.
// Activar con build_flags -DDEBUG_SERIAL2=1 (ver platformio.ini).
// Pin todavia no asignado en el diseno electronico real: valor provisional.
#define DEBUG_SERIAL2_RX_PIN 16
#define DEBUG_SERIAL2_TX_PIN 17
#define DEBUG_SERIAL2_BAUDRATE 115200

// ---------------------------------------------------------------------
// RC522 (lector NFC) - SPI. Alimentacion: 3V3.
// ---------------------------------------------------------------------
#define RC522_SCK_PIN 18
#define RC522_MISO_PIN 19
#define RC522_MOSI_PIN 23
#define RC522_SS_PIN 5    // SDA/SS
#define RC522_RST_PIN 27

// Ciclo de sondeo del RC522 (no bloqueante, ver core/scheduler.h)
#define RC522_POLL_INTERVAL_MS 150
// Nº de sondeos consecutivos sin tarjeta antes de considerar "tag_removed".
// El RC522 no tiene interrupcion de retirada; se infiere por ausencia.
#define RC522_REMOVAL_THRESHOLD 3

// ---------------------------------------------------------------------
// OLED - I2C (0.96" SSD1306, 128x64 tipico para esta zona visible).
// Alimentacion: 3V3.
// ---------------------------------------------------------------------
#define OLED_I2C_SDA_PIN 21
#define OLED_I2C_SCL_PIN 22
#define OLED_I2C_ADDRESS 0x3C
#define OLED_WIDTH 128
#define OLED_HEIGHT 64

// ---------------------------------------------------------------------
// Barra LED (WS2812B via FastLED). Dato del ESP32 (3.3V) directo a la
// WS2812B, sin nivelador (ver nota arriba) — alimentada por VIN.
// ---------------------------------------------------------------------
#define LED_DATA_PIN 25
#define LED_COUNT 8            // Dato real confirmado por el usuario (2026-08-25) — antes 12 (placeholder)
#define LED_DEFAULT_BRIGHTNESS 128
#define LED_UPDATE_INTERVAL_MS 16   // ~60 fps para las animaciones

// ---------------------------------------------------------------------
// Pulsador iluminado antivandalico (16mm)
//
// GPIO13: confirmado en hardware real (2026-08-25) — funciona
// correctamente. No estaba en la tabla de pines fijados por el diseno
// electronico original (esos GPIO quedaban "reservados"); se eligio
// evitando los ya ocupados y los de arranque/strapping (0, 2, 12, 15)
// y los de solo-entrada (34-39). Ya no es provisional.
// ---------------------------------------------------------------------
#define BUTTON_PIN 13
#define BUTTON_ACTIVE_LOW true
#define BUTTON_DEBOUNCE_MS 40

// ---------------------------------------------------------------------
// Zumbador (futuro, ver docs/04, "Zumbador (futuro)").
// Igual que el boton: GPIO todavia sin fijar en el diseno electronico,
// valor provisional evitando los pines ya ocupados.
// ---------------------------------------------------------------------
#define BUZZER_PIN 26

// ---------------------------------------------------------------------
// Watchdog
// ---------------------------------------------------------------------
#define WATCHDOG_TIMEOUT_MS 5000

// ---------------------------------------------------------------------
// Firmware
// ---------------------------------------------------------------------
#define FIRMWARE_VERSION "1.0.0"

// Tamano maximo de una linea de comando entrante (JSON) por Serial.
#define SERIAL_LINE_BUFFER_SIZE 256

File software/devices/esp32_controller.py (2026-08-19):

#
# SteamMachine UM790
#
# devices.esp32_controller
#
# Oculta completamente el protocolo serie (04_Communication_Protocol.md).
# El resto del software nunca accede directamente al puerto serie.
#

from __future__ import annotations

from typing import Optional

from core.events import Event, EventManager
from core.logger import get_logger
from devices.serial_manager import SerialManager, SimulatedSerialManager

logger = get_logger()


class ESP32Controller:
    """
    API de alto nivel hacia el ESP32. Traduce eventos ESP32 -> PC al
    EventManager, y expone comandos PC -> ESP32 como metodos Python.
    """

    def __init__(self, config, event_manager: EventManager):
        self._config = config
        self._events = event_manager

        simulate = config.get("serial.simulate", True)
        if simulate:
            self._serial = SimulatedSerialManager(on_message=self._on_message)
        else:
            self._serial = SerialManager(
                port=config.get("serial.port", "auto"),
                baudrate=config.get("serial.baudrate", 115200),
                vid_pid=config.get("serial.esp32_vid_pid", []),
                reconnect_interval=config.get("serial.reconnect_interval_seconds", 3),
                on_message=self._on_message,
            )

    # -- Ciclo de vida ---------------------------------------------------

    def connect(self) -> bool:
        return self._serial.connect()

    def disconnect(self) -> None:
        self._serial.disconnect()

    def is_connected(self) -> bool:
        return self._serial.is_connected()

    @property
    def simulated(self) -> bool:
        return isinstance(self._serial, SimulatedSerialManager)

    def inject_simulated_event(self, message: dict) -> None:
        """Solo tiene efecto en modo simulado; ver SimulatedSerialManager.inject()."""
        if isinstance(self._serial, SimulatedSerialManager):
            self._serial.inject(message)

    # -- Comandos PC -> ESP32 (04_Communication_Protocol.md) ------------

    def oled(self, text: str) -> None:
        self._serial.send({"cmd": "oled", "text": text})

    def oled_lines(self, line1: str, line2: str) -> None:
        self._serial.send({"cmd": "oled2", "line1": line1, "line2": line2})

    def clear_oled(self) -> None:
        self._serial.send({"cmd": "oled_clear"})

    def set_led(self, color: str) -> None:
        self._serial.send({"cmd": "led", "color": color})

    def set_brightness(self, value: int) -> None:
        value = max(0, min(255, value))
        self._serial.send({"cmd": "brightness", "value": value})

    def animation(self, name: str) -> None:
        self._serial.send({"cmd": "animation", "name": name})

    def restart(self) -> None:
        self._serial.send({"cmd": "restart"})

    def request_status(self) -> None:
        self._serial.send({"cmd": "status"})

    # -- Eventos ESP32 -> PC ---------------------------------------------

    def _on_message(self, message: dict) -> None:
        event = message.get("event")

        if event == "boot":
            self._events.publish(Event.BOOT, firmware=message.get("firmware"))
        elif event == "tag":
            self._events.publish(Event.TAG_DETECTED, uid=message.get("uid"))
        elif event == "tag_removed":
            self._events.publish(Event.TAG_REMOVED)
        elif event == "button":
            self._events.publish(Event.BUTTON)
        elif event == "error":
            self._events.publish(Event.ERROR, code=message.get("code"))
        elif event == "status":
            logger.info("Estado ESP32: {}", message)
        else:
            logger.warning("Evento ESP32 desconocido: {}", message)

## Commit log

2026-07-22 Add parameters for SteamMachine UM790
    Defines all project dimensions and parameters for the SteamMachine UM790.
    [00_parametros.scad]
2026-07-22 Add helper modules for OpenSCAD
    This file contains various helper modules for OpenSCAD, including functions for creating centered cubes and cylinders, mirroring, and positioning elements in a 2D array or circular pattern.
2026-07-22 Add OpenSCAD model for UM790 hardware components
    This file contains the OpenSCAD model definitions for various hardware components used in the SteamMachine UM790 project, including PCB, cooler, connectors, and other peripherals.
2026-07-22 Refactor magnet module and update version to 1.1
2026-07-24 Add base island size and bridge width parameters
    [00_parametros.scad]
2026-07-24 Add base structure for Steam Machine project
    This file defines the structural base for the Steam Machine project, including the outer contour, inner window, structural islands, and bridges.
    [base.scad]
2026-07-24 Create posts module for Minisforum UM790 Pro
    Added a new module for creating individual posts and a set of posts for the Minisforum UM790 Pro.
    [posts.scad]
2026-07-24 Refactor post module and improve post placement
    [posts.scad]
2026-07-24 Add parameters for UM790 PRO specifications
    [00_parametros.scad]
2026-07-24 Add preview_posts.scad with base and posts includes
    [preview_posts.scad]
2026-07-24 Update ribs.scad to version 2.0 with improvements
    [ribs.scad]
2026-07-27 Add new parameters for rib and insert dimensions
    [00_parametros.scad]
2026-07-27 Refactor rib modules and improve rib assembly
    [ribs.scad]
2026-07-27 Refactor tray module and update structure
    [tray.scad]
2026-07-27 Update version and modify cylinder translations
    Updated version number from 2.0 to 2.1 and adjusted cylinder translations in the posts module.
    [posts.scad]
2026-07-27 Update base.scad to version 5.0 with enhancements
    [base.scad]
2026-07-31 Comment out insert_depth assignment
    [00_parametros.scad]
2026-07-31 Update base.scad for version 8.0
    Refactor base module to improve structure and add support islands.
    [base.scad]
2026-07-31 Simplify preview condition for base color
    [base.scad]
2026-07-31 Add chassis_lower module for chassis design
    Define the lower chassis module with floor and outline.
    [chassis_lower.scad]
2026-08-01 Add front panel design in front_panel.scad
    [front_panel.scad]
2026-08-19 Rename DESIGN_RULES.md to 01 – Design Rules
2026-08-19 Rename Virtual Assembly Report file
2026-08-19 Rename nfc_panel_blank (4).stl to nfc_panel_blank.stl
    [nfc_panel_blank.stl]
2026-08-25 Pulsador trasero, canal LED rediseñado, brida OLED
    [assembly_instances.scad, assembly_positions.scad, chassis_lower.scad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]
2026-08-25 Pruebas de comunicación finalizadas
2026-08-26 Instalación de TecknoParrot
2026-08-29 STLs actualizados
    [Gung.stl, Parrot.stl, Retrobat.stl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]
2026-08-29 Actualización Estado STL
2026-08-30 Actualización Rear panel
    [rear_panel.stl, rear_panel_horizontal.stl]
2026-09-03 Chasis desmontable
    [floor_flat (1).stl, floor_flat.scad, foot.scad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]
2026-09-07 Actualización changelog
    [lower_panel.scad]
2026-09-08 Actualización chasis por piezas
    [assembly_positions.scad, floor.scad, foot.scad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]
2026-09-08 Base insertos
    [floor.scad]
2026-09-08 Actualización documentación y STL
    [floor.scad, floor_flat.stl, leftwall_flat.stl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]
2026-09-08 Eliminados dos ficheros obsoletos
    [floor.stl, floor_flat (1).stl]
2026-09-12 Documentación actualizada
    [assembly_positions.scad, floor.scad, floor.stl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]
2026-09-24 Actualizaciones varias
    [Apagar.stl, Mando.stl, caja_nfc_panel.scad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]
2026-10-05 Sustituir hub USB CJMCU-204 por placa 4x USB-A en la pared derecha
    Placa 68,7 x 18,2 mm en horizontal, bocas USB-A hacia arriba (centro
    Y=0, Z=82). Postes M2 de 5 x 4 mm a 64,7 x 14,2 mm con piloto de 1,8.
    Regenerado rightwall_flat2.stl; 28/28 pares sin colisión.
    Claude-Session: https://claude.ai/code/session_016uvGmCcWto8skydHLMTCN1
    [00_parametros.scad, assembly_positions.scad, hub_usb.scad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]
2026-10-05 Prolongar el rebaje de los imanes frontales por la pared lateral
    El alojamiento del imán quedaba solo en el relleno; ahora continúa por
    la pared desde el borde frontal, como en el leftwall_flat2.stl de
    referencia. Regenerado rightwall_flat2.stl.
    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
    [rightwall_flat2.stl, walls.scad]
2026-10-14 Corregir separación de taladros del hub a 68 mm (medida real)
    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
2026-10-14 CHANGELOG: separación de taladros del hub corregida a 68 mm
    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
